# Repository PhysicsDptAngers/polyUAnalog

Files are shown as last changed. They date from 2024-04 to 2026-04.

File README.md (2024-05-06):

# polyUAnalog: A Polyphonic Analogic and *Open Source* Synth

## Project Overview

The architecture of polyUAnalog centers around a simple design: a *conductor board* orchestrating multiple *voice boards*. This modular approach allows each board to function independently as a monophonic synthesizer. When combined under the guidance of the conductor board, they form a versatile polyphonic synthesizer capable of operating in various modes:

- **Polyphonic Mode**: Achieve polyphony with up to virtually 120 voices. Our current configuration supports 10 voices of polyphony, tested and functioning seamlessly.
- **Monophonic with Unison and Spread Mode**: For those moments when a single, powerful voice is needed, enhanced with unison and spread capabilities for added depth.
- **Multi-timbral Mode** (Under development as of April 2024): Expanding the synth's versatility by allowing multiple timbres to be played simultaneously.

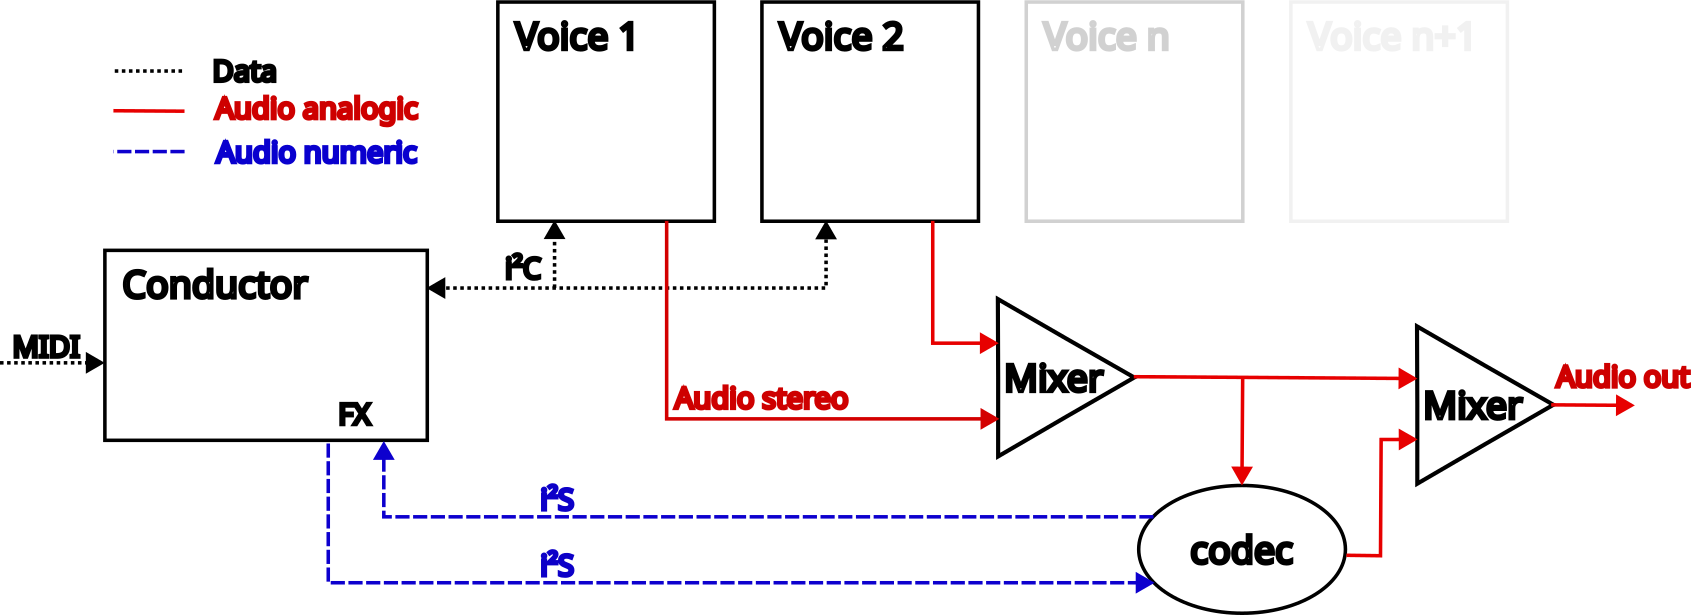
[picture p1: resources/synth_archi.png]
PolyUAnalog Synth


## Repository Structure

The `polyUAnalog` repository is organized into two main directories, `firmware` and `hardware`, each containing subdirectories dedicated to different components of the synth:

### Firmware
Contains all necessary code to bring the polyUAnalog to life. This includes the microcontroller programming for voice and conductor boards, as well as the controller interface.

- **Voice Board**: The soul of the polyUAnalog's sound, each voice board is an independent monophonic synthesizer.
- **Conductor Board**: The brain behind the operation, orchestrating the voice boards to work in harmony.
- **Controller**: Interface and panel design for hands-on control of the polyUAnalog.

### Hardware
Detailed schematics, PCB designs, and everything required to physically construct the polyUAnalog synth.

- **Voice Board**: Designs and instructions to build each monophonic voice board.
- **Conductor Board**: The blueprint for constructing the central conductor board.
- **Controller**: Panel design and schematics for the physical user interface.

For specific details on each component, please refer to the corresponding `README.md` file within its directory. Our aim is to make the assembly and understanding of the polyUAnalog as accessible as possible.

## Contributing

polyUAnalog thrives on community input and collaboration. Whether you're a seasoned electrical engineer, a software developer with a knack for DSP, or an enthusiast eager to learn and explore, your contributions are welcome. 

## Academic Research and Publications

We have documented our journey and findings in a comprehensive academic paper. This paper delves into the theoretical underpinnings, design choices, and technical challenges encountered during the development of polyUAnalog. While the paper is currently in draft form and distributed as-is, we believe it provides valuable insights into the project's scientific and engineering aspects.

A DOI and access to the official publication will be provided upon acceptance. Additionally, a pre-print version of the paper will be made available to ensure our findings are accessible to the community, fostering further research and development in the field of analog synthesis.

## Sound Examples

We are currently compiling a diverse range of audio samples to showcase the versatility and musicality of polyUAnalog. This is a work in progress, and we appreciate your patience as we curate a collection that truly represents the essence of this project.

Stay tuned for a SoundCloud link, which will be shared here soon. 

## Project Progress

| Task | Description | Status |
|---|---|---|
| Documenting | Drafting an explanation of the synth's electronics and detailing the functionality of the code. | #c5f015 In Progress |
| Multitimbral | Add multitimbral capability by adapting the software.  | #00FF00 Almost OK ! |
| Faster PID | Transitioning from the hardware RC-based Timer of the RP2040 to the PIO ones to achieve a faster response time of the DCO waveform. | #f03c15 Testing |
| Conductor board | Design and finalize the electronic, PCB, and firmware layout for the conductor board, which enables the control of voice cards, connects to an FX board, and one or multiple controllers.| #1589F0 Pending |
| FX Loop | Testing the V4220 codec chip.| #1589F0 Pending |
| Controler | Finishing the first controler : the "basic synth" | #1589F0 Pending |
| Continous waveform for the DCO | Produce waveform in between saw and triangle and modulate it | #1589F0 Pending |
| Finishing the paper | Last measurements still to be done | #1589F0 Pending |

## License

polyUAnalog is open source and distributed under the MIT License.

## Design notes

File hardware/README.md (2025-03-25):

## Hardware Components of the polyUAnalog System

- **Voice Board**: This is the core component of the project. A voice board is, by itself, an analog monophonic synthesizer. In short, the sound is generated by the AS3397 chip, controlled by an RP2040/RP2530 (Raspberry Pi Pico) microcontroller.

- **Conductor Board**: All voice boards are connected to the conductor board. It receives commands from external sources in MIDI-compatible format and distributes them to the voice boards via the I²C bus.

- **Controller Board**: These are the interface panels of the synthesizer. They typically include potentiometers, encoders, LEDs, and screens used to program and control the synthesizer. The corresponding data is sent to the conductor board via the I²C bus.

- **Power Board**: The synthesizer requires three power rails to operate (+12V, +5V, -5V). We provide a simple design using a USB Type-C power block with Power Delivery support to supply a regulated +12V rail. The +5V and -5V rails are then generated using buck converters.

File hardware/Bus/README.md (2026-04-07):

# BUS Card

## Overview
The **BUS Card** is the interface designed to link multiple voice boards to the Conductor module. 

- **Capacity:** Each BUS board supports up to 4 voice boards.
- **Mounting:** Voice cards are mounted vertically to optimize space.

## Connectivity & Expansion
You can daisychain multiple BUS boards using two different methods:
1. **Ribbon Cable:** Use a standard 2x5 (2.54mm pitch) connector, similar to Eurorack power cables.
2. **Tiling:** Align the boards side-by-side and solder the dedicated edge pads for a rigid connection.

## Input Connector
The pinout and format of the input connector are detailed in the following diagram:

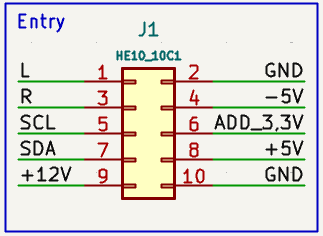
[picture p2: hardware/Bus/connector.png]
Connector Pinout


## I2C Addressing
The I2C address is determined by the voltage level at the `ADD_3.3` pad. 

To configure the addressing:
- Install resistors in series between each card.
- Connect the resistor pin of the first card to **GND** (Ground) to complete the voltage divider.
- The resulting voltage drop across the chain assigns a unique hardware address to each board.

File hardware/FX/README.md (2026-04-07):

## FX Board

We designed an optional, dedicated FX card based on the **RP2350** microcontroller to handle digital effects. This board connects to the conductor board via a standard 2x5 pin header. Audio input and output data transfer relies on the **I2S protocol**, implemented utilizing the RP2350's Programmable I/O (PIO) blocks.

To accommodate different budgets and assembly constraints, the card supports three ADC and DAC configurations:

* The first approach uses the RP2350's **built-in ADC** paired with a $2 \times 8$-bit PWM-RC filtered DAC for the output.
* The second option employs inexpensive, off-the-shelf **I2S ADC (PCM1808) and DAC (PCM5102A)** modules. While we have included the footprints on the PCB to allow for discrete mounting or to future-proof against discontinued supply, we strongly recommend using the modules themselves.
* The third configuration integrates the **Coolaudio V4220 codec**. This recent and cost-effective chip comes in an SSOP-28 package, making it significantly easier to hand-solder than the QFN packages typical of modern audio codecs. It is worth noting that the V4220 datasheet is poorly documented, as it confusingly mixes specifications from the original Cirrus Logic CS4220 and CS4221 chips it is based on.

PCM5102a I2S DAC Module
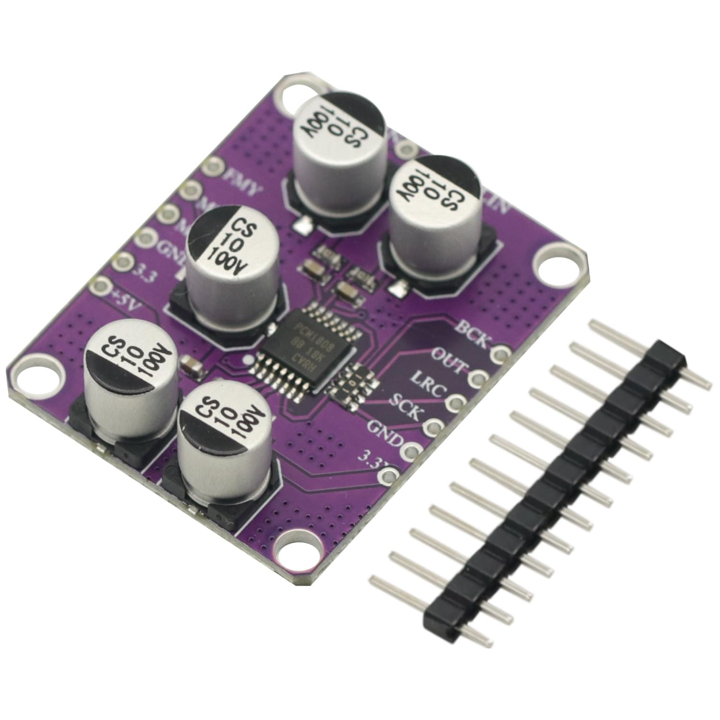
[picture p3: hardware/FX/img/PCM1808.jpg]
PCM1808 I2S ADC Module


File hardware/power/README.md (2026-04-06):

## Power Supply Architecture

The synthesizer requires three voltage rails for proper operation:

- **+12V** rail for the AS3397 chip  
- **+5V** rail for the microcontrollers, various digital ICs, and as the positive supply for the operational amplifiers (OpAmps)  
- **−5V** rail required by the AS3397 and as the negative supply for the OpAmps  

Several strategies have been considered for implementing the power supply. 

In the proposed design, we use a USB-C power supply unit that supports Power Delivery (PD) mode to provide a stable 12V/5A rail. 
	
A buck converter based on the TPS5430 chip, that can easily be obtained as an affordable off-the-shelf module, is used to generate the \SI{+5}{\volt} and \SI{-5}{\volt} rails. With a \SI{3}{\ampere} capacity, this setup is more than sufficient to power both the conductor board and the various voice boards.

Alternative configurations have also been explored:

- In early prototypes, a **compact ATX power supply** was used for +12V and +5V in combination with a **7805** regulator to generate the −5V rail.  
- In the **monophonic version**, the system is powered from a **standard 12V wall adapter** (or a USB-C PD unit), with a 7805 regulator providing the +5V rail, and **charge-pump circuits** used to derive the −5V rail.

Other solutions, such as **off-the-shelf AC-DC modules** from manufacturers like **Meanwell**, may also be considered for increased robustness and ease of integration — particularly when direct connection to the mains is desirable.

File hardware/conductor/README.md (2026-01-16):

# Conductor Card

The *Conductor Card* serves as the central hub for the synthesizer, managing communication, power distribution, and analog signal summing. Its architecture is designed to interface external controls with internal voice modules.

## Key Functionalities

### 1. Data I/O & Connectivity

The card manages multiple communication protocols to interface with the outside world:

* **MIDI:** Standard MIDI IN port and an optional MIDI OUT header.
* **I2C**:
	* Dedicated header for optional *"Controllers"* (e.g., a front panel equipped with knobs and sliders for real-time parameter control).
	* Dedicated header for optional *"FX card"*
* **Wireless (UDP):** Support for UDP over Wi-Fi when utilizing a *Raspberry Pi Pico 2 W*.
* **Storage:** Integrated SD card slot for storing and retrieving presets and system data.

### 2. Voice Dispatch & Power Distribution

The Conductor Card serves as the central interface for system data and power management:

* **Power Input:** Features a dedicated input port for the main power rails (*+12V, -12V, +5V*).
* **Power Routing:** Distributes stable power rails from the main input to all connected internal modules and voice cards.
* **Signal Dispatch:** Routes digital control data—including **Note On/Off, MIDI CC, and Clock** signals—to the individual voice cards via the *I2C bus*.

### 3. Analog Signal Processing & Mixing

The card features a dedicated analog summing stage to consolidate the synthesizer's output:

* **Current-to-Voltage Conversion:** Collects the current outputs from the *AS3397-based voice cards* via a Trans-Impedance Amplifier (TIA).
* **FX Integration:** Bi-directional interfacing with an optional FX card (Send/Return or post-summing injection).
* **Final Mix:** Sums the voice signals with the FX return to produce the final audio output.

## Connectors Pinouts

### 1. Voice Connector (J13)
Single row header (1x9).

```text
┌───┬───┬───┬───┬───┬───┬───┬───┬───┐
│ 1 │ 2 │ 3 │ 4 │ 5 │ 6 │ 7 │ 8 │ 9 │
└───┴───┴───┴───┴───┴───┴───┴───┴───┘
  │   │   │   │   │   │   │   │   │
  │   │   │   │   │   │   │   │   └─ -5V
  │   │   │   │   │   │   │   └───  +3.3V (for i2c Address)
  │   │   │   │   │   │   └───── +5V
  │   │   │   │   │   └─────── GND
  │   │   │   │   └───────── +12V
  │   │   │   └─────────── I2C_Voices_SDA
  │   │   └───────────── I2C_Voices_SCL
  │   └─────────────── Audio_Analog_Right
  └───────────────── Audio_Analog_Left

```

### 2. Power Input (J7 - Conn_POWER)

Dual row header (2x10).

```text
       ┌───────────┐
   -5V │ 1       2 │ GND
   GND │ 3       4 │ +5V
   GND │ 5       6 │ +12V
   GND │ 7       8 │ GND
   GND │ 9      10 │ GND
       └───────────┘

```

### 3. I2C Controller (J15)

Single row header (1x4).

```text
  ┌───┬───┬───┬───┐
  │ 1 │ 2 │ 3 │ 4 │
  └───┴───┴───┴───┘
    │   │   │   │
    │   │   │   └─ GND
    │   │   └─── +3.3V
    │   └───── I2C_CTRL_SDA
    └─────── I2C_CTRL_SCL

```

### 4. FX Connector (J9/J10)

Dual row header (2x10).

```text
       ┌───────────┐
  Dry_L│ 1       2 │ I2C_CTRL_SCL
  Wet_L│ 3       4 │ I2C_CTRL_SDA
  Dry_R│ 5       6 │ -5V
  Wet_R│ 7       8 │ +12V
    GND│ 9      10 │ +5V
       └───────────┘

```

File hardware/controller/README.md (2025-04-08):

## Controller Board

The controller board serves as the equivalent of a synthesizer’s front panel.

For now, we provide a very basic frontend for a subtractive synthesizer. It is more of a demonstration of what can be done than a de facto standard. You can, in principle, design any frontend you like.

The controller board must send its data in MIDI format over the I²C bus to the conductor board.

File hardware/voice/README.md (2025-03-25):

# Monophonic Synth Based on the AS3397 Chip: The Voice Board

These PCBs allow the generation of *one* analog audio voice using the AS3397 chip, controlled by an RP2040/RP2530 (Raspberry Pi Pico) microcontroller.

## Hardware

We offer three different circuit designs:

- **Main (SMD 1206)**: This is the reference board, designed to be controlled by the *conductor board* along with other voice boards to form a polyphonic synthesizer. It uses relatively large *SMD 1206* (Surface-Mounted) components, which can be soldered by hand with some practice.
  
- **Eurorack (SMD 0603) – WIP**: Designed for use with the *Eurorack version of the conductor board* (work in progress as of March 2025). As with all Eurorack modules, space is limited, so this board uses small **SMD 0603** components. While it can be soldered by hand, it requires some experience and possibly dedicated tools like a binocular magnifier.

- **Mono Through-Hole – WIP**: The simplest version to assemble and arguably the best starting point. This is a *standalone* analog voice module that does *not* require a conductor board to generate sound. Additionaly, the board is large and use trhough-hole component (except for the as3397 chip). It also includes a dedicated *MIDI input socket* and *power circuitry*, allowing you to simply connect a MIDI cable and a *+12V power supply* to get a fully functional monophonic analog synthesizer!

## The AS3397 Chip

The AS3397 chip is manufactured by ALFA RPAR, a Latvian semiconductor manufacturer. It's a modern reissue of the CEM3396, a chip that found its home in iconic synthesizers like the Oberheim Matrix-6. 

[Datasheet AS3397](datasheet/AS3397.pdf)

## Sonic Possibilities of the AS3397

### Voltage-Controlled Oscillators (VCOs)

At the heart of the AS3397's sound generation capabilities are two Digital Controlled Oscillators (DCOs), which offer a range of sonic textures from saw waves to clipped triangles thanks to the wave shaper that allows for dynamic waveform manipulation. Additionally, the module can mix square waveforms from both DCOs.

In a nutshell:
- **Dual VCOs**: Specifically, two DCOs, which means the voltage ramp is created by charging a capacitor with a constant current.
- **Wave Shaping**: Converts the sawtooth waveform of the DCO into triangle, clipped triangle, and variations in between.
- **Comparator**: Utilizes the voltage ramp from the DCO to create square waves that are mixed with the output from the wave shaper.
- **Quad Level Driver**: Chooses whether or not to use the output from the DCO.
- **Balance Control**: Allows adjustment of the balance between VCO A and VCO B.

The VCO is arguably the most complex part of the AS3397 to understand. [Here is a link to a detailed explanation of the VCO's operation, outlining its operating principles, the electronics involved, and the connections to the firmware code](doc/VCO.md).

### External Signal Addition

The AS3397 chip allows for the integration of an external audio signal. This a new feature compared to the CEM3396.

### Voltage-Controlled Filter (VCF)

The VCF is a resonant 4-pole low-pass filter that can quite easily auto-oscillate.

For a comprehensive exploration of the Voltage Controlled Filter (VCF) used in the AS3397, please [visit the detailed documentation page](doc/VCF.md).

### Voltage-Controlled Amplifier (VCA)

The AS3397 features a stereo Voltage Controlled Amplifier, which generates a current that must be converted into a corresponding voltage through a "transimpedance" circuit, typically one utilizing an Operational Amplifier (OpAmp). The stereo part of the VCA is a new addition of the AS3397 that was not present in the CEM3396.

## Driving the AS3397 Chip with an RP2040 (Pi Pico)

The integration of the AS3397 chip with the RP2040 microcontroller, particularly through the Pi Pico board, forms the backbone of our voice module's functionality. 

### Discharge Pulse Generation for DCO

The RP2040 plays a crucial role in generating discharge pulses for the Digital Controlled Oscillator's (DCO) capacitor. This ensures the oscillator's frequency stability and precise pitch control, a testament to the seamless integration between analog sound generation and digital control.

### Managing Control Voltages

To fully harness the capabilities of the AS3397, managing numerous control voltages is imperative. Specifically, the chip requires management of 10 control voltages. While employing a Digital to Analog Converter (DAC) and multiplexers could achieve this, such a setup complicates the assembly and increases the overall cost. Instead, we opted for a more efficient approach, utilizing the RP2040's Pulse Width Modulation (PWM) outputs. These outputs are filtered through a low-pass filter to retain only the DC component, ensuring minimal ripple and response times that are well-suited for audio applications. The cut-off frequency of the filter has been meticulously chosen to balance between reducing ripple and maintaining an appropriate response time.

For an in-depth analysis of filtered PWM, including detailed mathematical and technical discussions, please [visit the dedicated page](doc/PCM_CV.md).

### Dynamic Ramp Voltage Control in DCO

Controlling the ramp voltage amplitude within a DCO presents its challenges. Our not so common approach involves continuously sampling the maximum voltage of the DCO's capacitor ramp using the RP2040's Analog to Digital Converters (ADCs). We then dynamically adjust this value using a digital Proportional-Integral-Derivative (PID) feedback loop, ensuring consistent DCO amplitude across different frequencies and hence the same waveform at the exit of the waveshaper.

### Digital Signal Oscillator (DSO)

The second core of the RP2040 is dedicated to generating an audio signal, functioning as a Digital Signal Oscillator (DSO). This digital audio signal is mixed with the analog signal from the AS3397 before reaching the Voltage-Controlled Filter (VCF), enriching the synthesizer's sonic palette.

### Voltage Level Shifting

Considering the AS3397 chip was designed in the 1980s to operate at +5V, while the RP2040 outputs 3.3V, level shifting is necessary. We've implemented level shifters to convert the 3.3V from the RP2040's PWM outputs to the 5V required by the AS3397, ensuring compatibility without sacrificing signal integrity.

### Control Voltage Scaling

For certain control voltages of the AS3397 that can accept broader ranges, we've employed operational amplifiers (Op-Amps) to scale the 0-3.3V output from the RP2040 to the required range. This approach allows for full utilization of the AS3397's control parameters without introducing unnecessary complexity.

### Power Supply

The power supply requirements (+12V, -5V for the AS3397, and +5V for the Pi Pico) are provided externally, for instance, by the conductor board. The Pi Pico employs its internal buck-boost converter to generate the appropriate operating voltage for the RP2040, streamlining the power management across the module.

### External Information Transfer via I²C

The transfer of information from external sources to the RP2040, which in turn controls the AS3397, is facilitated through the I²C bus emulating the MIDI protocol. This setup enables comprehensive control over various musical aspects, including note management (both 'note on' and 'note off'), velocity, aftertouch, control changes (MIDI CC), among other parameters. To surpass the traditional MIDI protocol's limitation of 127 levels, extended MIDI functionality has been integrated, providing greater nuance and control.

A interesting feature of our system is the automatic addressing of each voice board upon the conductor board's startup. Specifically, a voltage, derived by dividing the 3.3V generated by the conductor board and uniquely distributed to each voice board, is measured by the third ADC of the voice board's RP2040. This process assigns a specific I²C channel to each voice board, enabling precise and individualized control. At initialization, the conductor board scans all the connected I²C ports, thus determining the total polyphony capability of the synthesizer, seamlessly integrating hardware and digital controls.

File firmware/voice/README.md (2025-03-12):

# Firmware for One Voice Board

## What is a Voice Board?

The synthesizer is mainly composed of three types of circuits:
- The **conductor board**, which receives MIDI instructions from external sources and distributes them to the voice board.
- The **controller board**, which serves as a user interface for sending MIDI instructions (via an I²C bus) to the conductor board.
- The **voice board**, which is an analog monophonic synthesizer that can function, to some extent, autonomously.

### What Does a Voice Board Do?

A voice board receives MIDI instructions from the conductor board via the I²C bus. Its primary function is to generate the corresponding monophonic analog voice using the AS3397 chip. Everything is coordinated by an RP2040/RP2530-based Raspberry Pi Pico microcontroller.

### What's Inside a Voice Board?

The two main components are the **AS3397 chip** and the **Raspberry Pi Pico microcontroller**. Of course, there are additional electronic components, but detailed knowledge of them is not necessary for working on the firmware. For more technical details on the hardware, see [relevant documentation or section].

# List of Files and Overview of Their Functions

In the near future, all files will be extensively commented and will have dedicated Doxygen documentation.

[📚 View the documentation (WIP)](docs/html/index.html)

- **`voice.ino`**: The main file that integrates all auxiliary files to fetch MIDI data from the I²C bus and send the correct voltage to the AS3397 chip.
- **`as3397.h` / `as3397.cpp`**: This class represents the interface with the AS3397 chip. For instance, the chip requires ten control voltages for configuration, which are generated using PWM signals from the RP2040 microcontroller. As a result, this class contains 10 (+4) PWM members. This is the most complex file to understand, as it is closely tied to certain hardware-specific aspects of the AS3397 chip.
- **`ADSR.h` / `ADSR.cpp`**: A basic implementation of an Attack-Decay-Sustain-Release (ADSR) envelope. Nothing special.
- **`LFO.h` / `LFO.cpp`**: A basic implementation of a Low-Frequency Oscillator (LFO), optimized for computational efficiency.
- **`DSO.h` / `DSO.cpp`**: The Digital Signal Oscillator (DSO) class and instructions. The AS3397 chip has an external input just before its analog filter, where the chip's analog oscillator is mixed with a digital signal generated by the RP2040 microcontroller (see **X** for more technical details). Currently, the DSO functions as a relatively simple wavetable synthesizer, but it could be easily extended (see **X**).
- **`Synth.h`**: This file instantiates and initializes the **AS3397**, **LFO**, **ADSR**, and **DSO** objects. It also contains the `updateCtrl` and `updateAudio` callback functions, which are automatically called using two timers on the RP2040 (see `voice.ino`).  
  - The **`updateCtrl`** callback, called at **CONTROL_RATE** Hz (typically **500 Hz**), updates the LFO and ADSR values and sends them to the AS3397 object to adjust sound generation.  
  - The **`updateAudio`** callback, called at **AUDIO_RATE** Hz (typically **62,500 Hz**), calculates the new output value of the DSO and sends it to the AS3397 object to update the DSO.

  This file specifically defines some important global variables:
  ```c
  As3397 as(AUDIO_RATE);
  LFO lfo1(CONTROL_RATE);
  ADSR eg1(CONTROL_RATE);
  ADSR eg2(CONTROL_RATE);
  DSO dso(AUDIO_RATE);
  ```
  Additionally, several other global variables are defined to manage various synthesizer parameters, such as `freqA`, which stores the current frequency of analog oscillator A.

- **`Midimanager.h`**: Handles MIDI messages, decodes them, and modifies the corresponding synthesizer parameters.
- **`midicontrol.h.oxy`**: Defines the MIDI CC numbers assigned to each parameter.
- **`led.h` / `led.cpp`**: Provides basic feedback using the onboard LED of the Pi Pico board.
- **`aspin.h`**: Defines the pin connections between the AS3397 chip and the RP2040. This is entirely hardware-dependent and should not be modified unless the corresponding hardware connections on the voice board have also been changed.
- **`tables.h`**: Contains raw wavetable data for the DSO.

# How to Compile the Firmware?

# Modifying the Firmware: Where to Start?

## Setting Up a Workspace

## Modifying the Synth Structure

Currently, each voice has one LFO and two envelope generators (EGs). 

The LFO is assigned to:
- The filter resonance
- The PWM modulation of the square wave
- The pan

The first envelope is assigned to the general volume. The second envelope is assigned to the filter cutoff.

These are very basic routings for a synth, but more LFOs and EGs could be added with additional modulation destinations and even intermodulation (e.g., an LFO modulating the attack time of an EG).

Other types of modulation could also be integrated, such as step sequencers, random/chaos generators, etc.

### Adding New LFOs and/or EGs:
- Instantiate them in `synth.h`
- Update their behavior in the `synth.h` **updateCtrl** callback  
  _(NB: Beware of circular modulation, where modulator A modulates modulator B while B simultaneously modulates A.)_
- If needed, modify `Midimanager.h` so that MIDI commands can be assigned to this new modulator.

### Creating a New Type of Modulation:
- Create the dedicated `.h` and `.cpp` class.
- Follow the same process as adding a new LFO or EG.

## Modifying the DSO

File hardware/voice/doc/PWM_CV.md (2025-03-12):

# Pulse Width Modulation (PWM) as a Digital-to-Analog Converter (DAC) with Low Pass Filtering
 
## The main idea

Pulse Width Modulation (PWM) is a widely used technique for controlling analog circuits and systems using digital signals, that is to say only capable to produce two voltage values. In PWM, a square wave is generated with a constant frequency, while its duty cycle is modulated to represent the desired control signal.     

Taking the average value of a PWM signal can be used to create a Digital-to-Analog Converter (DAC), as the varying duty cycle directly affects the average output voltage. A practical example of this principle can be seen in LED dimming, where PWM modulation is used to control the intensity of the light. Our persistence of vision serves as the averaging device, as our eyes perceive the time-averaged intensity of the rapidly blinking LED, rather than the individual on and off states. This technique, applied in the ideal case, is illustrated in fig. X, demonstrating how the average value of a PWM signal can be used to create a DAC and control the output voltage.

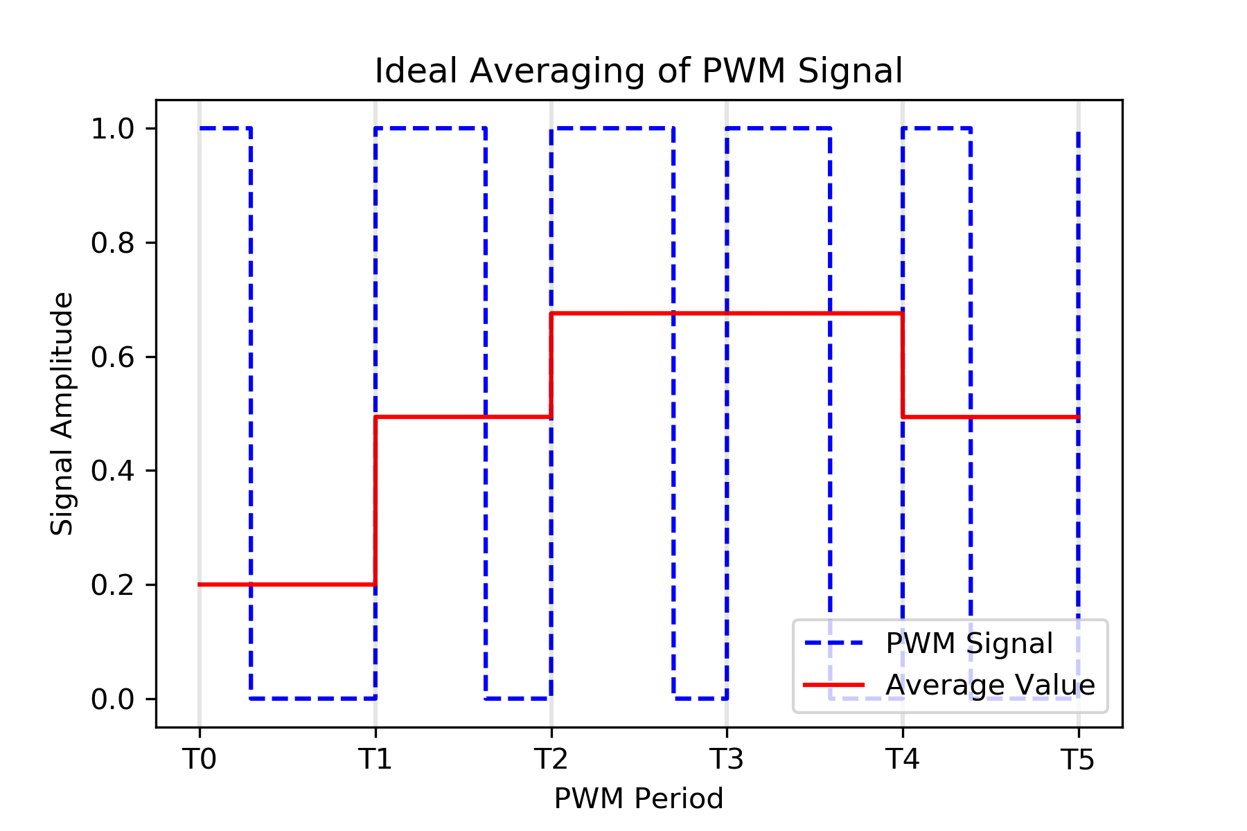
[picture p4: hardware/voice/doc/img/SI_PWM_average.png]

*Figure X Graphics showing that the mean value of a PWM signal *

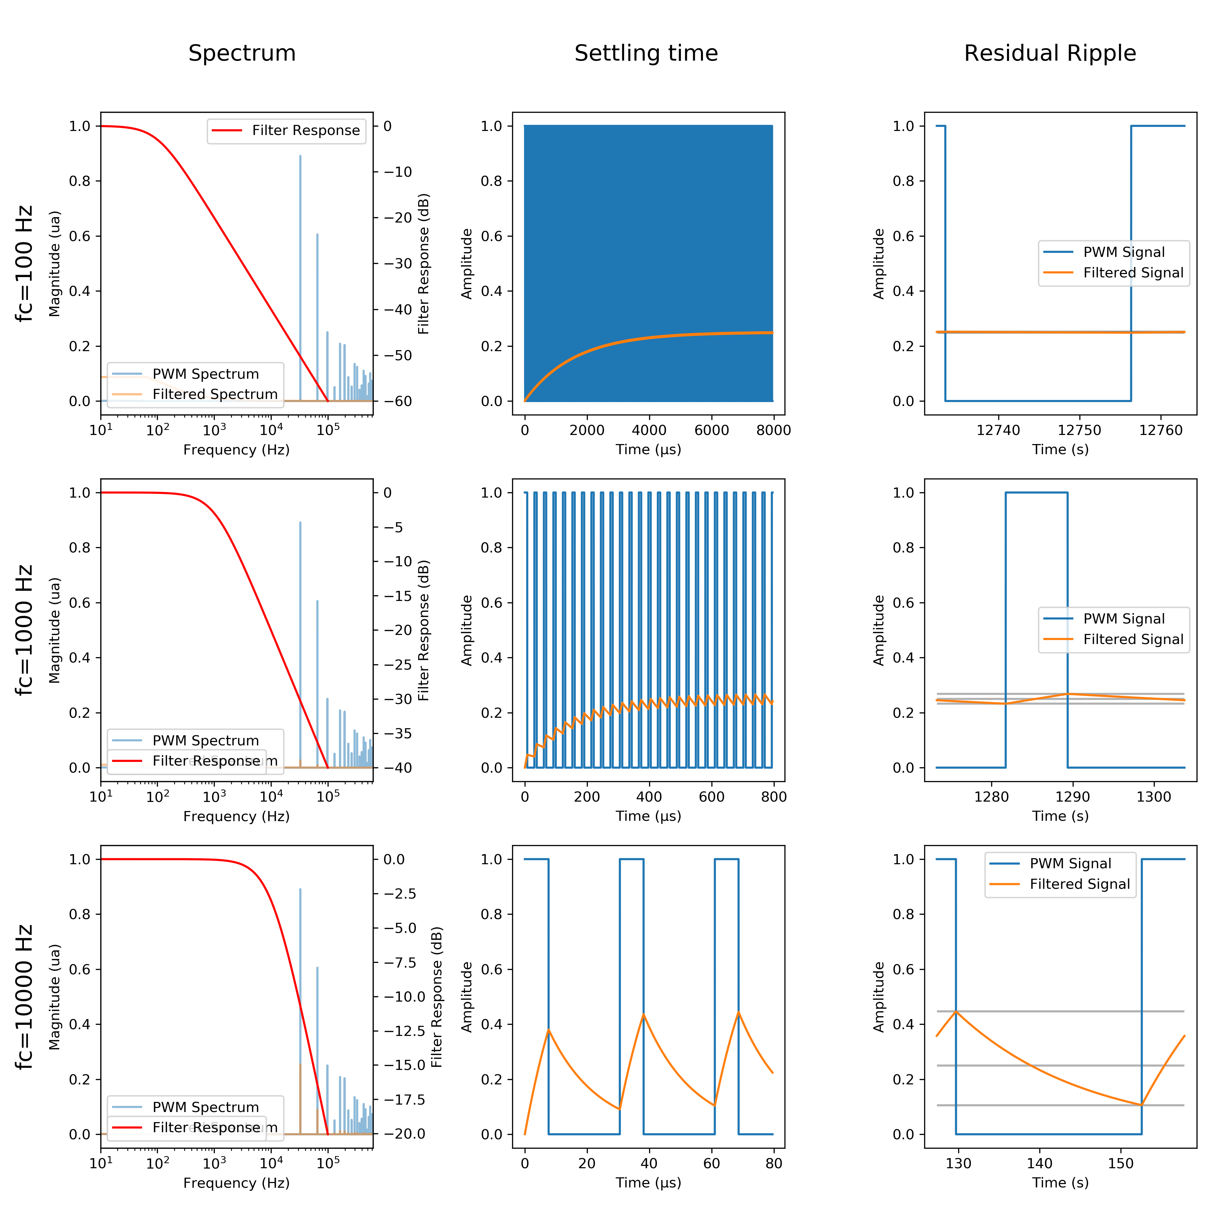
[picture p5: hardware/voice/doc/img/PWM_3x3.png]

*Figure X Graphics showing that the mean value of a PWM signal * 

## Dual PWM

## More maths

## Standard Hardware implementation of PWM

PWM signals are often implemented in hardware using timers and Output Compare Registers (OCRs). A timer is a hardware component that continuously counts up or down at a specific rate based on the input clock frequency. The timer's value resets to the initial value when it reaches the maximum count or overflow.

An Output Compare Register is a hardware register that stores a predetermined value. The timer's value is continuously compared to the value in the OCR. When the timer's value matches the value in the OCR, an output signal is generated, usually in the form of a change in the state of a specific output pin (e.g., from high to low or vice versa). By changing the value stored in the OCR, the duty cycle of the resulting PWM signal can be controlled.

The precision of a PWM signal is ultimately based on time measurement. The resolution of the timer and the input clock frequency determines the granularity of the time measurement, which in turn affects the accuracy and precision of the PWM signal's duty cycle. A higher-resolution timer or a faster clock frequency will result in more precise control over the PWM signal's duty cycle, allowing for a more accurate representation of the desired analog output.

Phase correct Pulse Width Modulation (PWM) and Fast PWM are two commonly used modes for generating PWM signals with different characteristics. The primary difference between these two modes lies in the way the Output Compare Register (OCR) is managed, which affects the PWM waveform.

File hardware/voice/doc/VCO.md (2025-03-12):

# Deep Dive into the VCO Part of the Chip

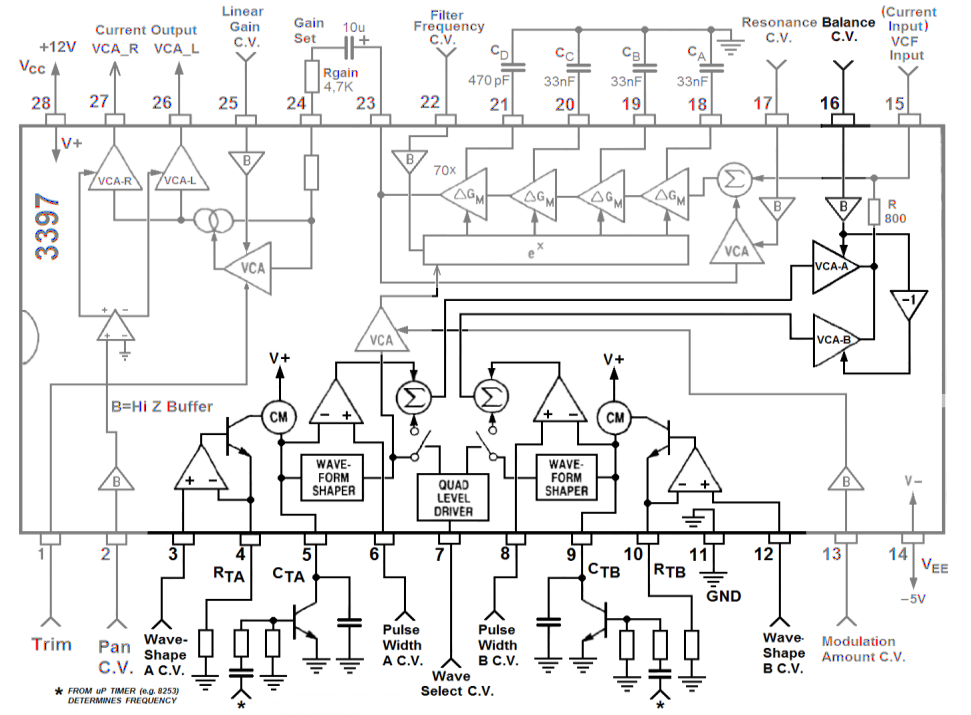
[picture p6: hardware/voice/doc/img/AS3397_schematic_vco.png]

*Figure 1. Schematic Diagram of the AS3397 with Focus on the DCO Section*

## Digitally Controlled Oscillator (DCO)

The AS3397 features two oscillators that are of the DCO type. The operation of this type of oscillator is particularly well described in [Stargirl Flower's blog post on the oscillators of the Juno 6](https://blog.thea.codes/the-design-of-the-juno-dco/).

An oscillator must, almost by definition, produce a periodic signal. Here, it is obtained by charging a capacitor followed by its abrupt discharge. The discharge is triggered by a pulse from a digital circuit (typically a microcontroller in 2024). If the discharge signal is periodic, then the voltage across the capacitor will have the same periodicity, and we indeed have an oscillator.

### Charging a Capacitor with Constant Current

The heartbeat within the oscillator is the charging of a capacitor with charges. Charging a capacitor might spontaneously make you think of an exponential curve that reaches the charging voltage after a time $\tau=RC$. Indeed, this is what happens when the capacitor is charged with a *constant voltage*. The more the capacitor is charged, the more it opposes the increase in its charge until reaching a status quo where the charging voltage equals the voltage generated by the charges accumulated on the capacitor's walls. This would be analogous to filling a water bottle that is upside down (i.e., with a neck pointing towards the ground into which a pipe delivering water comes). As the level rises, the hydrostatic pressure opposes the filling of the bottle until it equals the pressure in the pipe at the entrance of the neck.

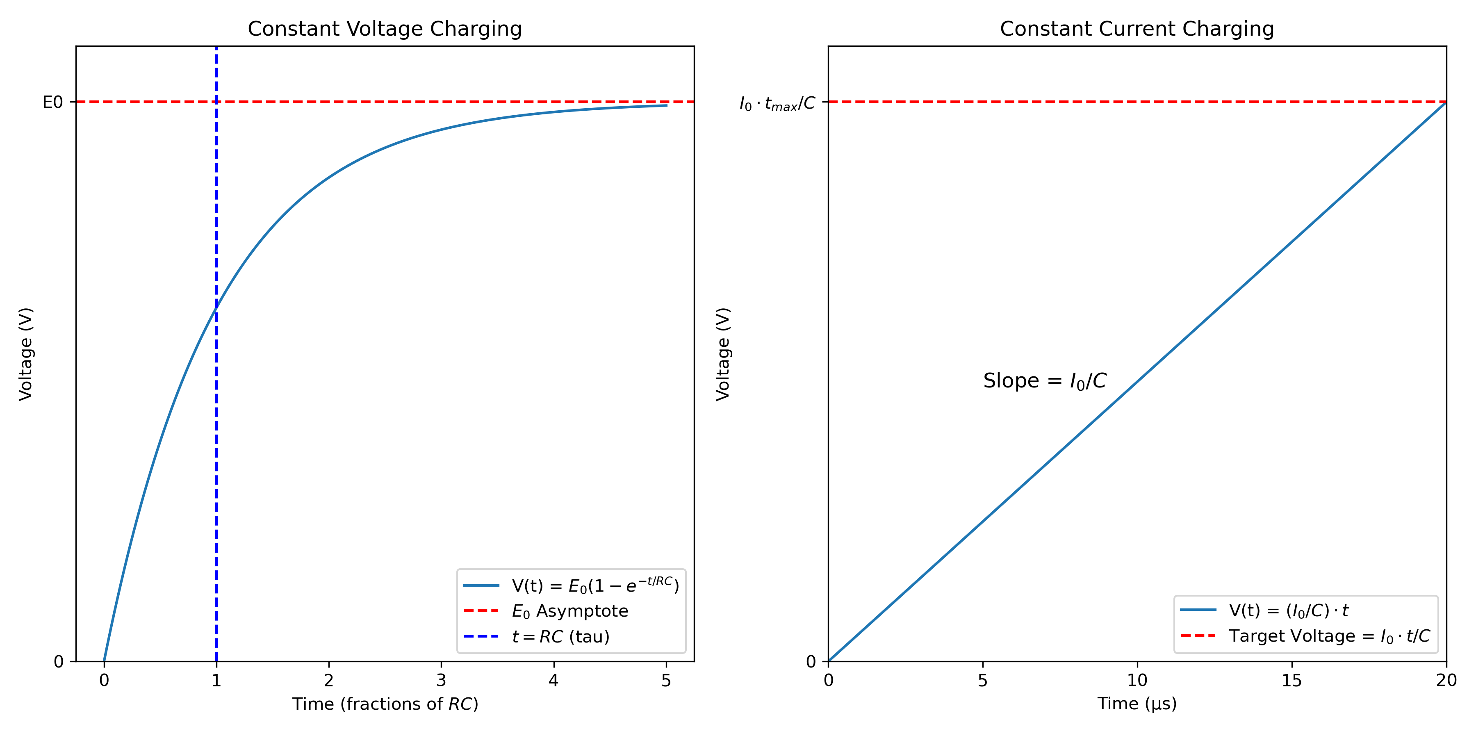
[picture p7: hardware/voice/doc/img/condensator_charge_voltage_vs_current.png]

*Figure 2. Charge of a condensator at constant voltage vs constant current*

Here, the charging of the capacitor is not at constant voltage but at *constant current*. Continuing the analogy started above, this is akin to filling a bottle "normally", i.e., without it being upside down. The water level inside the bottle increases linearly with time since nothing prevents its filling. Returning to the capacitor, when it is charged with constant current, its voltage increases linearly across its terminals. We thus obtain a voltage ramp over time.

#### The AS3397's Current Source

A very classic way to obtain a constant current charge of a capacitor is to include it in a feedback loop of an OpAmp whose linearity condition (V+=V-), forces the current to be constant within the RC series circuit. This is also known as an integrator circuit (you can click on the image to go to circuit.js for a dynamic simulation) :

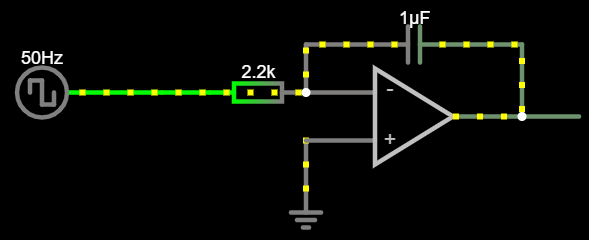
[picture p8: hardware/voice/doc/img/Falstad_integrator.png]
Integrator Falstad (https://www.falstad.com/circuit/circuitjs.html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)


The principle schematic of the AS3397 suggests that the chip uses another system to obtain a current source, namely a transistor placed in the feedback loop followed by a current mirror (CM).

As mentioned earlier, the operational amplifier in its linear regime acts to maintain a constant voltage difference between its inputs (positive and negative terminals). In the context of a current generator, a reference voltage is typically applied to one of the op-amp's inputs (here the + input). Here, this voltage is "WaveShape CV", noted $V_{wf}$ which, as its name indicates, will play a crucial role in controlling the waveform of the oscillator.

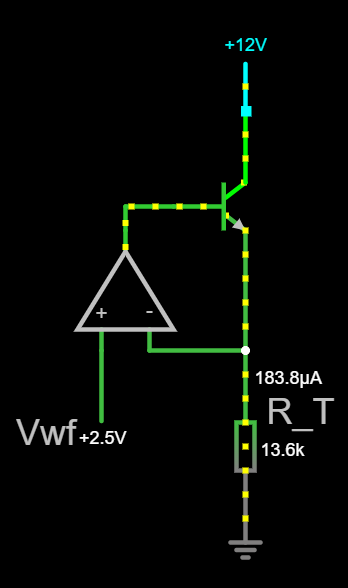
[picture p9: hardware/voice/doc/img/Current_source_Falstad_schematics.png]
Current source Falstad (https://www.falstad.com/circuit/circuitjs.html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)

*Figure X : Schematics of the type of current source used in the AS3397 

The other input of the op-amp, here the - input, is connected to ground via the resistor $R_{T}$, so that the linear operation of the OpAmp forces the voltage across $R_{T}$ to be equal to $V_{wf}$. The current within $R_{T}$, which is also the same as the one that will serve as input to the current mirror, is $I = V_{wf}/R_{T}$.

The OpAmp's feedback loop contains a transistor. More specifically, the OpAmp's output is connected to the transistor's base, and the output voltage of the OpAmp thus controls the current flowing between the base and the emitter. Indeed, the base-emitter part of the transistor (here NPN), behaves like a diode where the base current $I_{B}$ varies exponentially with the base-emitter voltage $V_{BE}$. Furthermore, the collector current $I_{C}$ traversing the transistor, which is the same as the current $I$ traversing $R_{T}$, depends linearly on the base current (via the current gain $\beta$). In total, a modification of the OpAmp's output voltage translates into a modification of the base voltage $V_{BE}$ and thus of the collector current $I_{C}$ which traverses $R_{T}$. The operation of the OpAmp requires the simultaneous achievement of two conditions:
- The voltage across $R_{T}$ must be equal to $V_{wf}$, setting a current $I=V_{wf}/R_{T}$
- The OpAmp's output voltage, which drives the transistor via its base, must be such that the current in the collector also equals $I$

In summary, the choice of the $V_{wf}$ voltage and the $R_{T}$ resistor sets a stable current $I$ that, at least in theory, does not depend on the load in which the current flows. Thus, we are indeed dealing with a current generator. The load is typically placed between the collector and the base of the transistor. The AS3397 uses a current mirror before sending this copy of the current to the capacitor to be charged, so that

##### Explanation of a Current Mirror

The somewhat schematic view of the AS3397 does not allow us to know the exact nature of the current mirror used here. Nevertheless, we can revisit the principle of a current mirror by taking the simplest example: connecting two transistors, T1 and T2 (as identical as possible), in the manner presented in Figure X. Since the two transistors share the same voltage between the base and the emitter, the output current passing through the collector of T2 is the same as the input current passing through the collector of T1.

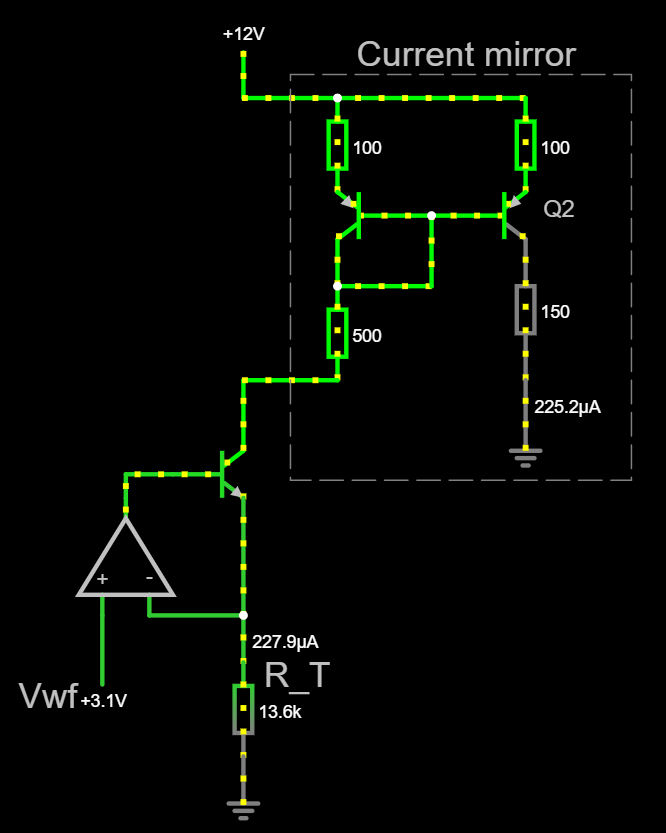
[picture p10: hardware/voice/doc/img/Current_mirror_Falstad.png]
Current source Falstad
[](https://www.falstad.com/circuit/circuitjs.html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)
*Figure X : Schematics of the type of current source used in the AS3397 with a current mirror to copy the current

### Capacitor Discharge

In a DCO, the capacitor must be discharged at a frequency that defines the pitch of the note to be played. The AS3397 follows the traditional scheme, which involves using a transistor acting as a switch controlled by the microcontroller. If the control voltage sent to the base of the transistor is zero, the transistor remains open, and the capacitor charges from the current source. If the control voltage rises to a high level (here 3.3V), the transistor closes, connecting both terminals of the capacitor to the ground, causing it to discharge almost instantly.

The arrangement shown in the AS3397 datasheet includes some additional components. The discharge pulse (symbolized by a star) first passes through a high-pass filter acting as a derivative filter. Indeed, the discharge pulse must have the correct duration, specifically:
- Not too short, to ensure the capacitor fully discharges.
- Not too long, to allow the capacitor to begin charging again as soon as it is empty.

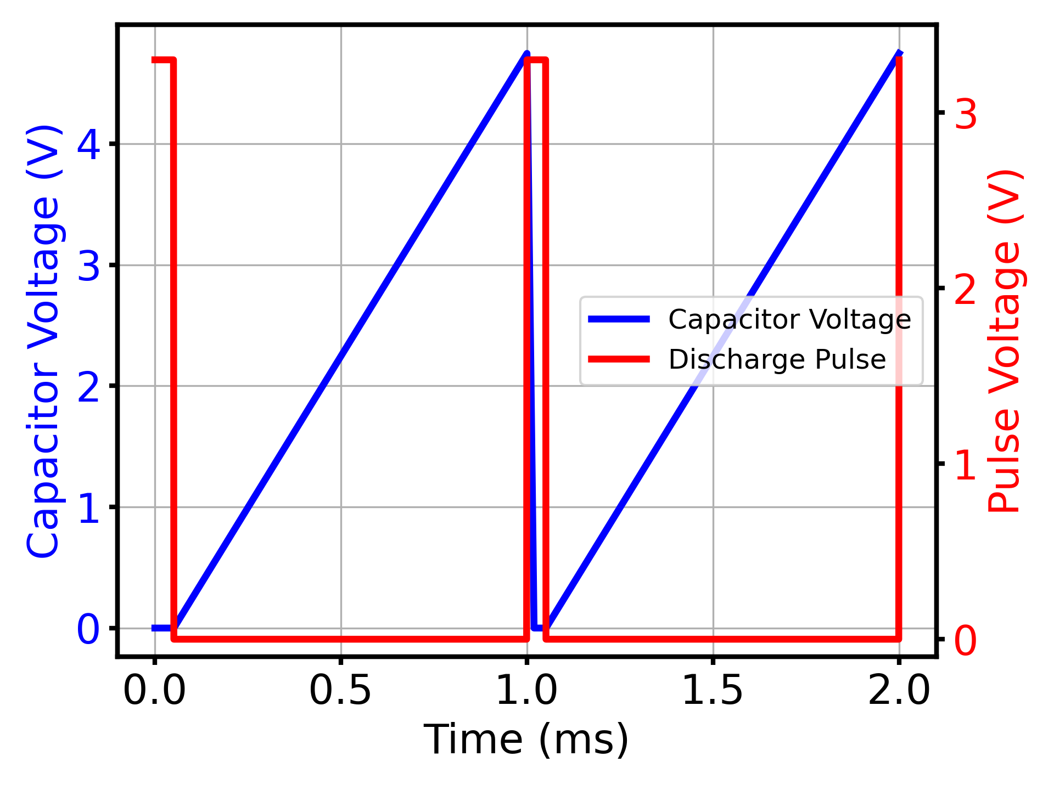
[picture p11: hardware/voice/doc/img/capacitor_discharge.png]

*Figure X: Charging and discharging of the capacitor dictated by the incoming pulse on the discharge transistor. The duration of the discharge pulse has been artificially extended for clearer illustration.*

Typical components from the 1980s produced pulses that were too long, and the derivative filter was intended to create a shorter pulse. Perhaps as a reminder, a high-pass RC filter acts as a differentiator when the frequency of the signal (its fundamental) is much higher than the cutoff frequency. The transfer function is then simply \( H(\omega) = j\omega \), that is, the operation of deriving the signal.

Nowadays, the derivative assembly is no longer very useful because the pulses produced by microcontrollers can be particularly short. For example, with the RP2040 @ 125MHz, pulses can have a duration of 8ns.

After the derivative RC filter, there is a resistor before the base of the bipolar transistor intended to ensure that, given the voltage of the pulses, the base current is sufficient to open the transistor.

In an effort to reduce the number of components, we have chosen to simplify this part of the assembly:
- By removing the derivative part and directly setting the adequate duration of the pulses generated by the RP2040.
- By using a MOSFET transistor instead of a bipolar one, allowing it to be driven directly by voltage and eliminating the need for the bias resistor.

We have chosen the BS170 transistor, which is easy to source, very inexpensive, and especially has a Gate Threshold Voltage (VGS(th)) of about 2V, which is below the 3.3V, ensuring that the 3.3V pulses from the RP2040 can trigger its opening.

Note that the resistance of the BS170 when open (Static Drain−Source On−Resistance, typically noted as RDS(ON)) is not negligible and is about 1.5 Ohms here. This should be taken into account during the discharge of the capacitor and makes this process less instantaneous. Figure x shows the time required for the total discharge of the capacitor. This figure also indicates that the duration of the pulse fully allows the capacitor to discharge completely, even considering the increased time due to this residual RDS(ON) resistance.

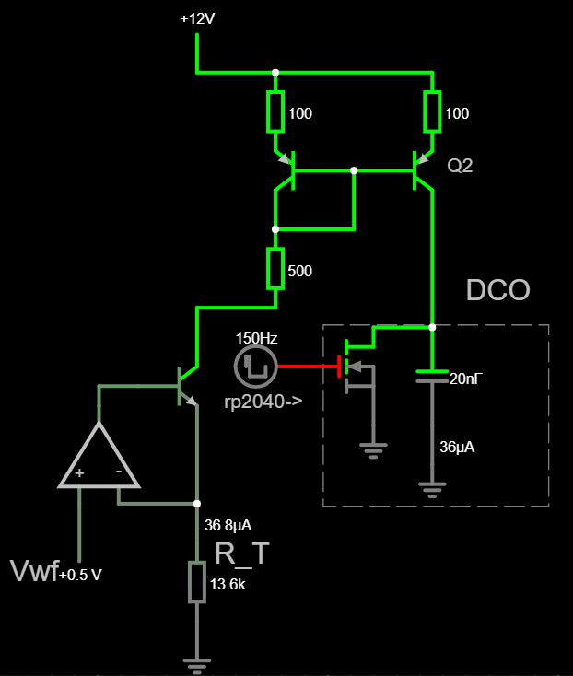
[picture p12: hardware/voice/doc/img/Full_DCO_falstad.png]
Full capacitor charge AS3397
[](https://www.falstad.com/circuit/circuitjs.html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)
*Figure X : Schematics of a DCO of the AS3397 with the current source, its current mirror and the charge capacitor discharged by an impulsion coming from the micro-controler sent to a transistor

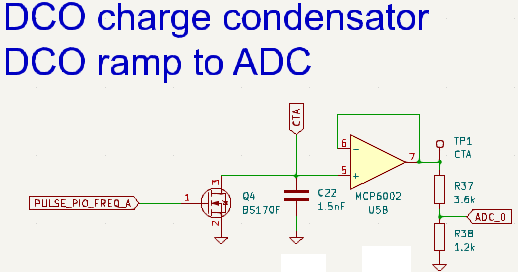
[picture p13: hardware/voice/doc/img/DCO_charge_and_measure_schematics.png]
dco capacitor discharge schematics

*Figure X: Schematics of capicitor discharge of the DCO (and the measure of the corresponding ramp voltage)*

## Wave Shaper and Waveform Control

As previously mentioned, the DCOs allow for a perfectly fixed frequency (without the need to worry about the exponential voltage-to-frequency converters, as this is managed by software in the microcontroller). However, this introduces a challenge: the amplitude of the voltage ramp generated depends on the frequency. Indeed, the capacitor's charge time for low frequencies is longer than for high frequencies. Thus, all else being equal, the voltage reached by the ramp—and consequently, the volume of the VCO is higher at lower frequencies than at higher frequencies.

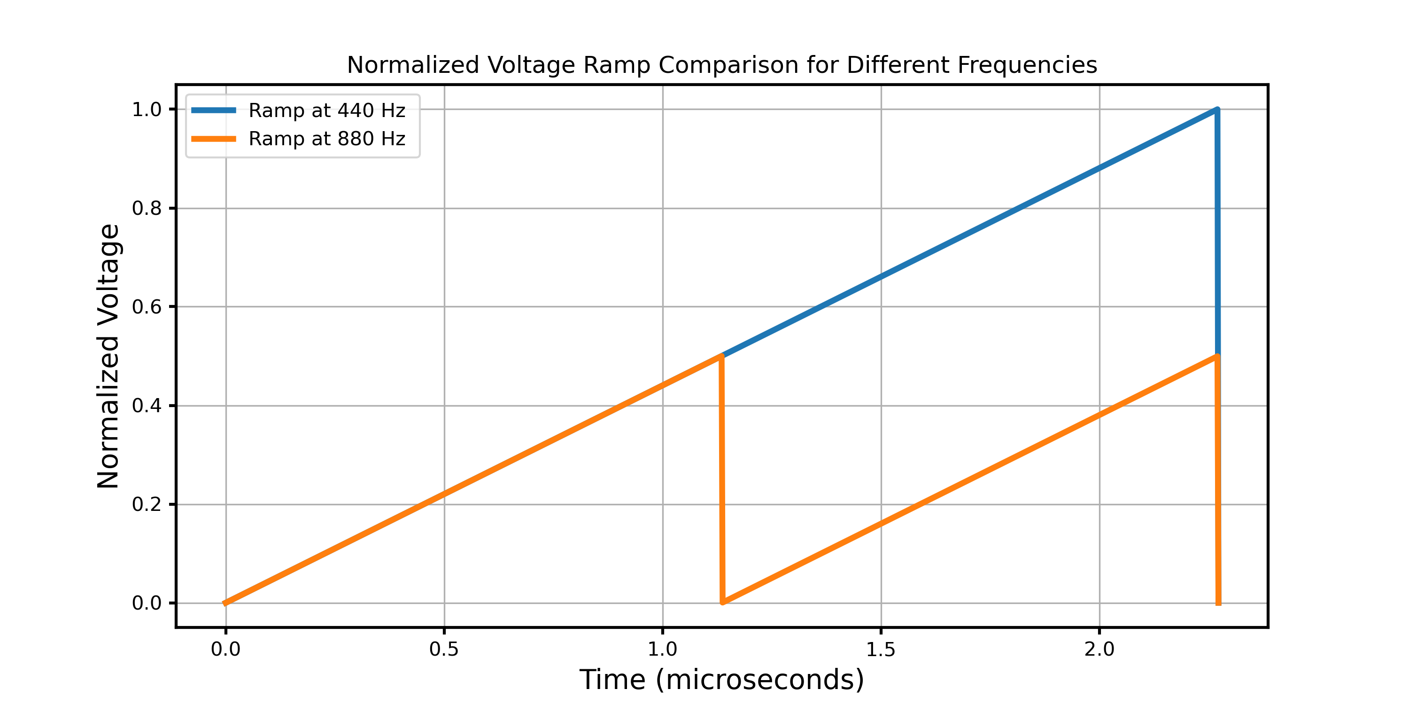
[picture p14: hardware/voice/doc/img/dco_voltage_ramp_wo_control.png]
dco Ramp voltage uncompensated

*FigX : Voltage at he charging condensator for two different frequencies (440Hz and 880hZ). At low frequency, the condensator has more time to charge and consequently the ramp will reach a higher voltage.*

This problem is particularly critical because, in the AS3397 chip, the voltage ramp passes through a wave shaper circuit to provide a broader range of waveform shapes.

### Description of the Wave Shaper

For now, setting aside the management of the ramp amplitude, let's focus on the wave shaper. The datasheet does not describe its internal components but provides an operational summary which is illustrated in Figure X for a supply voltage of 12V to the AS3397.

For lower ramp voltages, the wave shaper behaves linearly, and the output waveform remains a sawtooth. For voltages between XV and YV, the wave shaper reverses the direction of the ramp, resulting in a complete rising ramp followed by a portion of a descending ramp. At a ramp voltage of ZV, the descending part lasts as long as the ascending part: we obtain a triangular wave. For ramp voltages above ZV, the wave shaper transforms it into a zero voltage. Thus, the output waveform is what the datasheet describes as a "clipped" triangle. Beyond ZV, the zero-voltage portion of the waveform increases, and we approach a pulse.

Controlling the maximum ramp voltage output from the capacitor leads to two requirements:
- It must be the same for all frequencies, otherwise, the waveform (i.e., the timbre) will not be the same from one note to another.
- The maximum ramp voltage of the capacitor must be adjusted to achieve the desired waveform output from the wave shaper.

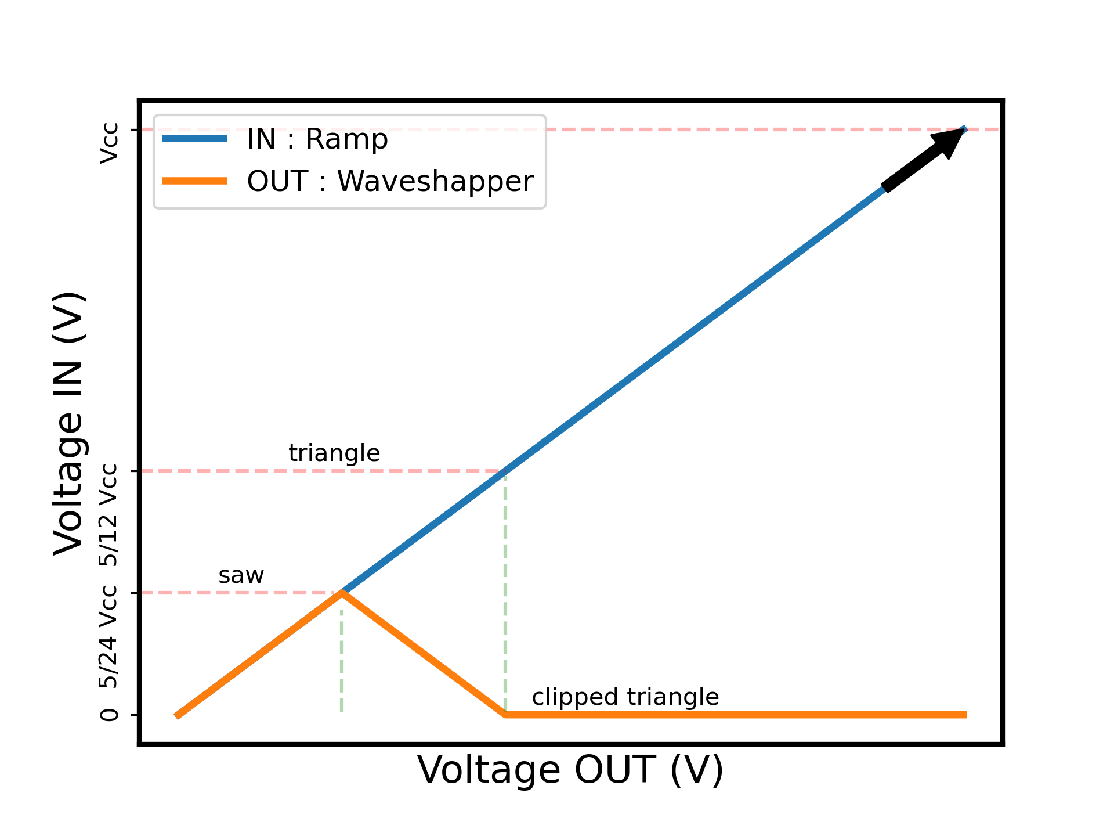
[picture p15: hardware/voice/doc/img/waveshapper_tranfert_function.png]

*Figure X: Transfer function of the wave shaper. If the maximum \( V_{\text{ramp}} \) of the ramp voltage at the capacitor is lower than \( \frac{5}{24} V_{\text{cc}} \) (here 2.5V), the waveform is a saw. Between 2.5V and 5V, the waveform transitions from a saw to a triangle. At 5V, the waveform is a triangle. For \( V_{\text{ramp}} \) greater than 5V, a clipped triangle is produced at the output of the wave shaper.*

### How to Adjust the Maximum Ramp Voltage?

We need to focus on what conditions the maximum value of the ramp voltage. This value is obtained by multiplying the slope of the line by the charge duration. The charge duration is easy to know—it's the inverse of the note's frequency (i.e., the period). The slope depends on several factors:
- The value \(C\) of the capacitor's capacity: The voltage \(U_C\) across the capacitor equals \(U_C = Q / C\) where \(Q\) is the charge stored in the capacitor, which increases with constant current charging. Adjusting the value of a capacitor is challenging. By inverting the problem, we do not know the value of \(C\) precisely due to component tolerances (around 10% here) and aging of the component. As recommended in the datasheet, we have selected a 1.5nF capacitor for charging the VCO.
- The resistance \(R_T\) that sets the current of the current generator. It is easier to adjust the value of \(R_T\) than that of the charge capacity. We use this to our advantage in the register change (TODO: link).
- Finally, the value of the voltage \(V_{wf}\) that controls the current generator. This gives it its name \(V_{wf}\) for Waveform voltage, and this is how the maximum amplitude of the ramp voltage is primarily controlled: dynamically adjusting \(V_{wf}\).

Let's look at this mathematically:
$$
V_{\text{ramp}} =  \left(\dfrac{V_{wf}}{RC}\right) \dfrac{1}{f}
$$
which can be rearranged to find the necessary \(V_{wf}\) to produce a given waveform and corresponding \(V_{\text{ramp}}\):
$$
V_{wf} = RC \cdot f \cdot V_{\text{ramp}}
$$

However, as mentioned earlier, we do not know the exact value of \(RC\) due to component tolerances and, over the long term, their aging.

### In-Situ Measurement of Maximum Ramp Voltage

Since we cannot rely on any specific \(RC\) value, measurements are necessary, at a minimum at each startup of the chip, of the maximum ramp voltage \(V_{\text{ramp}}\) for a given \(V_{wf}\). We utilize one of the Analog to Digital Converters (ADC) of the RP2040 for this purpose.

From a technical standpoint, the ADC pin of the RP2040 cannot be connected directly. The measurement towards the ADC requires a small current that is taken from the capacitor and disturbs its charging. In other terms, the input impedance of the ADC is too low. Therefore, a buffer with nearly infinite input impedance is necessary. As a side note, even an oscilloscope cannot be connected directly without a buffer, as its 1 MOhm input resistance is not sufficient and creates a leakage current that significantly disrupts the charging of the capacitor.

Continuing with technical details, we have chosen to use a rail-to-rail Operational Amplifier (OpAmp) as a buffer, the MCP60002, which, in addition to buffering, also acts as a limiter. Indeed, the voltage at the ADC terminals must not exceed 3.3V, otherwise, it risks damage. The rail-to-rail OpAmp clamps any voltage that exceeds its supply voltage range, in this case between 0V and 12V. The buffer is followed by a voltage divider made of 3.6K and 1.2K resistors to bring the voltage between 0 and \( \frac{1.2}{(1.2 + 3.6)} \times 12 = 3V \), ensuring that the ADC's voltage limit is not exceeded.

dco capacitor discharge schematics
*Figure X: Schematic of the Voltage Ramp Measurement and Capacitor Discharge Process.*

### Servo Control of \(V_{wf}\) Based on the Maximum Ramp Voltage \(V_{r}\)

To summarize, the DCO allows for easy setting of the oscillator's note frequency, but the amplitude of the played note must be adjusted for each frequency. In the context of the AS3397 and its wave shaper, amplitude translates into waveform shape. If the amplitude of the voltage ramp is not adjusted, all notes have the same frequency but also different waveforms! The tool to maintain the same waveform is the adjustment of \(V_{wf}\) according to the frequency, which controls the intensity of the charging current of the capacitor and thus its charging speed. However, the proportionality relationship between \(V_{wf}\) and the maximum ramp voltage \(V_{\text{ramp}}\) is not known a priori because we do not know the values of \(R_T\) and \(C\) precisely.

One initial approach is to calibrate the DCOs to obtain a measurement of \(RC\). I emphasize once again, this is not tuning; this calibration is not for frequency as would typically be necessary. Here, the DCO guarantees tuning, but without countermeasures, the waveform of these correct notes is erratic. This \(RC\) calibration can be performed at startup, where we measure the value of the maximum ramp voltage \(V_{\text{ramp}}\) for several known values of \(V_{wf}\) and for several frequencies. This approach requires some time at the startup of the synthesizer, and it is not excluded that the precise value of \(RC\) may drift during use, for example, due to thermal drift.

Our approach is more original; we continuously control and regulate the value of \(V_{wf}\). This primarily involves software processing, which is detailed along with the relevant code here TODO Link. In brief, an interrupt is triggered within the microcontroller at the frequency \(f\) of the note. During this interruption, we start by reading the current value of the ramp voltage at the ADC. One might think that we would read the ramp voltage at any value and not at its maximum since there is no apparent synchronization between the DCO and the interruption. However, the trick is to discharge the capacitor just after reading the ramp value. We are therefore sure that we have read the maximum value of the ramp. The next discharge of the capacitor will occur at the next call of the interruption, which happens at the frequency \(f\). As a side note, it is indeed the management of the interruption that is responsible for setting the frequency \(f\) of the note and not a PWM signal as one might initially think. However, the problem of the waveform and its control by \(V_{wf}\) remains. The interruption allows for the measurement of \(V_{\text{ramp}}\) for each oscillation and its comparison to the desired value, for example, XV if a triangular waveform is desired. We then adjust the value of \(V_{wf}\), call after call of the interruption until the correct value of \(V_{\text{ramp}}\)

TODO Faire un court texte sur le PID.

### Fine Adjustment of \( V_{wf} \)

As outlined in the previous paragraphs, \( V_{wf} \) plays a crucial role in waveform control. We can enhance its behavior in two ways:
- The \( V_{wf} \) voltage, like all other control voltages, is generated via a PWM signal from the RP2040 and low-pass filtered ([see here for more information](PWM_CV.md). Its precision and response time can be improved by using a "dual PWM" 16-bit setup, which involves passively summing two 8-bit PWM signals.
- By switching the \( R_T \) resistances, which set the charging current for the lower notes. This switching is performed by a transistor (again, a BS170), changing the \( R_T \) value from 442 kOhm when the transistor is off to about 425 Ohm when it is on (see component value choices). At high frequencies, where the capacitor has little time to charge, we can switch to a resistance \( R_T \) that increases the capacitor's charging current to achieve ramp values sufficient for generating "clipped triangle" waveforms.

## The Comparator and Square Waveforms

The AS3397 allows adding a square waveform to the output from the wave shaper by comparing the ramp voltage to a threshold voltage "Pulse Width C.V." noted as \( V_{PW} \). When the ramp voltage \( V_{ramp} \) is below \( V_{PW} \), the square signal is 0V, and otherwise, \( V_{PW} \) takes on a non-zero value that can be added to the waveforms generated by the wave shaper.

The threshold voltage \( V_{PW} \) thus allows for controlling the duty cycle of the square signal. However, like the waveform from the wave shaper, the slope of the capacitor's charging ramp depends on the frequency of the played note. If we want to maintain the same duty cycle regardless of the played note, \( V_{PW} \) must be dynamically adjusted.

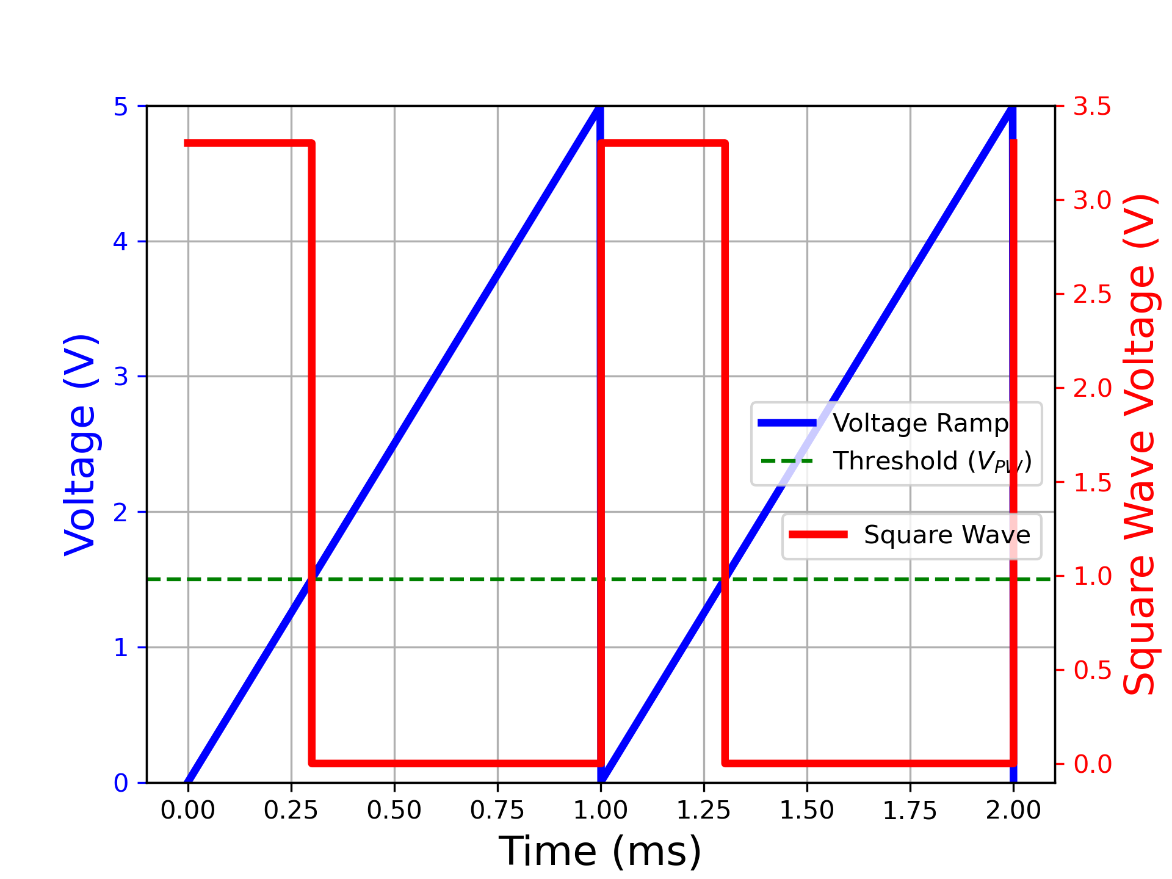
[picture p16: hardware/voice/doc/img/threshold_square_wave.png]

*Figure X: Square wave generation via the comparison of the ramp voltage and a adjustable \( V_{PW} \) threshold voltage*

For example, to achieve a PWM with a duty cycle of 50%, you must set the threshold voltage \( V_{PW} \) to half of the maximum \( V_{ramp} \) of the capacitor's voltage ramp.

Since slight variations in the duty cycle across different notes are not as critical as changes in waveform, we do not dynamically adjust the threshold \( V_{PW} \) voltage. Instead, we maintain a constant value that is set with each frequency change. More precisely, once \( V_{ramp} \), the maximum ramp voltage, is determined based on the waveform selected by the user, it is simply multiplied by the desired duty cycle to calculate \( V_{PW} \).

The PWM voltage control from the RP2040 is level shifted from 0–3.3V to -0.5–5V. This upper limit of 5V can be seen as restrictive because for voltage ramps exceeding 5V, achieving a 100% duty cycle is no longer possible. Nonetheless, there is generally no need to exceed a 50% duty cycle because, for example, a 75% duty cycle has the same sonic spectrum as a 25%. In the case of the AS3397, the implications are somewhat more nuanced. Since the square signal is added on top of the waveform exiting the wave shaper, if this waveform is not symmetric, then 25% and 75% duty cycles do not produce exactly the same waveform.

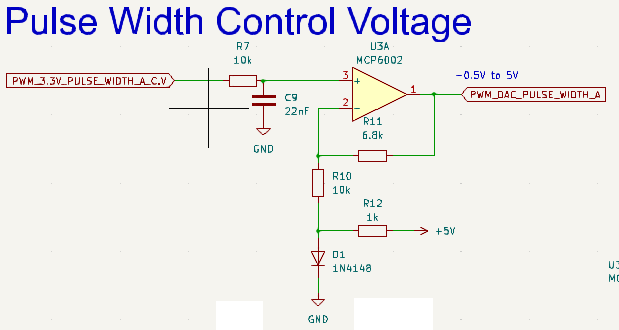
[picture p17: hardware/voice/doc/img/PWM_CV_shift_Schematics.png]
dco capacitor discharge schematics

*Figure X: Schematic of the Level Shifter for \( V_{PW} \), the PWM Threshold. The PWM signal is initially low-pass filtered (cutoff frequency ≈ 700Hz, response time for 12 bits @ 250 MHz: 0.5ms). Diode D1 is conducting, thus its voltage is approximately 0.6V and acts as a bias to achieve negative values at the output of the op-amp set as a non-inverting amplifier (gain ratio 10/6.8, which transforms 3.3V into 5V).*

We have also shifted \( V_{PW} \) to negative levels because the only way to mute the square wave is by setting it to a 0% duty cycle (as a reminder, achieving 100% is not possible here for all waveforms). Setting the threshold at 0V, which theoretically should result in a 0% duty cycle, does not fully mute the square wave in our experiments, hence the use of negative values.

## The Quad Mixer

In total, the VCO of an AS3397 chip can generate four analog signals:
- The signal (saw, triangle, clipped triangle, and in-between) from wave shaper A
- The square signal from comparator A
- The signal from wave shaper B
- The square signal from comparator B

These signals can be mixed or not mixed into the VCAs via the use of the quad mixer. Its operation is detailed in Figure 3 of the datasheet.

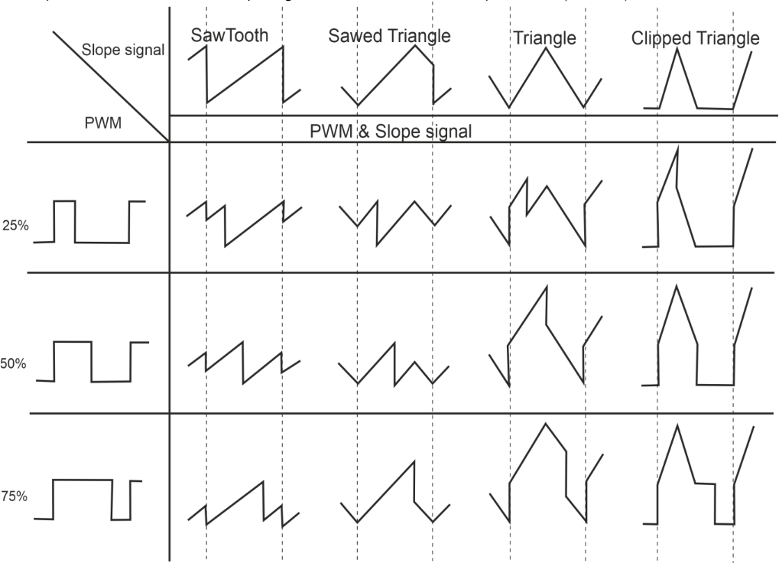
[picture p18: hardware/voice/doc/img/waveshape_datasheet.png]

*Figure X: Extracted from the datasheet. Some waveform that can be produced by the VCO by adding the waveform at the exit of the waveshapper and a square PWW signal*

An important point is that square waveforms are always sent to the VCA. As mentioned earlier, the only way to mute them and set their duty cycle to 0 is through this method.

The quad mixer then allows selecting four mixing modes for the voltages from the wave shapers:
- A & B, where both wave shapers are connected to the VCA. This requires a negative voltage, typically -1V.
- Only B, with a voltage between 0 and 1V.
- No waveform from the wave shapers, with only the square waveforms from the comparators for voltages between 1.5 and 2.5V.
- Only A for voltages between 3 and 4V.

The AS3397 datasheet does not specify how to produce these voltages, whereas the CEM3396 datasheet proposes a setup that we have adapted to the RP2040, which operates at 3.3V instead of 5V, and where we used an active circuit instead of a transistor since we had an operational amplifier left.

The setup is shown in Figure X. Here is also a link to its simulation with Circuit.js. Briefly, it consists of an op-amp adder and shifter setup. Two digital outputs from the RP2040 allow defining four states which, via the choice of resistances and the offset voltage, produce output voltages of -0.7, 0.5, 2, and 3 V (-0.6, 1.5V, 2.9V, 3.5V).

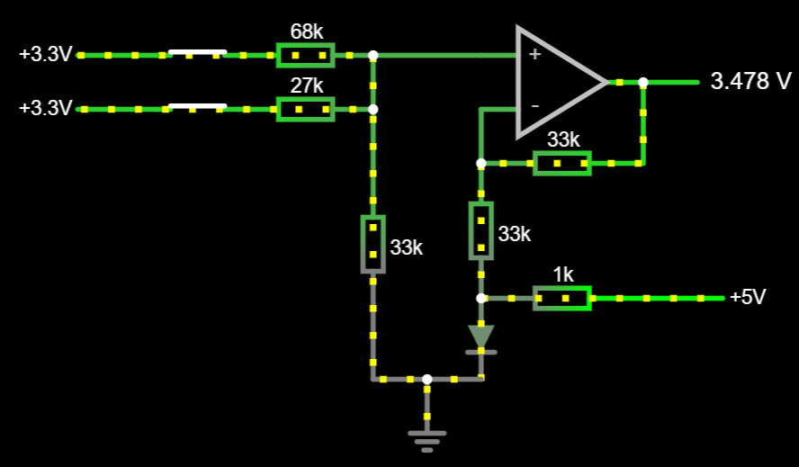
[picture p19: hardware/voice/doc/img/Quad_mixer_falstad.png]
Quad mixer circuit simulation (https://www.falstad.com/circuit/circuitjs.html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)

*Figure X: Schematic for Generating the Four Voltages for the Quad Mixer. The two 3.3V inputs originate from two GPIO pins of the RP2040. The diode, constantly active due to the +5V supply and the 1K current-limiting resistor, establishes a negative reference voltage of approximately -0.7V.
*

## The balance VCA

La dernière étage du VCO est deux VCA qui permettent de mixer les niveaux relatifs entre le VCOA et le VCOB. Ces niveaux sont réglés par le CV voltage "balance". Cette tension est généré par le rp2040 en utilisant un signal PWM filtré passe-bas.  Contrairement à la plupart des autres CV, l'entrée Balance attend des tensions entre -2.2V pour avoir uniquement le DCO B et 2.2V pour avoir uniquement le DCO A. De ce fait, après le filtrage par le filtre passe-bas RC, un montage AO multiplicateur et level shifter est ajouté.

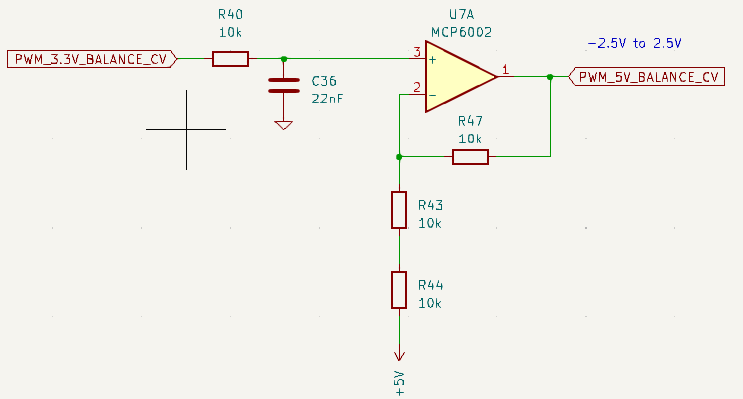
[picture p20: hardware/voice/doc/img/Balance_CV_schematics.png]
Schematic balance CV
]
*Figure X: Schematic for level shift the low-pass filtered PWM control voltage, intially between 0 and 3.3V, to -2.5V and 2.5V.

Falstad_Balance_cv_level_shifter

## Le choix des composants

V_{wf] ne va que jusqu'à 3.3V, il faut atteindre une valeur de rampe max, même à basse fréquence. Avec f_min et V_{wf} max, où arrive-t-on ?

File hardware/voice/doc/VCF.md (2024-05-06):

# Voltage Controlled Filter

Work in progress

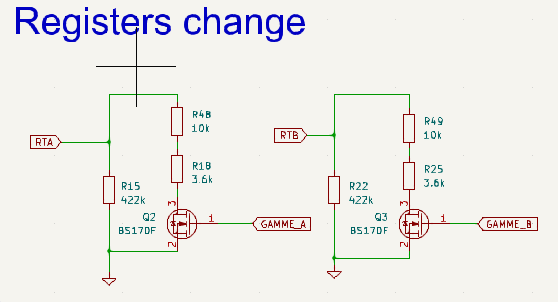
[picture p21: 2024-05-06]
hardware/voice/doc/img/REgister_change_schematic.png

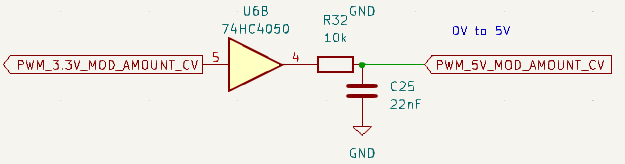
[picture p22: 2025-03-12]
hardware/voice/doc/img/PWM_Modulation_schematics.png

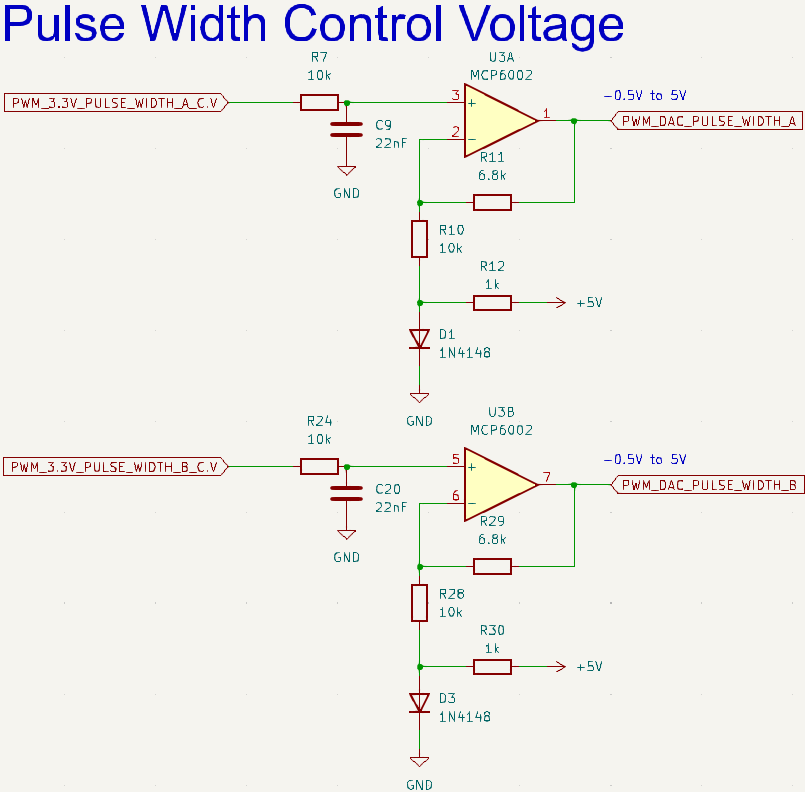
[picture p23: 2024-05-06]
hardware/voice/doc/img/PWM_level_shifter.png

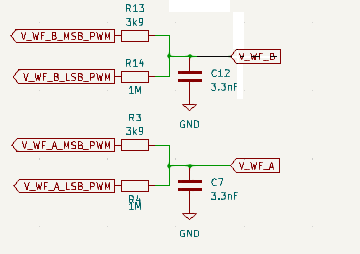
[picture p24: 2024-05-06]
hardware/voice/doc/img/V_wf_16bit_schematics.png

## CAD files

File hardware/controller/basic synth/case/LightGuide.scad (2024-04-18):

LED_x = 5.1;
LED_y = 5.5;
LED_z = 1.8;


x_carre_jour = 3.9; // avant

d_pcb_panel = 7;

module lightGuide()
{
translate([0,0,1.2])
{
union()
{

difference()
{
    // Pourtour
    cube([LED_x*1.15, LED_y*1.15, d_pcb_panel/2.0], center=true);
    translate([0,0,-LED_z/2])
    cube([LED_x, LED_y, LED_z], center=true);
}

translate([0,0,d_pcb_panel/2])
cube([x_carre_jour, x_carre_jour, d_pcb_panel/2 + 3], center=true);

}

}
}

// Définir les dimensions de l'objet à quadriller
largeur_objet = 10;
hauteur_objet = 10;

// Définir les dimensions du quadrillage
nombre_de_colonnes = 3;
nombre_de_lignes = 3;
espacement_entre_objets = 2;

// Créer le quadrillage en dupliquant l'objet
for (i = [0 : nombre_de_colonnes - 1]) {
    for (j = [0 : nombre_de_lignes - 1]) {
        translate([i * (largeur_objet + espacement_entre_objets), j * (hauteur_objet + espacement_entre_objets), 0])
            lightGuide();
    }
}

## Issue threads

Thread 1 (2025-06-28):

Use of MCP6002 in your DIP design and -5V

craigyjp, 2025-06-28:
The MCP6002 chip is single rail , but your schematic and board show +/- 5V powering the MCP6002 chips which will probably destroy them. Even the MCP602 is single rail.

Maybe you should be using TL072 in all the DIP boards?

craigyjp, 2025-06-28:
I also use the method of a Pico clone controlling a voice, recently I completed a bi-timbral 8 voice polysynth with analogue oscillators under Pico/DAC control. I used midi as a private bus to control the oscillators and another private bus to update the displays.

https://github.com/craigyjp/A_Bit_More

MLoum, 2025-06-28:
> “Do any of the voltages required swing to -5V? It would make sense to use op-amps powered from ±12V to remove the need for rail-to-rail parts.”

First, the AS3397 requires -5V to operate, so we do need this negative rail.

* The cutoff CV must reach negative values (currently -2.5V to +5V) to fully open the filter (see “Filter CutOff Control Voltage” on the schematic).
* The CVs controlling the PWM duty cycle of the square wave also need to go slightly negative to ensure that the square part of the DCO signal can be fully muted.

You're right that we could use non-rail-to-rail op-amps if we provided them with ±12V supply rails, since the CV voltages only go up to +5V and down to -2.5V.

However, since we already need -5V for the AS3397, we decided to keep only a -5V rail in the design and drop the -12V rail (which was used in earlier versions).

Additionally, we need a +12V rail for the op-amp that buffers the voltage across the charging capacitor before it's read by the Pi Pico's ADC. To cover the full range of waveforms provided by the waveshaper, this capacitor must be charged up to VCC, i.e., +12V, so a rail-to-rail op-amp is absolutely required in this part of the circuit.

In the end, a non-rail-to-rail op-amp powered by -5V/+12V could be used in all places except the op-amp in the *"DCO charge capacitor / DCO ramp to ADC"* stage, which truly requires rail-to-rail operation.

> “I looked at this project many months ago and actually ordered a full set of SMD boards”

The board and routing are still up to date, but some component choices need to be revised:

* As mentioned above, the MCP6002 op-amps should be replaced with TCL2262 (or any equivalent: rail-to-rail, dual supply, and tolerant of 0–12V operation).
* The resistor values in the “Audio output (transimpedance opAmp)” section are too high (currently 100k), which causes the op-amp to saturate. We plan to reduce them to 50k in the next update.
* After taking measurements, we found that the -2.5V to +5V range for the cutoff CV is not musically useful, most of the voltages lead to cutoff frequencies either below 20Hz or above 10kHz. We will therefore update the component values to match a more musically useful range.

> “I would have thought changing the old Teensy to a more readily available one like the Teensy 4 or 4.1 would make sense too. Using an obsolete SOC is not a good way forwards.”

The Teensy on the conductor board (which drives the voice boards) was originally a temporary solution... that lasted way too long. We actually have a prototype "conductor board" with an RP2040 (or even RP2350). It's not fully tested yet, but knowing that people are interested is a strong motivation to push it forward and finalize it for release.

> “[https://github.com/craigyjp/A\_Bit\_More”](https://github.com/craigyjp/A_Bit_More”)

I only had a quick look so far but it's really impressive, especially the attention to detail on the front panel! I'll definitely dig deeper, and check out your other repos as well.

dguichaoua, 2025-06-29:
Alternatively, you can use the TLV2372IP in DIP8 package https://www.mouser.fr/ProductDetail/Texas-Instruments/TLV2372IP?qs=dQbkqP7qjabLXs2c4TTU4Q%3D%3D   or TLV2372QDRG4Q1 in SOIC8 package https://www.mouser.fr/ProductDetail/Texas-Instruments/TLV2372QDRG4Q1?qs=pZC5fsuWujFw4K%2FEufCOFQ%3D%3D

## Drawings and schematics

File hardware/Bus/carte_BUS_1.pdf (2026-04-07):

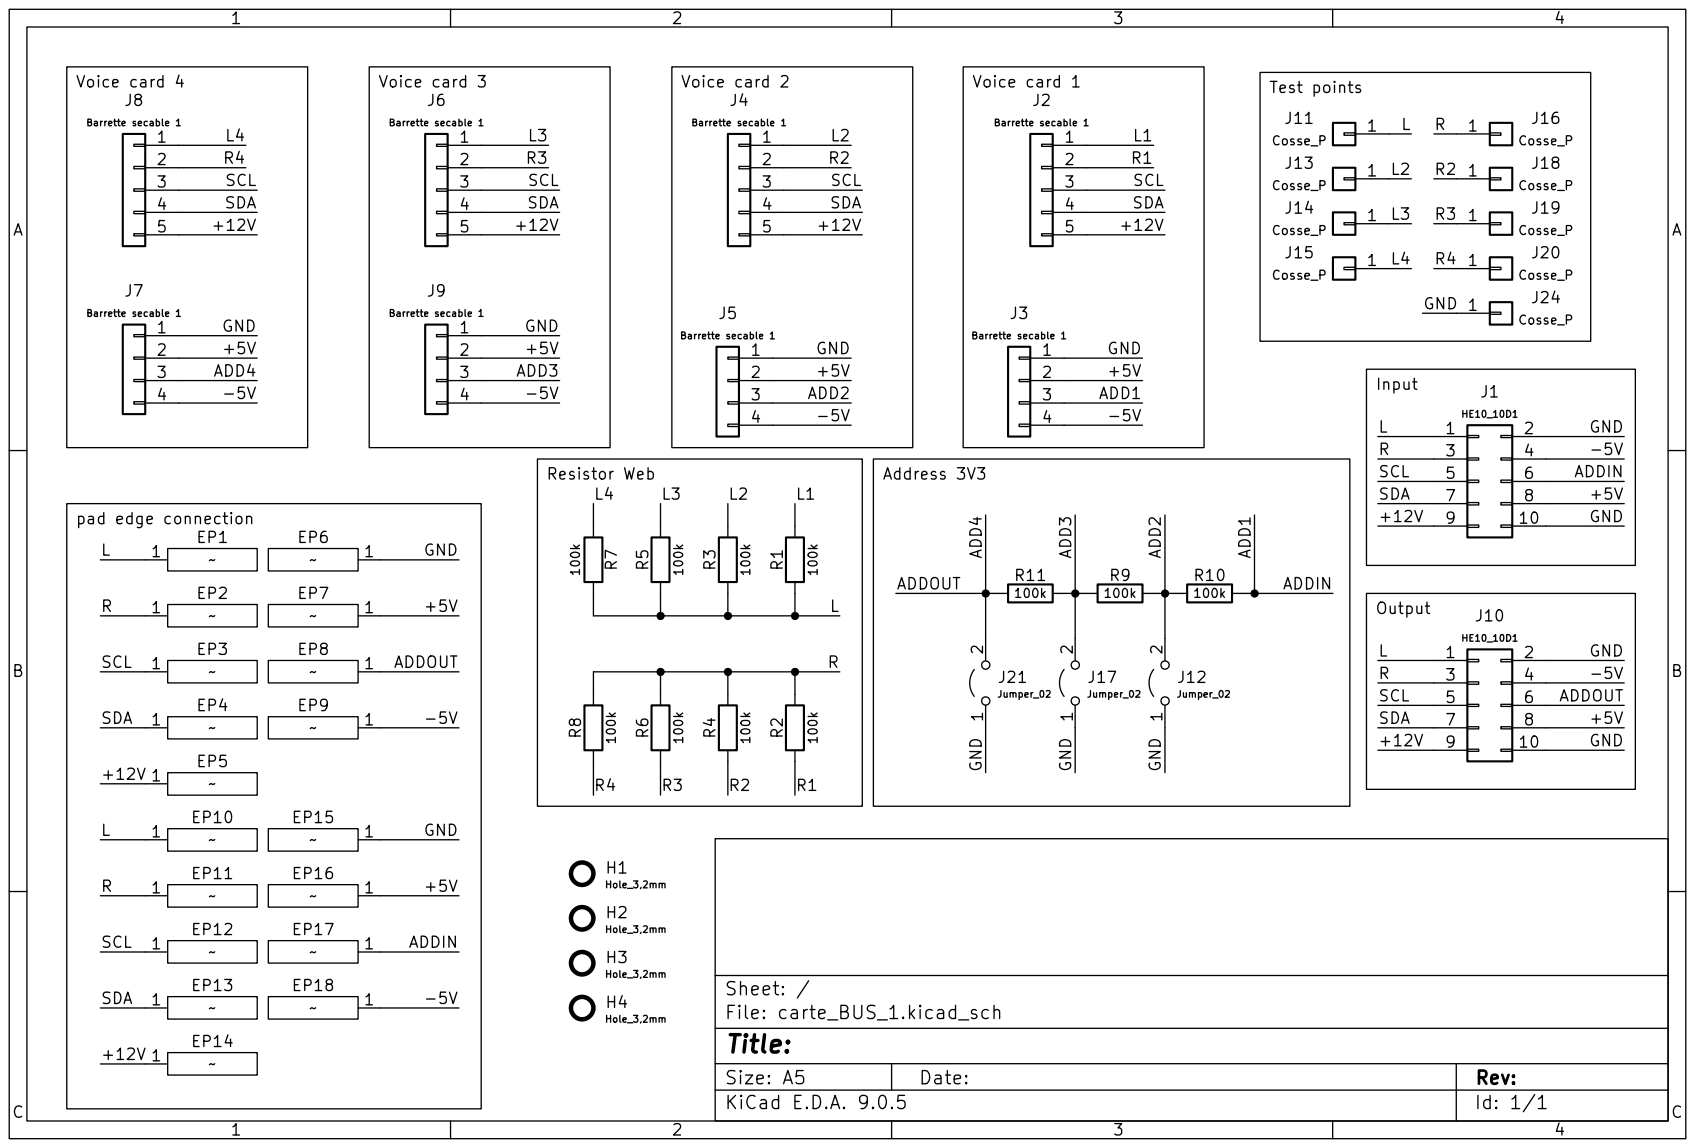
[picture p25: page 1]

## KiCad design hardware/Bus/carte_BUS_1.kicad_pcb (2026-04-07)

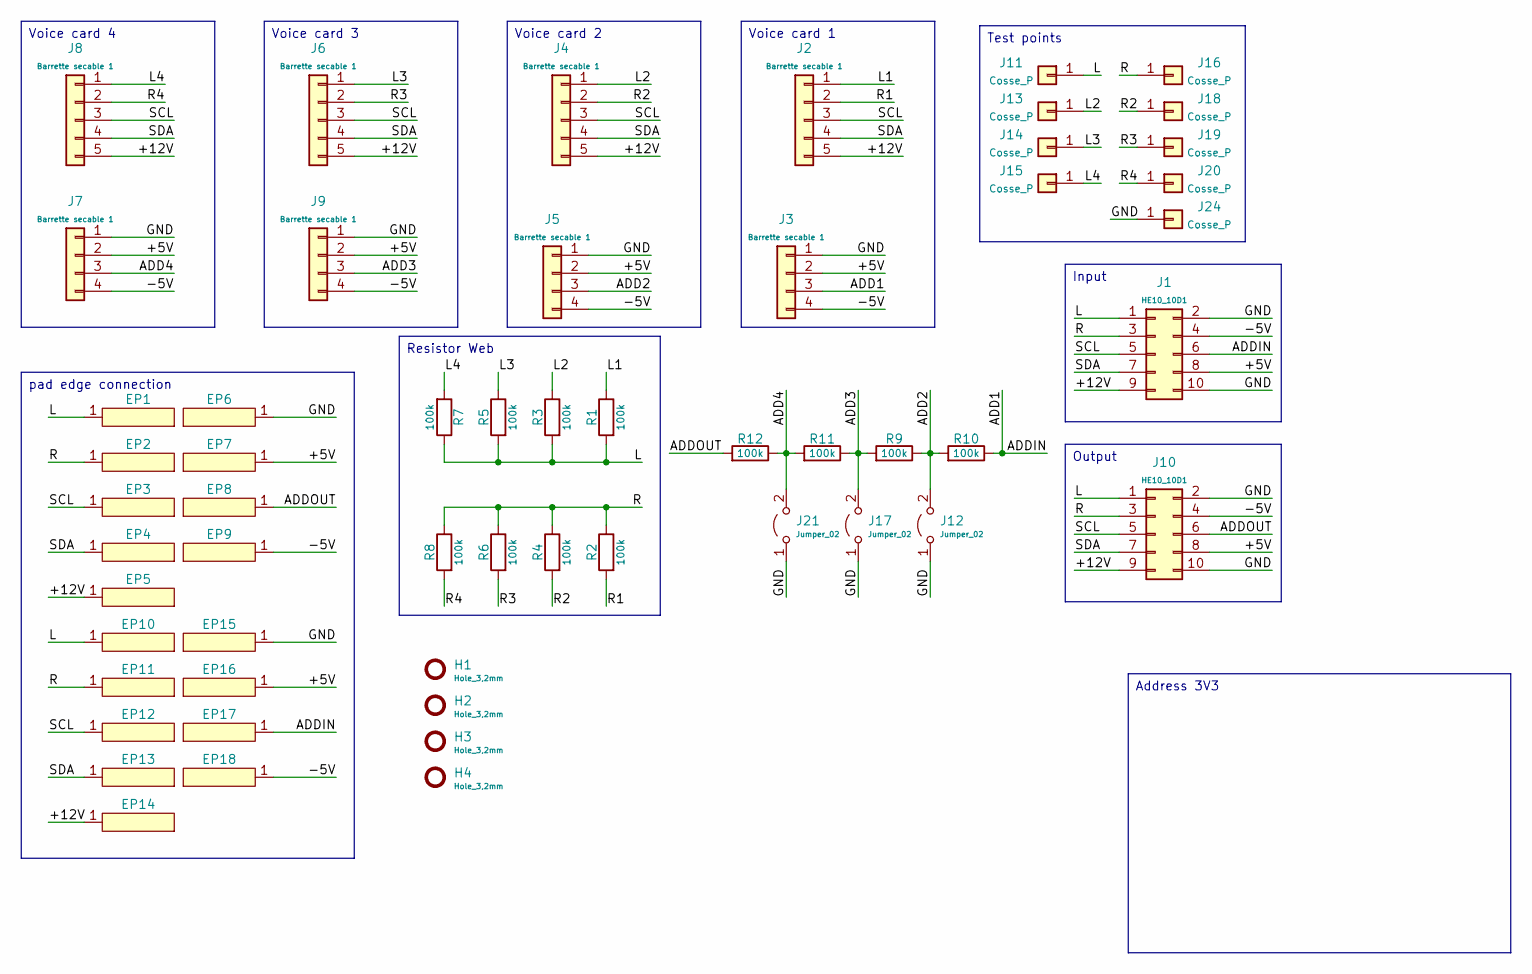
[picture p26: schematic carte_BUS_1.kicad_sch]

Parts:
EP1, EP2, EP3, EP4, EP5, EP6, EP7, EP8, EP9, EP10, EP11, EP12, EP13, EP14, EP15, EP16, EP17, EP18: edge_pad
H1, H2, H3, H4: Hole_3,2mm
J1, J10: HE10_10D1; 09185106904
J2, J4, J6, J8: Barrette secable 1; MA01-05
J3, J5, J7, J9: Barrette secable 1; MA01-04
J11, J13, J14, J15, J16, J18, J19, J20, J24: Cosse_P
J12, J17, J21: Jumper_02; MA01-02
R1, R2, R3, R4, R5, R6, R7, R8, R9, R10, R11, R12: 100k; RCMS1206

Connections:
/+5V: EP7.1, EP16.1, J1.8, J3.2, J5.2, J7.2, J9.2, J10.8
/+12V: EP5.1, EP14.1, J1.9, J2.5, J4.5, J6.5, J8.5, J10.9
/-5V: EP9.1, EP18.1, J1.4, J3.4, J5.4, J7.4, J9.4, J10.4
/ADD1: EP17.1, J1.6, J3.3, R10.2
/ADD2: J5.3, J12.2 (B), R9.2, R10.1
/ADD3: J9.3, J17.2 (B), R9.1, R11.2
/ADD4: J7.3, J21.2 (B), R11.1, R12.2
/ADDOUT: EP8.1, J10.6, R12.1
/GND: EP6.1, EP15.1, J1.2, J1.10, J3.1, J5.1, J7.1, J9.1, J10.2, J10.10, J12.1 (A), J17.1 (A), J21.1 (A), J24.1
/L: EP1.1, EP10.1, J1.1, J10.1, J11.1, R1.1, R3.1, R5.1, R7.2
/L1: J2.1, R1.2
/L2: J4.1, J13.1, R3.2
/L3: J6.1, J14.1, R5.2
/L4: J8.1, J15.1, R7.1
/R: EP2.1, EP11.1, J1.3, J10.3, J16.1, R2.2, R4.2, R6.2, R8.2
/R1: J2.2, R2.1
/R2: J4.2, J18.1, R4.1
/R3: J6.2, J19.1, R6.1
/R4: J8.2, J20.1, R8.1
/SCL: EP3.1, EP12.1, J1.5, J2.3, J4.3, J6.3, J8.3, J10.5
/SDA: EP4.1, EP13.1, J1.7, J2.4, J4.4, J6.4, J8.4, J10.7

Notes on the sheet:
Voice card 4
Resistor Web
Voice card 2
Input
Voice card 1
Address 3V3
pad edge connection
Test points
Voice card 3
Output

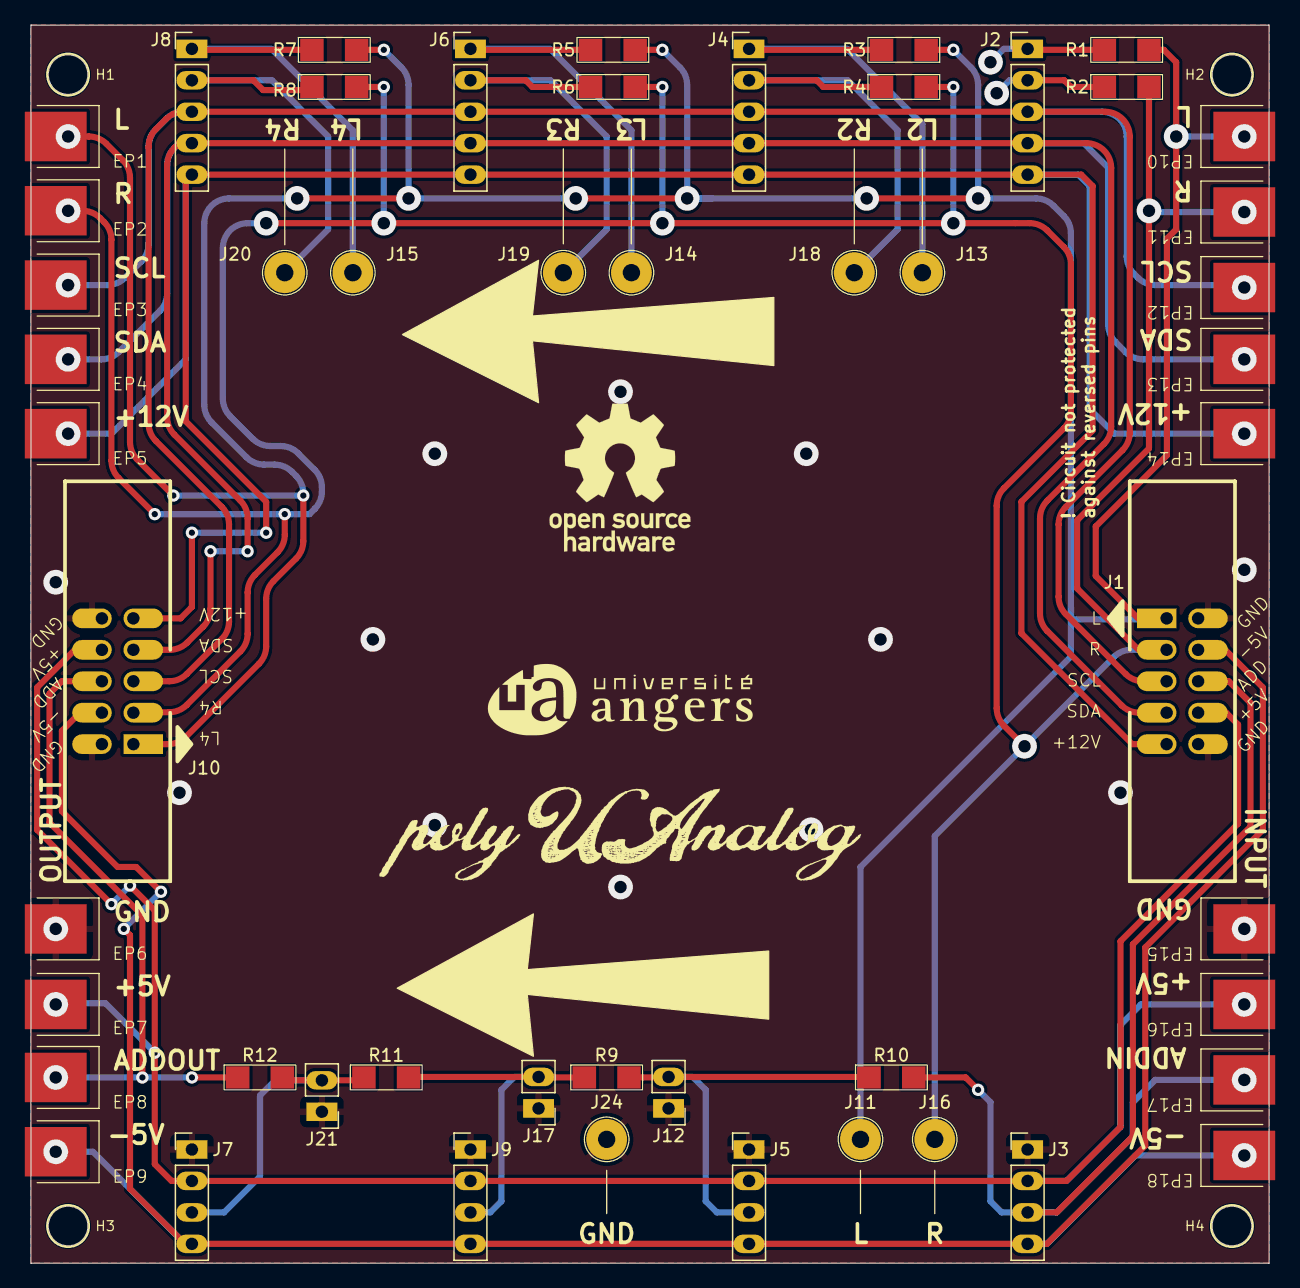
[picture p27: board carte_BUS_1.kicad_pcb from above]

Board: 2 copper layers, 100.0 x 100.0 mm, 56 parts (0 on the bottom side), 21 nets.

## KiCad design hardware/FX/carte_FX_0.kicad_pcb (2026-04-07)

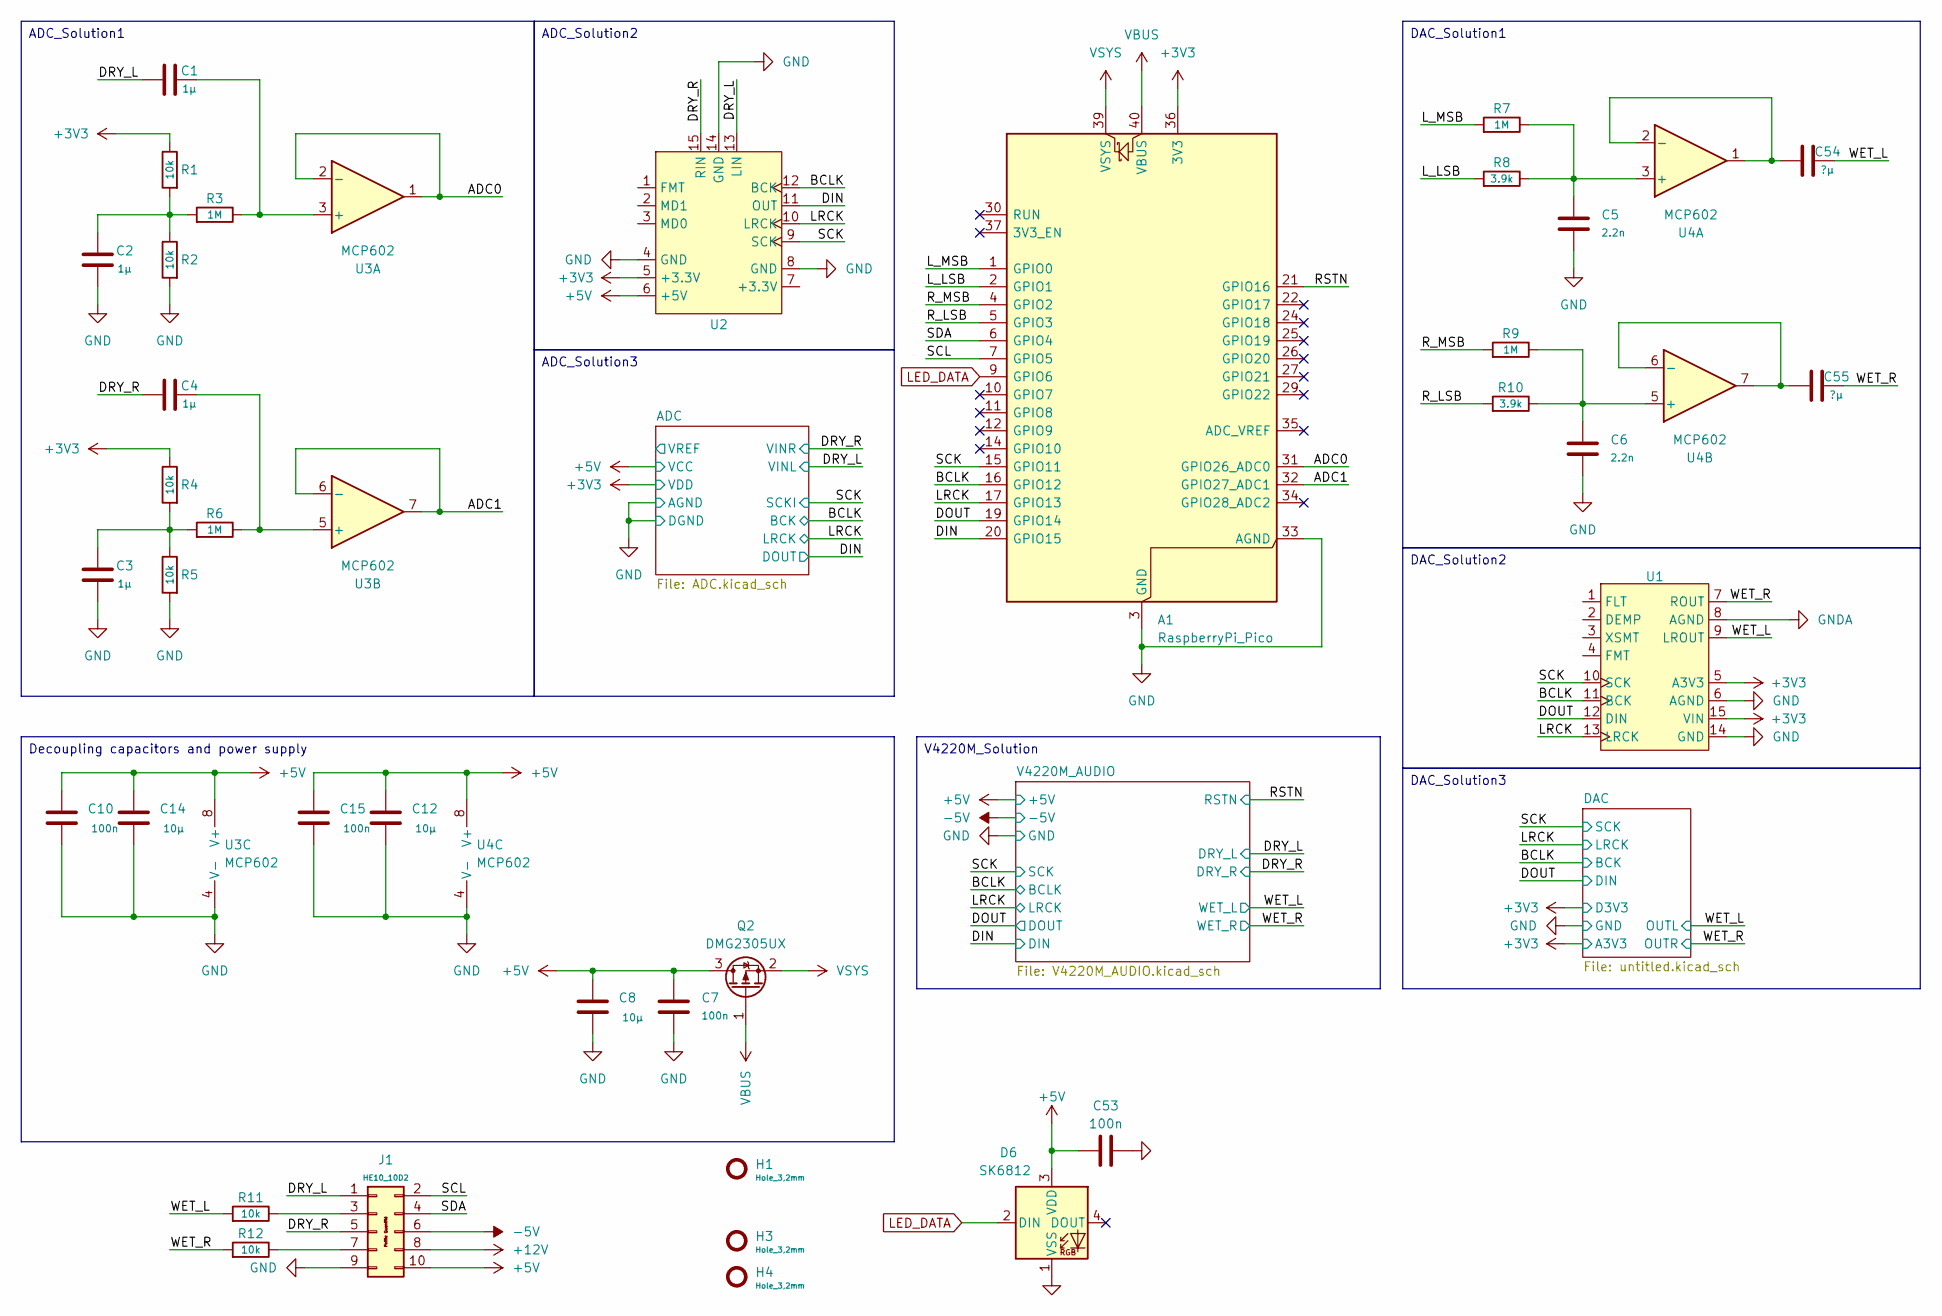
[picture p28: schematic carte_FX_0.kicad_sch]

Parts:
A1: RaspberryPi_Pico; RaspberryPi_Pico_Common_Unspecified
C1, C2, C3, C4: 1µ; CCMS1206
C5, C6: 2.2n; CCMS1206
C7, C10, C15: 100n; CCMS1206
C8, C12, C14: 10µ; CCMS1206
C53: 100n; C_0603_1608Metric_Pad1.08x0.95mm_HandSolder
C54, C55: ?µ; CCMS1206
D6: SK6812; LED_SK6812_PLCC4_5.0x5.0mm_P3.2mm
H1, H3, H4: Hole_3,2mm
J1: HE10_10D2; 09185107324
Q2: DMG2305UX; SOT-23
R1, R2, R4, R5, R11, R12: 10k; RCMS1206
R3, R6, R7, R9: 1M; RCMS1206
R8, R10: 3.9k; RCMS1206
U1: PCM_5102a_MOD
U2: PCM1808_MOD
U3, U4: MCP602; SOP-8_3.76x4.96mm_P1.27mm

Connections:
+3V3: A1.36 (3V3), R1.2, R4.2, U1.5 (A3V3), U1.15 (VIN), U2.5 (+3.3V); also elsewhere on the board
+5V: C7.1, C8.2, C10.2, C12.2, C14.2, C15.2, C53.1, D6.3 (VDD), J1.10, Q2.3 (D), U2.6 (+5V), U3.8 (V+), U4.8 (V+); also elsewhere on the board
+12V: J1.8
-5V: J1.6; also elsewhere on the board
/ADC0: A1.31 (GPIO26_ADC0), U3.1, U3.2 (-)
/ADC1: A1.32 (GPIO27_ADC1), U3.6 (-), U3.7
/BCLK: A1.16 (GPIO12), U1.11 (BCK), U2.12 (BCK); also elsewhere on the board
/DIN: A1.20 (GPIO15), U2.11 (OUT); also elsewhere on the board
/DOUT: A1.19 (GPIO14), U1.12 (DIN); also elsewhere on the board
/DRY_L: C1.1, J1.1, U2.13 (LIN); also elsewhere on the board
/DRY_R: C4.1, J1.5, U2.15 (RIN); also elsewhere on the board
/LRCK: A1.17 (GPIO13), U1.13 (LRCK), U2.10 (LRCK); also elsewhere on the board
/L_LSB: A1.2 (GPIO1), R8.1
/L_MSB: A1.1 (GPIO0), R7.1
/RSTN: A1.21 (GPIO16); also elsewhere on the board
/R_LSB: A1.5 (GPIO3), R10.1
/R_MSB: A1.4 (GPIO2), R9.1
/SCK: A1.15 (GPIO11), U1.10 (SCK), U2.9 (SCK); also elsewhere on the board
/SCL: A1.7 (GPIO5), J1.2
/SDA: A1.6 (GPIO4), J1.4
/WET_L: C54.2, R11.1, U1.9 (LROUT); also elsewhere on the board
/WET_R: C55.2, R12.1, U1.7 (ROUT); also elsewhere on the board
GND: A1.3 (GND), A1.8 (GND), A1.13 (GND), A1.18 (GND), A1.23 (GND), A1.28 (GND), A1.33 (AGND), A1.38 (GND), C2.1, C3.1, C5.2, C6.2, C7.2, C8.1, C10.1, C12.1, C14.1, C15.1, C53.2, D6.1 (VSS), J1.9, R2.1, R5.1, U1.6 (AGND), U1.14 (GND), U2.4 (GND), U2.8 (GND), U2.14 (GND), U3.4 (V-), U4.4 (V-); also elsewhere on the board
GNDA: U1.8 (AGND)
LED_DATA: A1.9 (GPIO6), D6.2 (DIN)
unnamed: C2.2, R1.1, R2.2, R3.1
unnamed: C3.2, R4.1, R5.2, R6.1
unnamed: J1.3, R11.2
unnamed: J1.7, R12.2
unnamed: C1.2, R3.2, U3.3 (+)
unnamed: C4.2, R6.2, U3.5 (+)
unnamed: C5.1, R7.2, R8.2, U4.3 (+)
unnamed: C54.1, U4.1, U4.2 (-)
unnamed: C6.1, R9.2, R10.2, U4.5 (+)
unnamed: C55.1, U4.6 (-), U4.7
VBUS: A1.40 (VBUS), Q2.1 (G)
VSYS: A1.39 (VSYS), Q2.2 (S)

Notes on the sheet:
V4220M_Solution
ADC_Solution3
Decoupling capacitors and power supply
ADC_Solution1
DAC_Solution1
DAC_Solution2
DAC_Solution3
ADC_Solution2

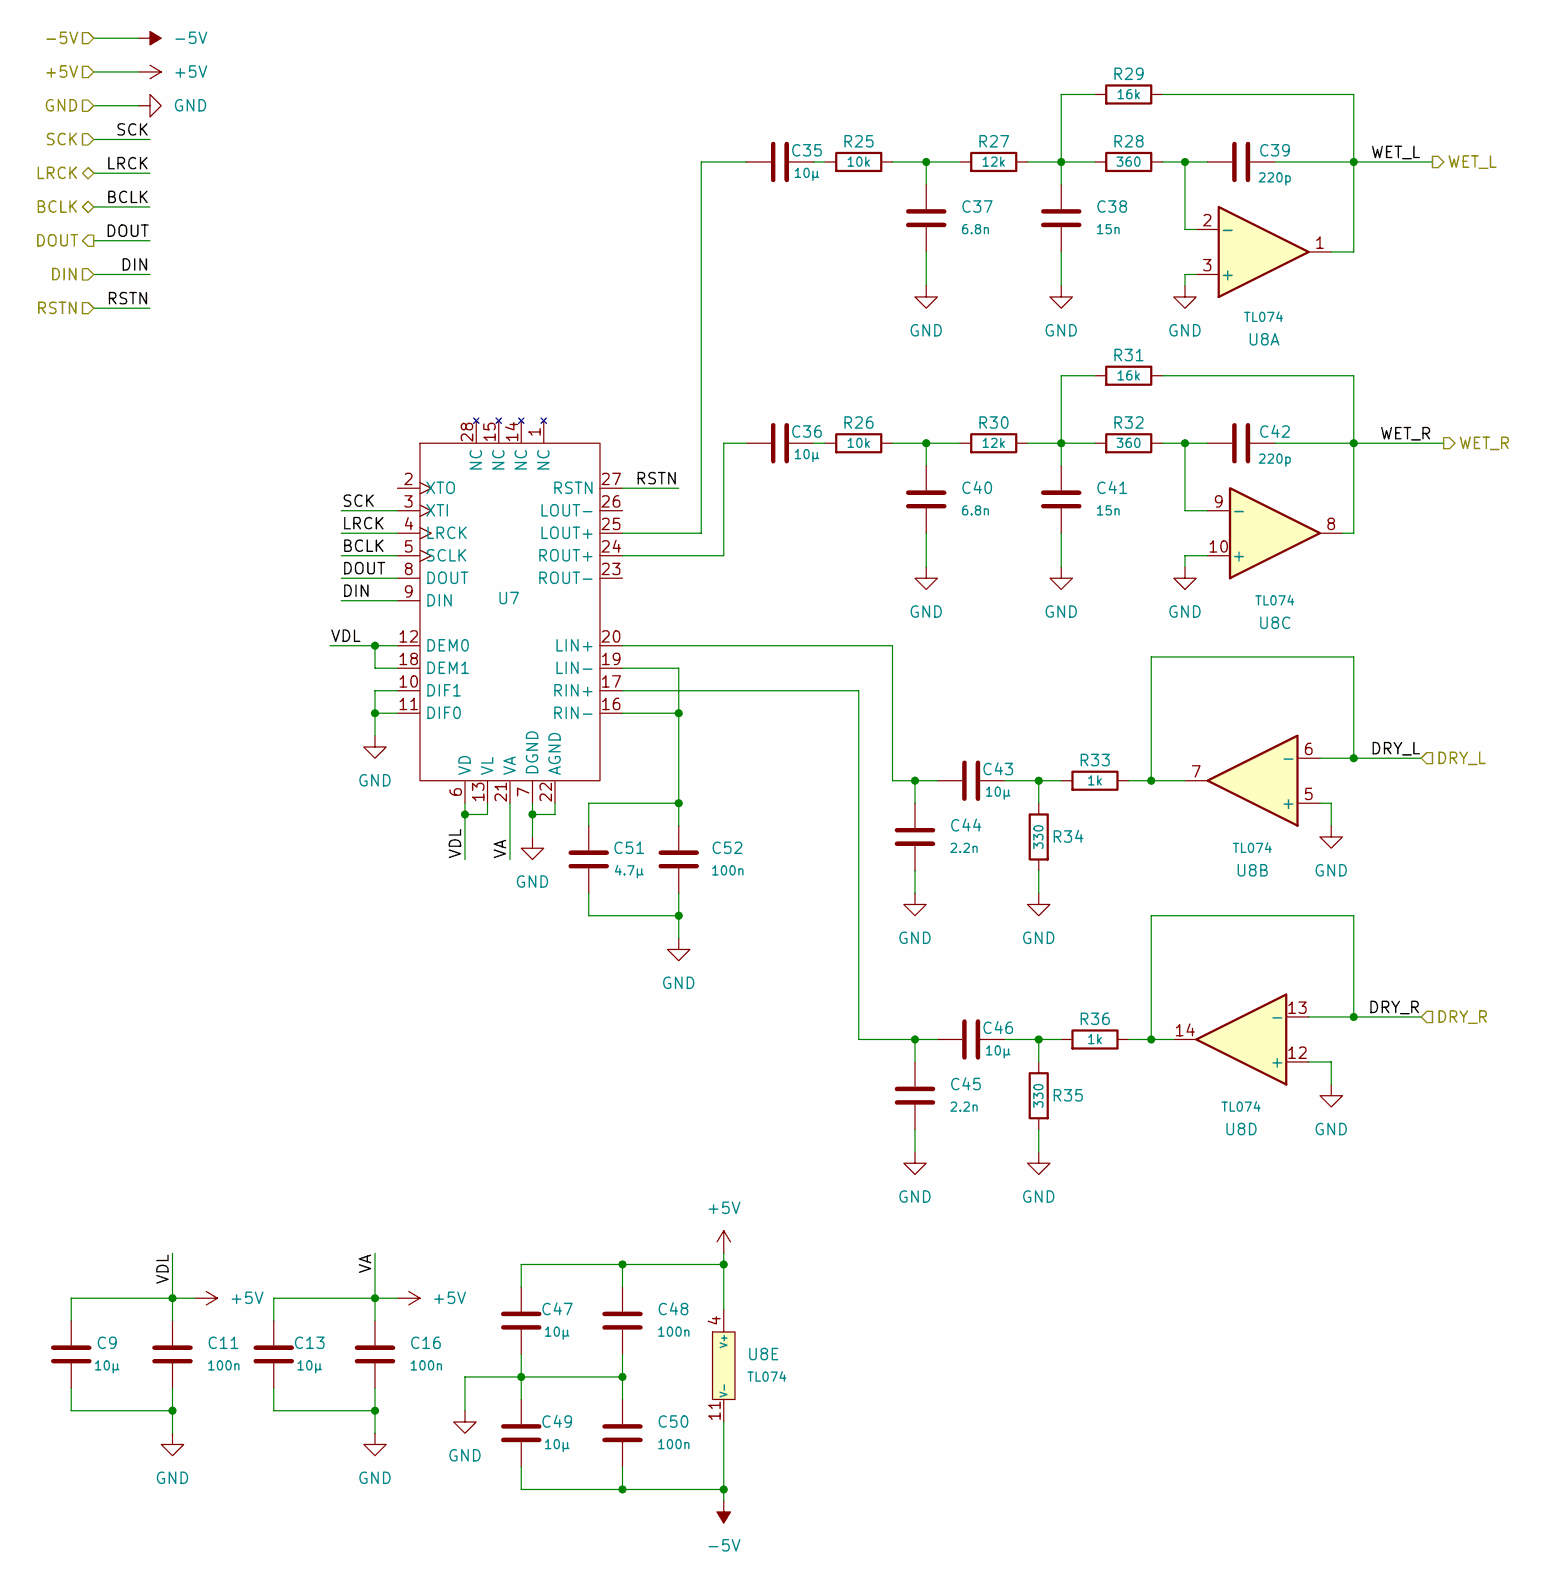
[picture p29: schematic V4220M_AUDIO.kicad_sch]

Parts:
C9, C13, C35, C36, C43, C46, C47, C49: 10µ; CCMS1206
C11, C16, C48, C50, C52: 100n; CCMS1206
C37, C40: 6.8n; CCMS1206
C38, C41: 15n; CCMS1206
C39, C42: 220p; CCMS1206
C44, C45: 2.2n; CCMS1206
C51: 4.7µ; CCMS1206
R25, R26: 10k; RCMS1206
R27, R30: 12k; RCMS1206
R28, R32: 360; RCMS1206
R29, R31: 16k; RCMS1206
R33, R36: 1k; RCMS1206
R34, R35: 330; RCMS1206
U7: V4220M
U8: TL074; SOIC-14_3.9x8.7mm_P1.27mm

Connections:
+5V: C9.1, C11.1, C13.1, C16.1, C47.1, C48.1, U7.6 (VD), U7.12 (DEM0), U7.13 (VL), U7.18 (DEM1), U7.21 (VA), U8.4 (V+); also elsewhere on the board
-5V: C49.2, C50.2, U8.11 (V-); also elsewhere on the board
/BCLK: U7.5 (SCLK); also elsewhere on the board
/DIN: U7.9 (DIN); also elsewhere on the board
/DOUT: U7.8 (DOUT); also elsewhere on the board
/DRY_L: R33.2, U8.6 (-), U8.7; also elsewhere on the board
/DRY_R: R36.2, U8.13 (-), U8.14; also elsewhere on the board
/LRCK: U7.4 (LRCK); also elsewhere on the board
/RSTN: U7.27 (RSTN); also elsewhere on the board
/SCK: U7.3 (XTI); also elsewhere on the board
/WET_L: C39.2, R29.2, U8.1; also elsewhere on the board
/WET_R: C42.2, R31.2, U8.8; also elsewhere on the board
GND: C9.2, C11.2, C13.2, C16.2, C37.2, C38.2, C40.2, C41.2, C44.2, C45.2, C47.2, C48.2, C49.1, C50.1, C51.2, C52.2, R34.1, R35.1, U7.7 (DGND), U7.10 (DIF1), U7.11 (DIF0), U7.22 (AGND), U8.3 (+), U8.5 (+), U8.10 (+), U8.12 (+); also elsewhere on the board
unnamed: C35.2, R25.1
unnamed: C36.2, R26.1
unnamed: C37.1, R25.2, R27.1
unnamed: C38.1, R27.2, R28.1, R29.1
unnamed: C40.1, R26.2, R30.1
unnamed: C41.1, R30.2, R31.1, R32.1
unnamed: C43.2, R33.1, R34.2
unnamed: C46.2, R35.2, R36.1
unnamed: C43.1, C44.1, U7.20 (LIN+)
unnamed: C51.1, C52.1, U7.16 (RIN-), U7.19 (LIN-)
unnamed: C35.1, U7.25 (LOUT+)
unnamed: C45.1, C46.1, U7.17 (RIN+)
unnamed: C36.1, U7.24 (ROUT+)
unnamed: C39.1, R28.2, U8.2 (-)
unnamed: C42.1, R32.2, U8.9 (-)

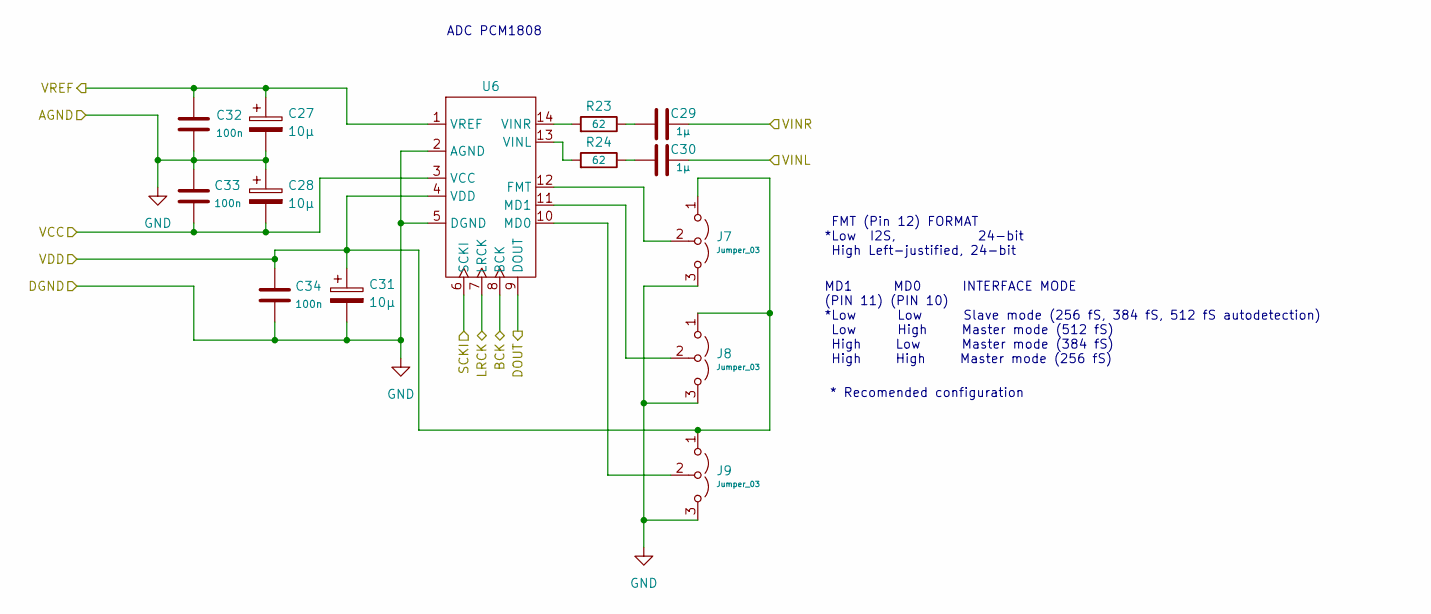
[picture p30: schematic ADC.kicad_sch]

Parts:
C27, C28, C31: 10µ; CP_Elec_4x3
C29, C30: 1µ; CCMS1206
C32, C33, C34: 100n; CCMS1206
J7, J8, J9: Jumper_03; MA01-03
R23, R24: 62; RCMS1206
U6: PCM1808

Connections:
+3V3: C31.1, C34.1, J7.1 (A), J8.1 (A), J9.1 (A), U6.4 (VDD); also elsewhere on the board
+5V: C28.2, C33.2, U6.3 (VCC); also elsewhere on the board
/ADC/VREF: C27.1, C32.1, U6.1 (VREF)
/BCLK: U6.8 (BCK); also elsewhere on the board
/DIN: U6.9 (DOUT); also elsewhere on the board
/DRY_L: C30.1; also elsewhere on the board
/DRY_R: C29.1; also elsewhere on the board
/LRCK: U6.7 (LRCK); also elsewhere on the board
/SCK: U6.6 (SCKI); also elsewhere on the board
GND: C27.2, C28.1, C31.2, C32.2, C33.1, C34.2, J7.3 (B), J8.3 (B), J9.3 (B), U6.2 (AGND), U6.5 (DGND); also elsewhere on the board
unnamed: C29.2, R23.2
unnamed: C30.2, R24.2
unnamed: J7.2 (C), U6.12 (FMT)
unnamed: J8.2 (C), U6.11 (MD1)
unnamed: J9.2 (C), U6.10 (MD0)
unnamed: R24.1, U6.13 (VINL)
unnamed: R23.1, U6.14 (VINR)

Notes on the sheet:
* Recomended configuration
MD1 MD0 INTERFACE MODE (PIN 11) (PIN 10) *Low Low Slave mode (256 fS, 384 fS, 512 fS autodetection) Low High Master mode (512 fS) High Low Master mode (384 fS) High High Master mode (256 fS)
ADC PCM1808
FMT (Pin 12) FORMAT *Low I2S, 24-bit High Left-justified, 24-bit

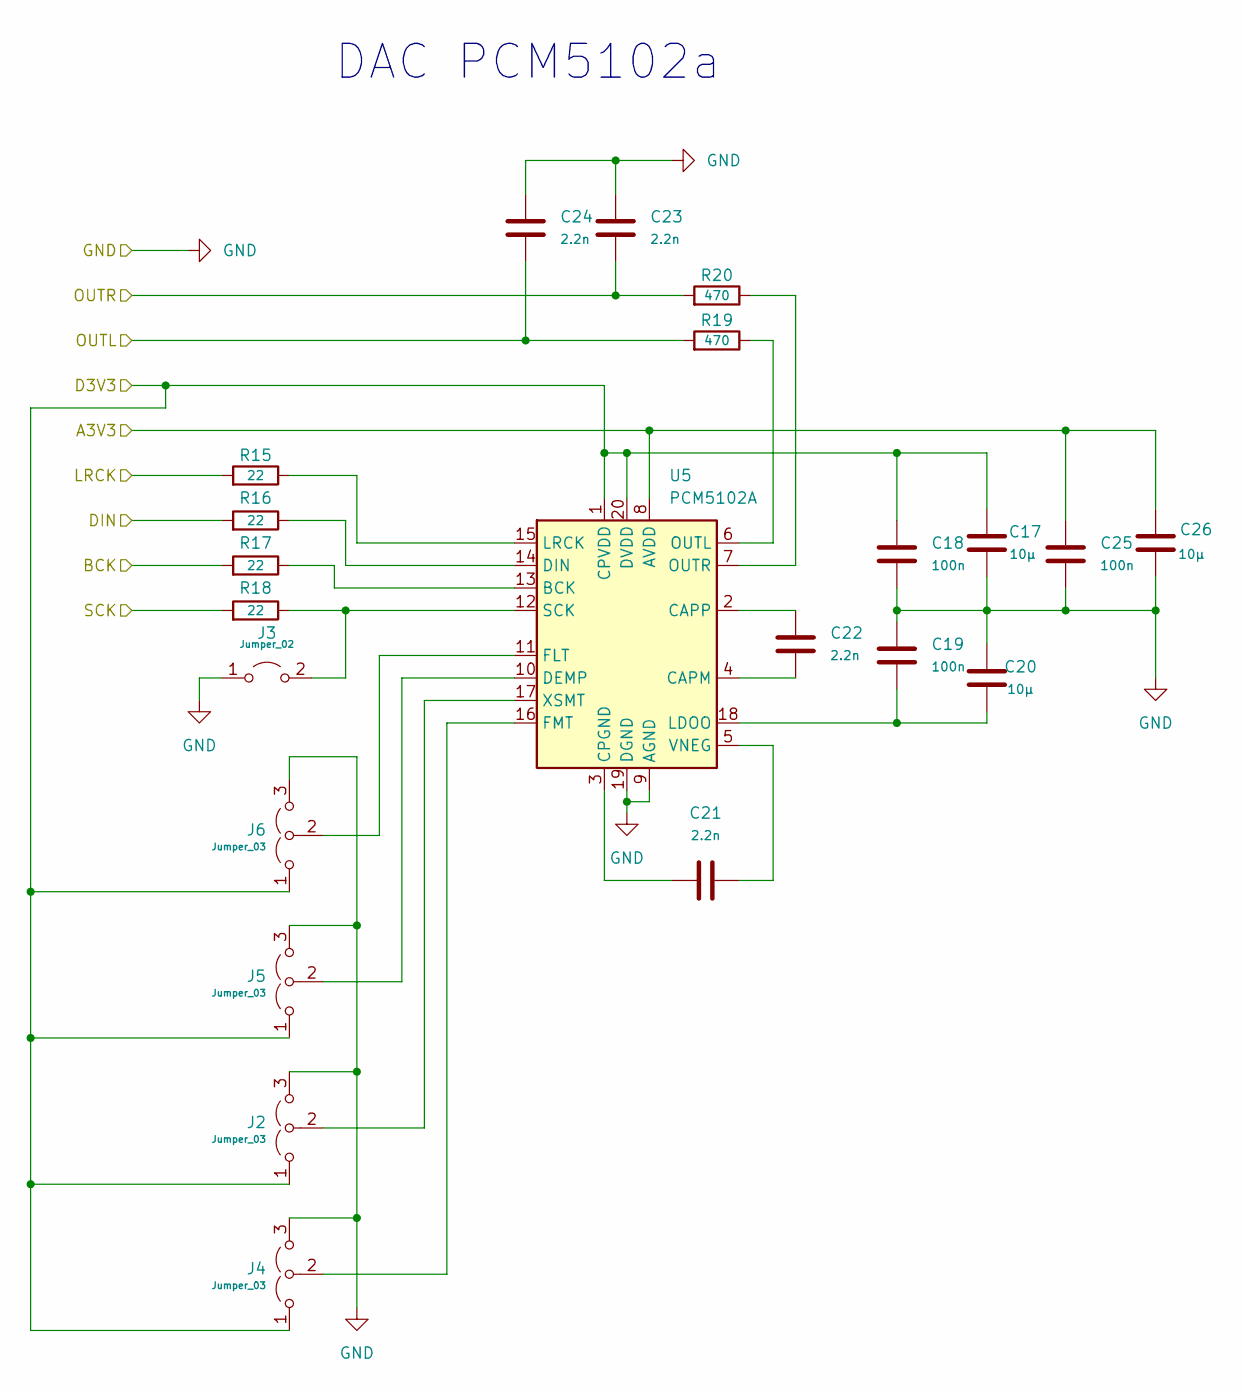
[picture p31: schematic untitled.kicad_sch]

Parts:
C17, C20, C26: 10µ; CCMS1206
C18, C19, C25: 100n; CCMS1206
C21, C22, C23, C24: 2.2n; CCMS1206
J2, J4, J5, J6: Jumper_03; MA01-03
J3: Jumper_02; MA01-02
R15, R16, R17, R18: 22; RCMS1206
R19, R20: 470; RCMS1206
U5: PCM5102A; TSSOP-20_4.4x6.5mm_P0.65mm

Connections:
+3V3: C17.2, C18.1, C25.1, C26.2, J2.1 (A), J4.1 (A), J5.1 (A), J6.1 (A), U5.1 (CPVDD), U5.8 (AVDD), U5.20 (DVDD); also elsewhere on the board
/BCLK: R17.1; also elsewhere on the board
/DOUT: R16.1; also elsewhere on the board
/LRCK: R15.1; also elsewhere on the board
/SCK: R18.1; also elsewhere on the board
/WET_L: C24.2, R19.1; also elsewhere on the board
/WET_R: C23.2, R20.1; also elsewhere on the board
GND: C17.1, C18.2, C19.1, C20.2, C23.1, C24.1, C25.2, C26.1, J2.3 (B), J3.1 (A), J4.3 (B), J5.3 (B), J6.3 (B), U5.9 (AGND), U5.19 (DGND); also elsewhere on the board
unnamed: J2.2 (C), U5.17 (XSMT)
unnamed: J3.2 (B), R18.2, U5.12 (SCK)
unnamed: J4.2 (C), U5.16 (FMT)
unnamed: J5.2 (C), U5.10 (DEMP)
unnamed: J6.2 (C), U5.11 (FLT)
unnamed: R17.2, U5.13 (BCK)
unnamed: C22.2, U5.4 (CAPM)
unnamed: C22.1, U5.2 (CAPP)
unnamed: C21.2, U5.3 (CPGND)
unnamed: R16.2, U5.14 (DIN)
unnamed: C19.2, C20.1, U5.18 (LDOO)
unnamed: R15.2, U5.15 (LRCK)
unnamed: R19.2, U5.6 (OUTL)
unnamed: R20.2, U5.7 (OUTR)
unnamed: C21.1, U5.5 (VNEG)

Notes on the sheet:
DAC PCM5102a

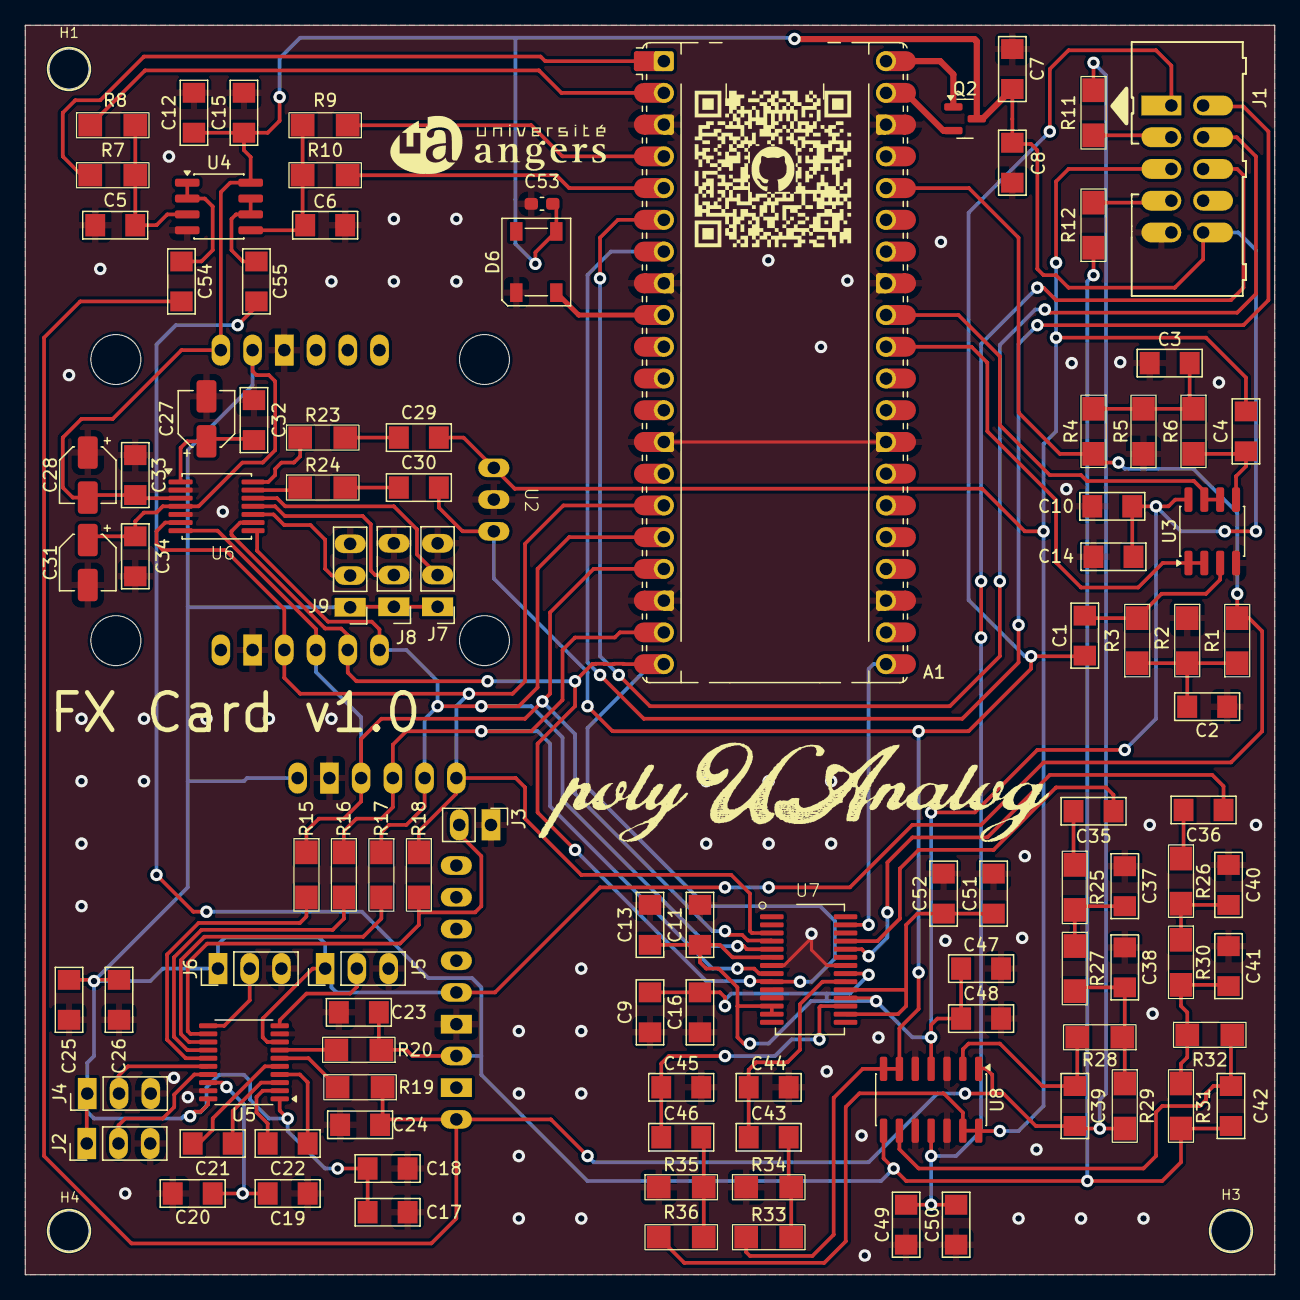
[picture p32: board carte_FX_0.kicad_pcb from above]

Board: 2 copper layers, 100.0 x 100.0 mm, 110 parts (0 on the bottom side), 73 nets.

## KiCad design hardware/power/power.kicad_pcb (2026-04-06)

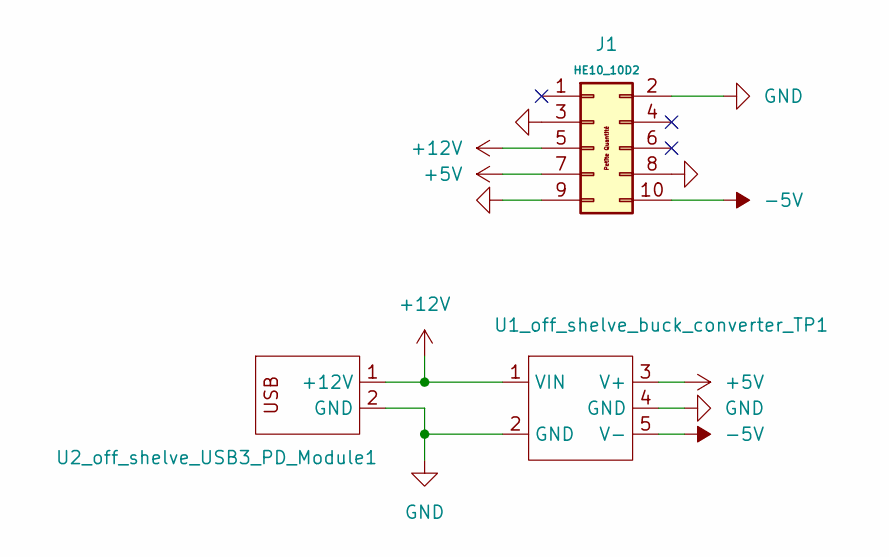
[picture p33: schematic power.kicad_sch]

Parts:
J1: HE10_10D2; 09185107324
U1_off_shelve_buck_converter_TP1: XL5430
U2_off_shelve_USB3_PD_Module1: USB_power_delivery_12V

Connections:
+5V: J1.7, U1_off_shelve_buck_converter_TP1.3 (V+)
+12V: J1.5, U1_off_shelve_buck_converter_TP1.1 (VIN), U2_off_shelve_USB3_PD_Module1.1 (+12V)
-5V: J1.10, U1_off_shelve_buck_converter_TP1.5 (V-)
GND: J1.2, J1.3, J1.8, J1.9, U1_off_shelve_buck_converter_TP1.2 (GND), U1_off_shelve_buck_converter_TP1.4 (GND), U2_off_shelve_USB3_PD_Module1.2 (GND)

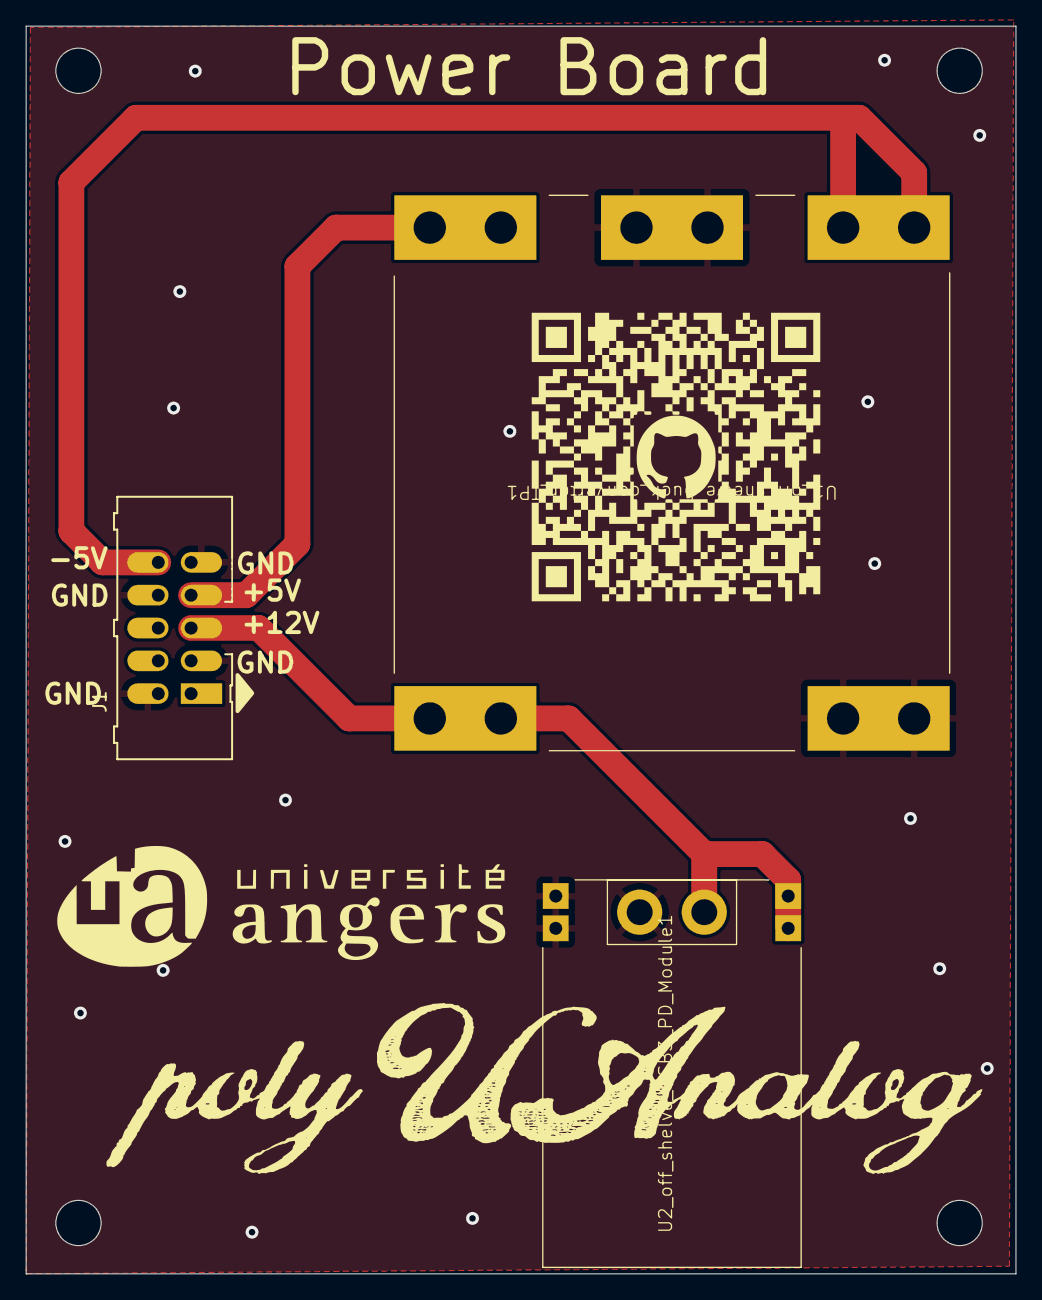
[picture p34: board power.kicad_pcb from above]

Board: 2 copper layers, 76.6 x 96.6 mm, 3 parts (0 on the bottom side), 4 nets.

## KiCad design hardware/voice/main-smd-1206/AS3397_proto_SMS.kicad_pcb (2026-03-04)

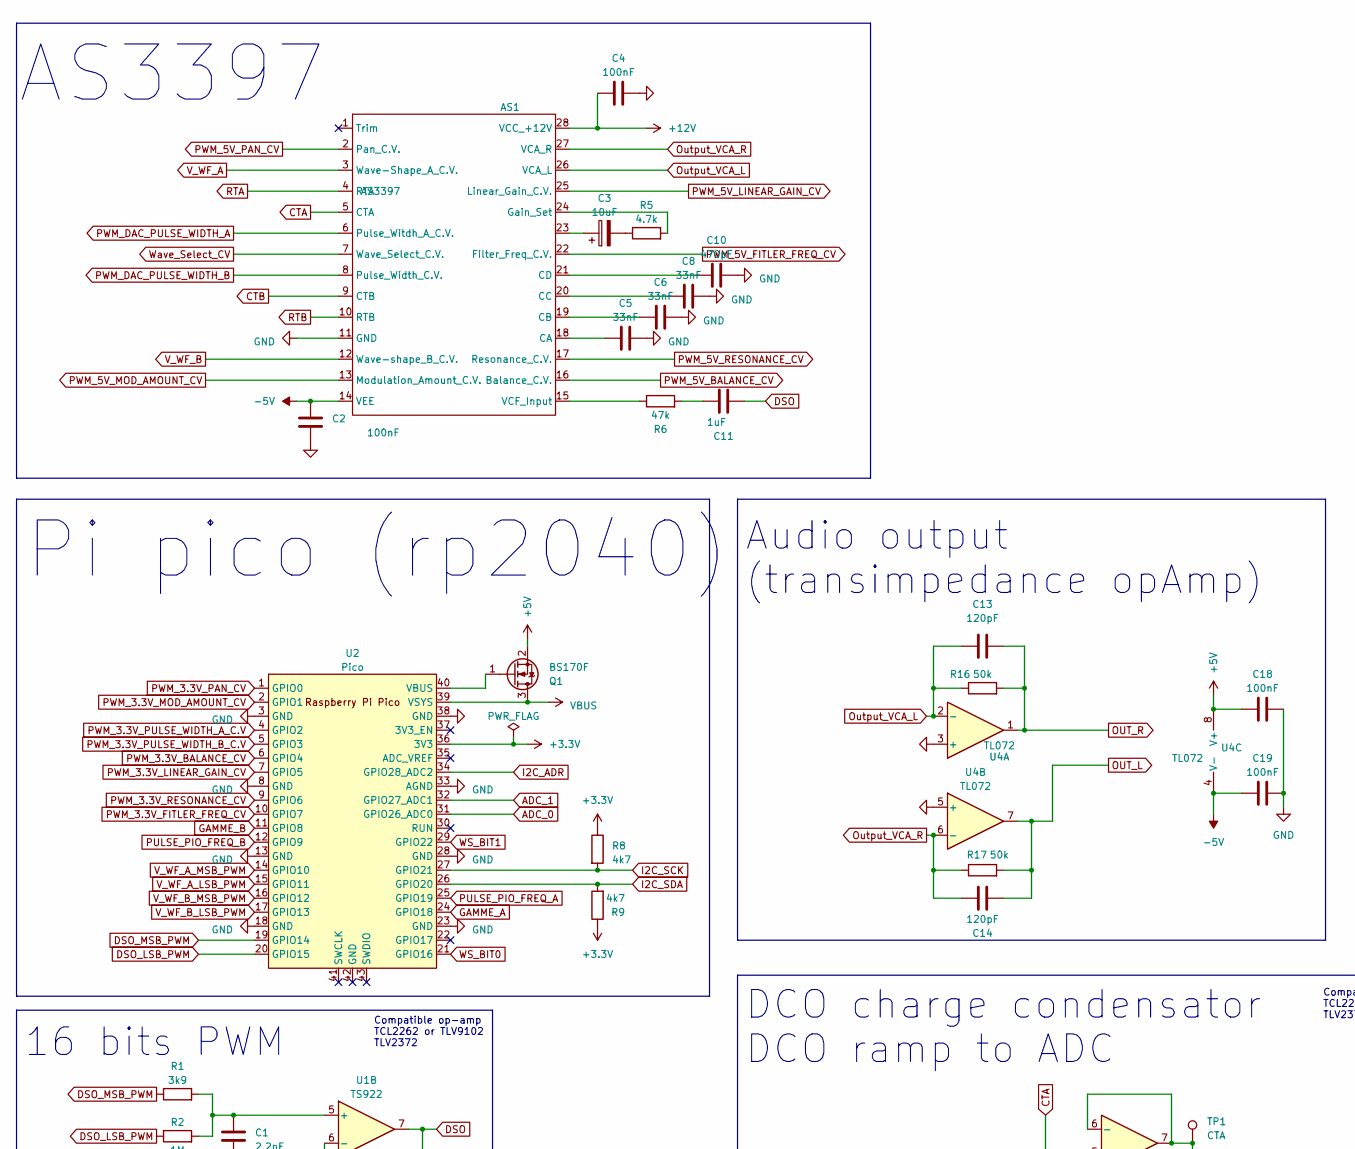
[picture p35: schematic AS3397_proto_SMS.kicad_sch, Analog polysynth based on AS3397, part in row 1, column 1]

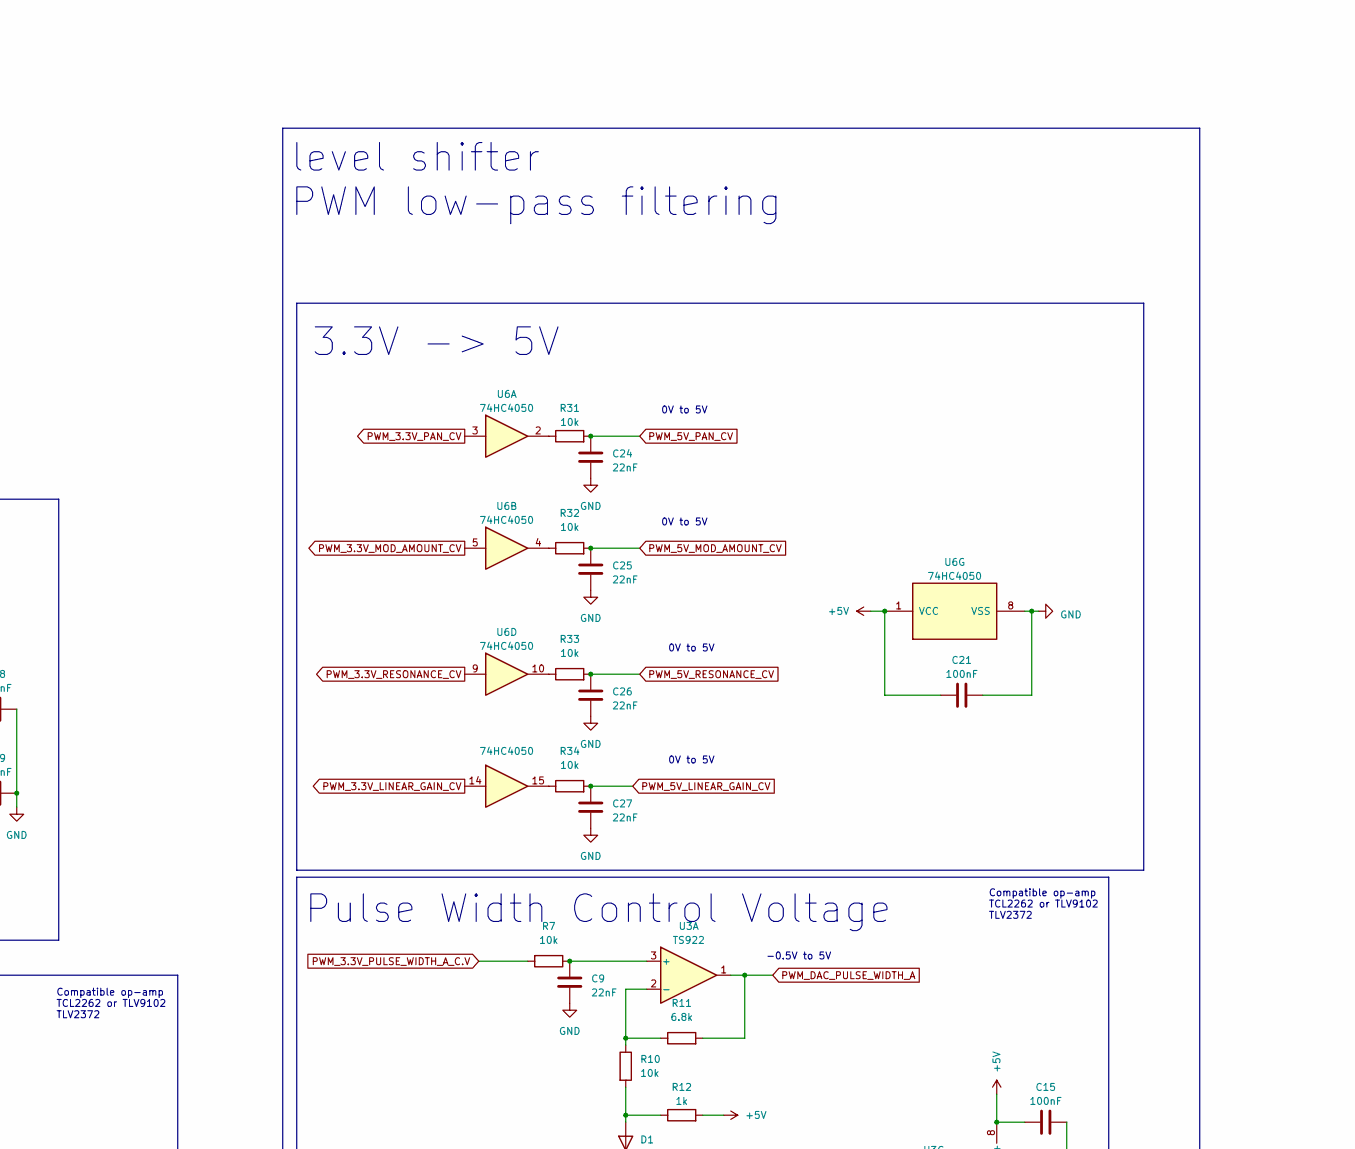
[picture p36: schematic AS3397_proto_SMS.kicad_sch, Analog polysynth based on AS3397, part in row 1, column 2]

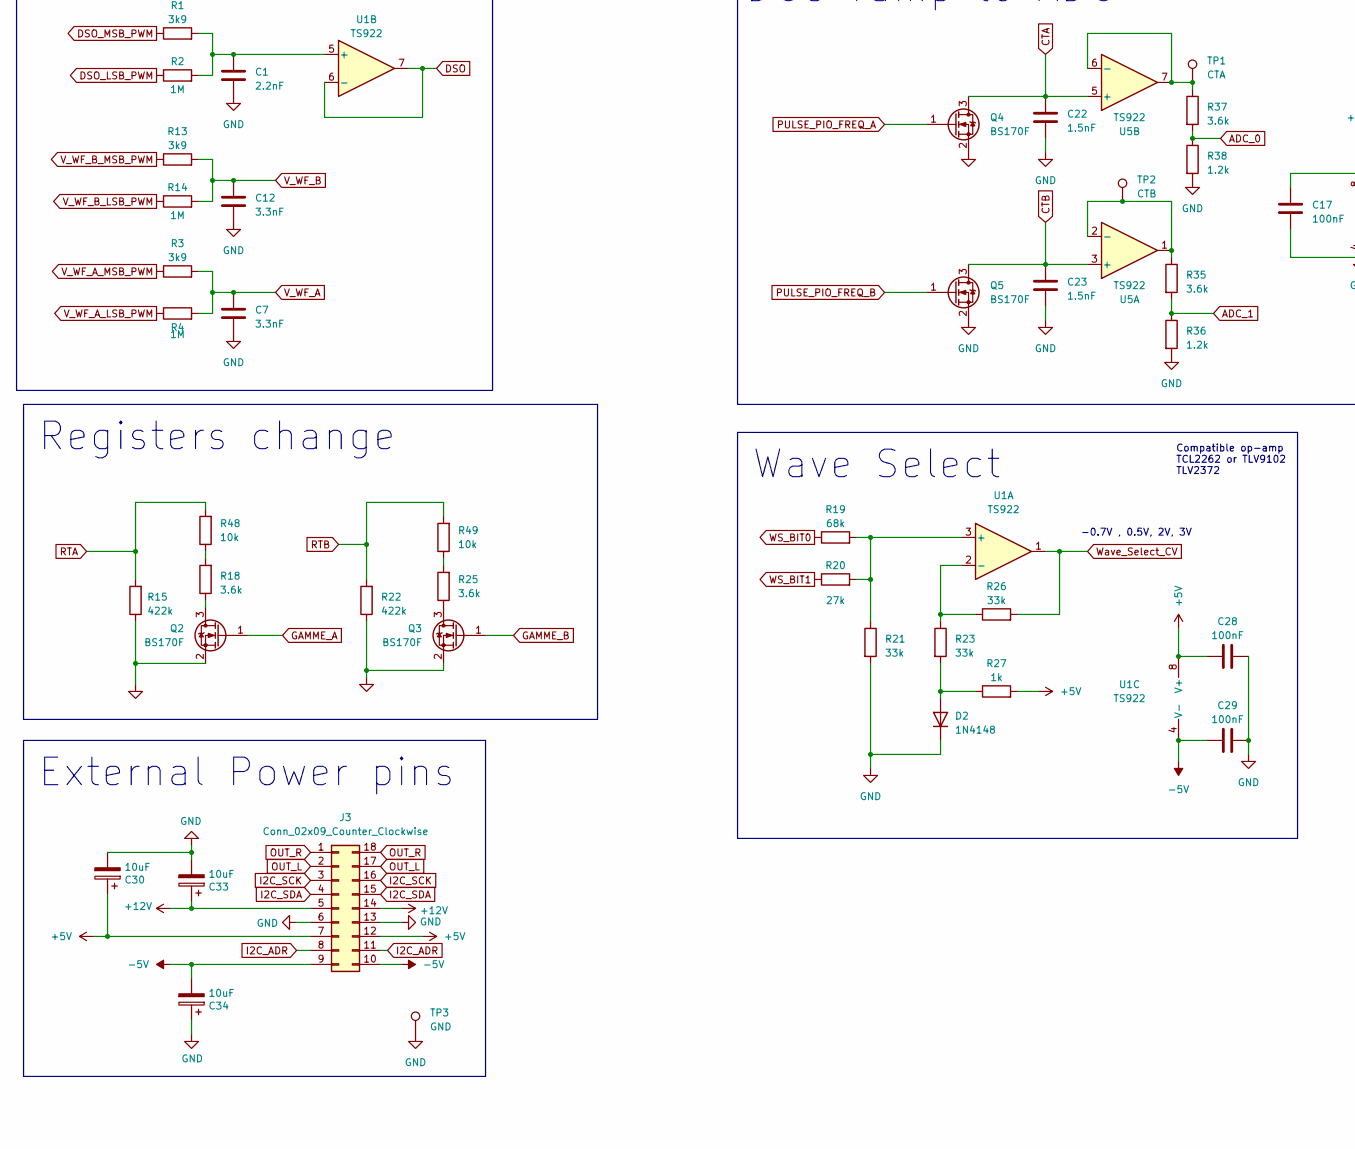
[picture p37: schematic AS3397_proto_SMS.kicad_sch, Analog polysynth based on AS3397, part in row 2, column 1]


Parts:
AS1: AS3397; SOIC-28W_7.5x18.7mm_P1.27mm
C1: 2.2nF; C_1206_3216Metric_Pad1.33x1.80mm_HandSolder
C2, C4, C15, C16, C17, C18, C19, C21, C28, C29, C31, C32: 100nF; C_1206_3216Metric_Pad1.33x1.80mm_HandSolder
C3, C30, C33, C34: 10uF; C_1206_3216Metric_Pad1.33x1.80mm_HandSolder
C5, C6, C8: 33nF; C_1206_3216Metric_Pad1.33x1.80mm_HandSolder
C7, C12: 3.3nF; C_1206_3216Metric_Pad1.33x1.80mm_HandSolder
C9, C20, C24, C25, C26, C27, C35, C36: 22nF; C_1206_3216Metric_Pad1.33x1.80mm_HandSolder
C10: 470pF; C_0805_2012Metric_Pad1.18x1.45mm_HandSolder
C11: 1uF; C_1206_3216Metric_Pad1.33x1.80mm_HandSolder
C13, C14: 120pF; C_0805_2012Metric_Pad1.18x1.45mm_HandSolder
C22, C23: 1.5nF; C_1206_3216Metric_Pad1.33x1.80mm_HandSolder
D1, D2, D3: 1N4148; D_SOD-323
J3: Conn_02x09_Counter_Clockwise; DIP-18_AS
Q1, Q2, Q3, Q4, Q5: BS170F; SOT-23
R1, R3, R13: 3k9; R_1206_3216Metric_Pad1.30x1.75mm_HandSolder
R2, R4, R14: 1M; R_1206_3216Metric_Pad1.30x1.75mm_HandSolder
R5: 4.7k; R_1206_3216Metric_Pad1.30x1.75mm_HandSolder
R6: 47k; R_1206_3216Metric_Pad1.30x1.75mm_HandSolder
R7, R10, R24, R28, R31, R32, R33, R34, R39, R40, R43, R44, R47, R48, R49: 10k; R_1206_3216Metric_Pad1.30x1.75mm_HandSolder
R8, R9: 4k7; R_1206_3216Metric_Pad1.30x1.75mm_HandSolder
R11, R29: 6.8k; R_1206_3216Metric_Pad1.30x1.75mm_HandSolder
R12, R27, R30: 1k; R_1206_3216Metric_Pad1.30x1.75mm_HandSolder
R15, R22: 422k; R_1206_3216Metric_Pad1.30x1.75mm_HandSolder
R16, R17: 50k; R_1206_3216Metric_Pad1.30x1.75mm_HandSolder
R18, R25, R35, R37: 3.6k; R_1206_3216Metric_Pad1.30x1.75mm_HandSolder
R19: 68k; R_1206_3216Metric_Pad1.30x1.75mm_HandSolder
R20: 27k; R_1206_3216Metric_Pad1.30x1.75mm_HandSolder
R21, R23, R26: 33k; R_1206_3216Metric_Pad1.30x1.75mm_HandSolder
R36, R38: 1.2k; R_1206_3216Metric_Pad1.30x1.75mm_HandSolder
R41: 22k; R_1206_3216Metric_Pad1.30x1.75mm_HandSolder
R42: 470; R_1206_3216Metric_Pad1.30x1.75mm_HandSolder
R45: 28k; R_1206_3216Metric_Pad1.30x1.75mm_HandSolder
R46: 680; R_1206_3216Metric_Pad1.30x1.75mm_HandSolder
TP1: CTA; PinHeader_1x01_P2.54mm_Vertical
TP2: CTB; PinHeader_1x01_P2.54mm_Vertical
TP3: GND; PinHeader_1x01_P2.54mm_Vertical
U1, U3, U5, U7: TS922; SOIC-8_3.9x4.9mm_P1.27mm
U2: Pico; RPi_Pico_SMD_TH
U4: TL072; SOIC-8_3.9x4.9mm_P1.27mm
U6: 74HC4050; SOIC-16_3.9x9.9mm_P1.27mm

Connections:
+3.3V: R8.1, R9.1, U2.36 (3V3)
+5V: C15.1, C18.1, C21.1, C28.1, C30.1, C31.1, J3.7, J3.12, Q1.2 (S), R12.2, R27.2, R30.2, R44.2, R46.2, U1.8 (V+), U3.8 (V+), U4.8 (V+), U6.1 (VCC), U7.8 (V+)
+12V: AS1.28 (VCC_+12V), C4.1, C17.2, C33.1, J3.5, J3.14, U5.8 (V+)
-5V: AS1.14 (VEE), C2.1, C16.1, C19.1, C29.1, C32.1, C34.2, J3.9, J3.10, U1.4 (V-), U3.4 (V-), U4.4 (V-), U7.4 (V-)
ADC_0: R37.2, R38.1, U2.31 (GPIO26_ADC0)
ADC_1: R35.2, R36.1, U2.32 (GPIO27_ADC1)
CTA: AS1.5 (CTA), C22.1, Q4.3 (D), U5.5 (+)
CTB: AS1.9 (CTB), C23.1, Q5.3 (D), U5.3 (+)
DSO: C11.2, U1.6 (-), U1.7
DSO_LSB_PWM: R2.1, U2.20 (GPIO15)
DSO_MSB_PWM: R1.1, U2.19 (GPIO14)
GAMME_A: Q2.1 (G), U2.24 (GPIO18)
GAMME_B: Q3.1 (G), U2.11 (GPIO8)
GND: AS1.11 (GND), C1.1, C2.2, C4.2, C5.2, C6.1, C7.1, C8.2, C9.2, C10.2, C12.1, C15.2, C16.2, C17.1, C18.2, C19.2, C20.2, C21.2, C22.2, C23.2, C24.2, C25.2, C26.2, C27.2, C28.2, C29.2, C30.2, C31.2, C32.2, C33.2, C34.1, C35.2, C36.2, D1.1 (K), D2.1 (K), D3.1 (K), J3.6, J3.13, Q2.2 (S), Q3.2 (S), Q4.2 (S), Q5.2 (S), R15.1, R21.2, R22.1, R36.2, R38.2, R42.1, TP3.1, U2.3 (GND), U2.8 (GND), U2.13 (GND), U2.18 (GND), U2.23 (GND), U2.28 (GND), U2.33 (AGND), U2.38 (GND), U4.3 (+), U4.5 (+), U5.4 (V-), U6.8 (VSS)
I2C_ADR: J3.8, J3.11, U2.34 (GPIO28_ADC2)
I2C_SCK: J3.3, J3.16, R8.2, U2.27 (GPIO21)
I2C_SDA: J3.4, J3.15, R9.2, U2.26 (GPIO20)
unnamed: AS1.18 (CA), C5.1
unnamed: AS1.19 (CB), C6.2
unnamed: AS1.20 (CC), C8.1
unnamed: AS1.21 (CD), C10.1
unnamed: AS1.24 (Gain_Set), R5.2
unnamed: AS1.23, C3.1
unnamed: AS1.15 (VCF_Input), R6.1
unnamed: C3.2, R5.1
unnamed: C11.1, R6.2
unnamed: D1.2 (A), R10.2, R12.1
unnamed: D2.2 (A), R23.2, R27.1
unnamed: D3.2 (A), R28.2, R30.1
unnamed: Q1.1 (G), U2.40 (VBUS)
unnamed: Q2.3 (D), R18.1
unnamed: Q3.3 (D), R25.1
unnamed: R18.2, R48.1
unnamed: R25.2, R49.1
unnamed: R31.1, U6.2
unnamed: R32.1, U6.4
unnamed: R33.1, U6.10
unnamed: R34.1, U6.15
unnamed: R41.2, R42.2, R46.1
unnamed: R43.2, R44.1
unnamed: R19.2, R20.2, R21.1, U1.3 (+)
unnamed: R23.1, R26.1, U1.2 (-)
unnamed: C1.2, R1.2, R2.2, U1.5 (+)
unnamed: C9.1, R7.1, U3.3 (+)
unnamed: R10.1, R11.1, U3.2 (-)
unnamed: C20.1, R24.1, U3.5 (+)
unnamed: R28.1, R29.1, U3.6 (-)
unnamed: R35.1, TP2.1, U5.1, U5.2 (-)
unnamed: R37.1, TP1.1, U5.6 (-), U5.7
unnamed: C36.1, R40.2, U7.3 (+)
unnamed: R43.1, R47.1, U7.2 (-)
unnamed: C35.1, R39.2, U7.5 (+)
unnamed: R41.1, R45.1, U7.6 (-)
OUT_L: C14.2, J3.2, J3.17, R17.2, U4.7
OUT_R: C13.2, J3.1, J3.18, R16.2, U4.1
Output_VCA_L: AS1.26 (VCA_L), C13.1, R16.1, U4.2 (-)
Output_VCA_R: AS1.27 (VCA_R), C14.1, R17.1, U4.6 (-)
PULSE_PIO_FREQ_A: Q4.1 (G), U2.25 (GPIO19)
PULSE_PIO_FREQ_B: Q5.1 (G), U2.12 (GPIO9)
PWM_3.3V_BALANCE_CV: R40.1, U2.6 (GPIO4)
PWM_3.3V_FITLER_FREQ_CV: R39.1, U2.10 (GPIO7)
PWM_3.3V_LINEAR_GAIN_CV: U2.7 (GPIO5), U6.14
PWM_3.3V_MOD_AMOUNT_CV: U2.2 (GPIO1), U6.5
PWM_3.3V_PAN_CV: U2.1 (GPIO0), U6.3
PWM_3.3V_PULSE_WIDTH_A_C.V: R7.2, U2.4 (GPIO2)
PWM_3.3V_PULSE_WIDTH_B_C.V: R24.2, U2.5 (GPIO3)
PWM_3.3V_RESONANCE_CV: U2.9 (GPIO6), U6.9
PWM_5V_BALANCE_CV: AS1.16 (Balance_C.V.), R47.2, U7.1
PWM_5V_FITLER_FREQ_CV: AS1.22 (Filter_Freq_C.V.), R45.2, U7.7
PWM_5V_LINEAR_GAIN_CV: AS1.25 (Linear_Gain_C.V.), C27.1, R34.2
PWM_5V_MOD_AMOUNT_CV: AS1.13 (Modulation_Amount_C.V.), C25.1, R32.2
PWM_5V_PAN_CV: AS1.2 (Pan_C.V.), C24.1, R31.2
PWM_5V_RESONANCE_CV: AS1.17 (Resonance_C.V.), C26.1, R33.2
PWM_DAC_PULSE_WIDTH_A: AS1.6 (Pulse_Witdh_A_C.V.), R11.2, U3.1
PWM_DAC_PULSE_WIDTH_B: AS1.8 (Pulse_Width_C.V.), R29.2, U3.7
RTA: AS1.4 (RTA), R15.2, R48.2
RTB: AS1.10 (RTB), R22.2, R49.2
VBUS: Q1.3 (D), U2.39 (VSYS)
V_WF_A: AS1.3 (Wave-Shape_A_C.V.), C7.2, R3.2, R4.2
V_WF_A_LSB_PWM: R4.1, U2.15 (GPIO11)
V_WF_A_MSB_PWM: R3.1, U2.14 (GPIO10)
V_WF_B: AS1.12 (Wave-shape_B_C.V.), C12.2, R13.2, R14.2
V_WF_B_LSB_PWM: R14.1, U2.17 (GPIO13)
V_WF_B_MSB_PWM: R13.1, U2.16 (GPIO12)
WS_BIT0: R19.1, U2.21 (GPIO16)
WS_BIT1: R20.1, U2.29 (GPIO22)
Wave_Select_CV: AS1.7 (Wave_Select_C.V.), R26.2, U1.1

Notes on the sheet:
Compatible op-amp TCL2262 or TLV9102 TLV2372
3.3V -> 5V
Wave Select
16 bits PWM
-0.5V to 5V
level shifter PWM low-pass filtering
0V to 5V
Pi pico (rp2040)
Filter CutOff & Balance Control Voltage
Pulse Width Control Voltage
AS3397
External Power pins
-0.7V , 0.5V, 2V, 3V
Audio output (transimpedance opAmp)
Registers change
DCO charge condensator DCO ramp to ADC
-2.5V to 2.5V
-2.5V to 5V


Board: 2 copper layers, 70.5 x 100.2 mm, 105 parts (0 on the bottom side), 87 nets.

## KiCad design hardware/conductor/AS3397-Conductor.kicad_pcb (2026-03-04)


Board: 2 copper layers, 97.3 x 97.8 mm, 53 parts (0 on the bottom side), 47 nets.

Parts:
A1: SC0918; MODULE_SC0918
C1, C2, C6, C7: 120pF; C_1206_3216Metric_Pad1.33x1.80mm_HandSolder
C3, C4, C5, C8, C9: 100n; C_1206_3216Metric_Pad1.33x1.80mm_HandSolder
D1: 1N4148; D_DO-35_SOD27_P7.62mm_Horizontal
D2: LED; D_A-405_P2.54mm_Vertical_AnodeUp
D3: 1N5819; D_DO-41_SOD81_P10.16mm_Horizontal
D4, D5: SK6812; LED_SK6812_PLCC4_5.0x5.0mm_P3.2mm
J1: Micro_SD_Card; J_SD_Card-micro_socket_A
J2: ADC_connector; JST_EH_B4B-EH-A_1x04_P2.50mm_Vertical
J3: Conn_01x06_Socket; PinHeader_1x06_P2.54mm_Vertical
J4, J11, J15: I2C controller; JST_EH_B4B-EH-A_1x04_P2.50mm_Vertical
J5, J14: Conn_01x02_Socket; JST_EH_B2B-EH-A_1x02_P2.50mm_Vertical
J6: AudioJack3; Jack_3.5mm_Ledino_KB3SPRS_Horizontal
J7: Conn_POWER; PinHeader_2x05_P2.54mm_Vertical
J8: MIDI IN; MIDI_DIN5
J9: Conn_FX_1; PinHeader_2x05_P2.54mm_Vertical
J10: Conn_FX_2; PinHeader_2x05_P2.54mm_Vertical
J12: Conn_01x03_Socket_AudioOUT; JST_EH_B3B-EH-A_1x03_P2.50mm_Vertical
J13: Conn_FX_3; PinHeader_2x05_P2.54mm_Vertical
J16: Conn_01x06_Socket_SPI; PinSocket_1x06_P2.54mm_Vertical
J17, J18: Conn_01x03_Socket; PinHeader_1x03_P2.54mm_Vertical
J19: Conn_Voice; PinHeader_2x05_P2.54mm_Vertical
J20: Conn_FX_4; PinHeader_2x05_P2.54mm_Vertical
R1: 1K; R_1206_3216Metric_Pad1.30x1.75mm_HandSolder
R2, R3: 51; R_1206_3216Metric_Pad1.30x1.75mm_HandSolder
R9, R10, R22, R24: 10K; R_1206_3216Metric_Pad1.30x1.75mm_HandSolder
R18: 220; R_1206_3216Metric_Pad1.30x1.75mm_HandSolder
R19: 4k7; R_1206_3216Metric_Pad1.30x1.75mm_HandSolder
R20: 470; R_1206_3216Metric_Pad1.30x1.75mm_HandSolder
R21, R26: 5K1; R_1206_3216Metric_Pad1.30x1.75mm_HandSolder
R27, R28, R29, R30: 4K7; R_1206_3216Metric_Pad1.30x1.75mm_HandSolder
U2: 6N138; DIP-8_W7.62mm_LongPads
U3: OPA1679; SOIC-14_3.9x8.7mm_P1.27mm

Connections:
+3.3V: A1.36 (3V3_OUT), C5.2, D2.2 (A), J1.4 (VDD), J4.3, J11.3, J15.3, J16.2, J19.6, R2.1, R20.1, R27.2, R28.1, R29.2, R30.1
+5V: C3.1, C8.1, C9.1, D3.2 (A), D4.3 (VDD), D5.3 (VDD), J7.4, J9.10, J10.10, J13.10, J19.8, J20.10, U2.8 (VCC), U3.4 (V+)
+12V: J7.6, J9.8, J10.8, J13.8, J19.9, J20.8
-5V: C4.1, J7.1, J9.6, J10.6, J13.6, J19.4, J20.6, U3.11 (V-)
ADC0: A1.31 (GP26), J2.1
ADC1: A1.32 (GP27), J2.2
ADC2: A1.34 (GP28), J2.3
Dry_left: C1.2, J9.1, J10.1, J13.1, J20.1, R10.2, R22.1, U3.7
Dry_right: C2.2, J9.5, J10.5, J13.5, J20.5, R9.2, R24.1, U3.8
GND: A1.3 (GND), A1.8 (GND), A1.13 (GND), A1.18 (GND), A1.23 (GND), A1.28 (GND), A1.33 (AGND), A1.38 (GND), C3.2, C4.2, C5.1, C8.2, C9.2, D4.1 (VSS), D5.1 (VSS), J1.6 (VSS), J1.9 (SHIELD), J2.4, J3.1, J4.4, J6.S, J7.2, J7.3, J7.5, J7.7, J7.8, J7.9, J7.10, J9.9, J10.9, J11.4, J12.3, J13.9, J15.4, J16.1, J17.3, J18.3, J19.2, J19.10, J20.9, R19.2, U2.5 (GND), U3.3 (+), U3.5 (+), U3.10 (+), U3.12 (+)
GPIO4: A1.6 (GP4), J17.2
GPIO5: A1.7 (GP5), J17.1
GPIO14: A1.19 (GP14), D4.2 (DIN), J18.2
GPIO15: A1.20 (GP15), D5.2 (DIN), J18.1
GPIO18: A1.24 (GP18), J3.2
GPIO19: A1.25 (GP19), J3.3
GPIO20: A1.26 (GP20), J3.4
GPIO21: A1.27 (GP21), J3.5
GPIO22: A1.29 (GP22), J3.6
I2C_CTRL_SDA: A1.21 (GP16), J4.2, J9.4, J10.4, J11.2, J13.4, J15.2, J20.4, R29.1
I2C_CTRL_SDL: A1.22 (GP17), J4.1, J9.2, J10.2, J11.1, J13.2, J15.1, J20.2, R30.2
I2C_voices_SDA: A1.4 (GP2), J19.7, R27.1
I2C_voices_SDL: A1.5 (GP3), J19.5, R28.2
unnamed: A1.39 (VSYS), D3.1 (K)
unnamed: D1.2 (A), J8.5, J14.2, U2.3 (C2)
unnamed: D1.1 (K), R18.2, U2.2 (C1)
unnamed: D2.1 (K), R1.2
unnamed: J5.1, R2.2
unnamed: J5.2, R3.2
unnamed: J8.4, J14.1, R18.1
unnamed: R19.1, U2.7 (VO1)
Out_left: C7.2, J6.T, J12.1, R21.2, U3.1
Out_right: C6.2, J6.R, J12.2, R26.2, U3.14
RX_MIDI: A1.2 (GP1), R20.2, U2.6 (VO2)
SD_CS: A1.17 (GP13), J1.2 (DAT3/CD)
SD_MISO: A1.16 (GP12), J1.7 (DAT0)
SD_MOSI: A1.15 (GP11), J1.3 (CMD)
SD_SCLK: A1.14 (GP10), J1.5 (CLK)
SPI0_CS: A1.12 (GP9), J16.6
SPI0_RX: A1.11 (GP8), J16.5
SPI0_SCK: A1.9 (GP6), J16.3
SPI0_TX: A1.10 (GP7), J16.4
TX_MIDI: A1.1 (GP0), R1.1, R3.1
Wet_left: C7.1, J9.3, J10.3, J13.3, J20.3, R21.1, R22.2, U3.2 (-)
Wet_right: C6.1, J9.7, J10.7, J13.7, J20.7, R24.2, R26.1, U3.13 (-)
audio_analog_left: C1.1, J19.1, R10.1, U3.6 (-)
audio_analog_right: C2.1, J19.3, R9.1, U3.9 (-)

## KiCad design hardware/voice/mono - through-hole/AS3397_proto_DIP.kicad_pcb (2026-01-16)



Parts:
AS1: AS3397; SOIC-28W_7.5x18.7mm_P1.27mm
C1: 100uF; CP_Radial_D8.0mm_P5.00mm
C2, C5, C11: 10uF; CP_Radial_D5.0mm_P2.50mm
C3, C37: 1uF; CP_Radial_D5.0mm_P2.50mm
C4: 2.2nF; C_Rect_L7.0mm_W2.0mm_P5.00mm
C6, C10: 3.3nF; C_Rect_L7.0mm_W2.0mm_P5.00mm
C7, C8, C21, C22, C24, C26, C36, C40: 22nF; C_Rect_L7.0mm_W2.0mm_P5.00mm
C9, C12, C28, C29, C30, C31, C32, C33, C34, C35, C38, C39: 100nF; C_Rect_L7.0mm_W2.0mm_P5.00mm
C13, C14, C15: 33nF; C_Rect_L7.0mm_W2.0mm_P5.00mm
C16: 470pF; C_Disc_D4.3mm_W1.9mm_P5.00mm
C17, C18: 1.5nF; C_Rect_L7.0mm_W2.0mm_P5.00mm
C19, C20: 120pF; C_Disc_D4.3mm_W1.9mm_P5.00mm
C27: 1uF; C_Rect_L7.0mm_W2.0mm_P5.00mm
D1, D2, D5, D6: 1N4148; D_DO-35_SOD27_P7.62mm_Horizontal
D3, D4: BAT48; D_DO-35_SOD27_P7.62mm_Horizontal
H1, H2, H3, H4: H1; MountingHole_3.2mm_M3_DIN965_Pad_TopBottom
J1: +15V; BarrelJack_Horizontal
J2: MIDI IN; MIDI_DIN5
J3: OUTPUT; Jack_3.5mm_Ledino_KB3SPRS_Horizontal
J4: I2C; NS-Tech_Grove_1x04_P2mm_Vertical
Q2, Q3, Q4, Q5: BS170; TO-92_Wide
R1, R3, R9: 3k9; R_Axial_DIN0204_L3.6mm_D1.6mm_P7.62mm_Horizontal
R2, R4, R10: 1M; R_Axial_DIN0204_L3.6mm_D1.6mm_P7.62mm_Horizontal
R5, R6, R25, R26, R28, R30, R42, R43, R44, R45, R46, R47, R48, R51, R52: 10k; R_Axial_DIN0204_L3.6mm_D1.6mm_P7.62mm_Horizontal
R7, R8, R19: 4k7; R_Axial_DIN0204_L3.6mm_D1.6mm_P7.62mm_Horizontal
R11, R12: 422k; R_Axial_DIN0204_L3.6mm_D1.6mm_P7.62mm_Horizontal
R13: 220; R_Axial_DIN0204_L3.6mm_D1.6mm_P7.62mm_Horizontal
R14: 68k; R_Axial_DIN0204_L3.6mm_D1.6mm_P7.62mm_Horizontal
R15, R18, R35, R36: 33k; R_Axial_DIN0204_L3.6mm_D1.6mm_P7.62mm_Horizontal
R16: 4.7k; R_Axial_DIN0204_L3.6mm_D1.6mm_P7.62mm_Horizontal
R17: 47k; R_Axial_DIN0204_L3.6mm_D1.6mm_P7.62mm_Horizontal
R20, R21, R33, R34: 3.6k; R_Axial_DIN0204_L3.6mm_D1.6mm_P7.62mm_Horizontal
R22, R41: 470; R_Axial_DIN0204_L3.6mm_D1.6mm_P7.62mm_Horizontal
R23, R24: 50K; R_Axial_DIN0204_L3.6mm_D1.6mm_P7.62mm_Horizontal
R31, R32: 1.2k; R_Axial_DIN0204_L3.6mm_D1.6mm_P7.62mm_Horizontal
R37, R50, R54: 1k; R_Axial_DIN0204_L3.6mm_D1.6mm_P7.62mm_Horizontal
R38: 22k; R_Axial_DIN0204_L3.6mm_D1.6mm_P7.62mm_Horizontal
R39: 28k; R_Axial_DIN0204_L3.6mm_D1.6mm_P7.62mm_Horizontal
R40: 680; R_Axial_DIN0204_L3.6mm_D1.6mm_P7.62mm_Horizontal
R49, R53: 6.8k; R_Axial_DIN0204_L3.6mm_D1.6mm_P7.62mm_Horizontal
TP1: CTA; PinHeader_1x01_P2.54mm_Vertical
TP2: CTB; PinHeader_1x01_P2.54mm_Vertical
TP3: GND; PinHeader_1x01_P2.54mm_Vertical
TP4: PAN; PinHeader_1x01_P2.54mm_Vertical
TP5: MOD; PinHeader_1x01_P2.54mm_Vertical
TP6: PWA; PinHeader_1x01_P2.54mm_Vertical
TP7: RES; PinHeader_1x01_P2.54mm_Vertical
TP8: PWB; PinHeader_1x01_P2.54mm_Vertical
TP9: GAIN; PinHeader_1x01_P2.54mm_Vertical
TP10: FREQ; PinHeader_1x01_P2.54mm_Vertical
TP11: BAL; PinHeader_1x01_P2.54mm_Vertical
TP12: WSEL; PinHeader_1x01_P2.54mm_Vertical
TP13: DSO; PinHeader_1x01_P2.54mm_Vertical
TP14: WFA; PinHeader_1x01_P2.54mm_Vertical
TP15: WFB; PinHeader_1x01_P2.54mm_Vertical
TP16: FREQA; PinHeader_1x01_P2.54mm_Vertical
TP17: FREQB; PinHeader_1x01_P2.54mm_Vertical
TP18: OUTL; PinHeader_1x01_P2.54mm_Vertical
TP19: OUTR; PinHeader_1x01_P2.54mm_Vertical
TP20: -5V; PinHeader_1x01_P2.54mm_Vertical
TP21: +12V; PinHeader_1x01_P2.54mm_Vertical
TP22: +5V; PinHeader_1x01_P2.54mm_Vertical
U1: TC7662; DIP-8_W7.62mm
U2: LM7812; TO-92_Inline_Wide
U3: Pico; RPi_Pico_SMD_TH
U4, U8, U9, U11: TS922; DIP-8_W7.62mm_LongPads
U5: 6N138; DIP-8_W7.62mm_LongPads
U6: TL072; DIP-8_W7.62mm_LongPads
U7: 4050; DIP-16_W7.62mm_LongPads
U10: LM7805; TO-220-3_Vertical

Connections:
+3V3: R7.1, R8.1, R22.1, U3.36 (3V3)
+5V: C29.1, C30.1, C32.1, C34.1, C38.1, D4.1 (K), J4.3, R37.2, R40.2, R43.2, R50.2, R54.2, TP22.1, U1.8 (VDD), U3.40 (VBUS), U5.8 (VCC), U6.8 (V+), U7.1 (VCC), U8.8 (V+), U9.8 (V+), U11.8 (V+)
+12V: AS1.28 (VCC_+12V), C3.1, C12.1, C28.2, TP21.1, U2.3 (VO), U4.8 (V+)
+15V: C1.1, J1.1, U2.1 (VI), U10.1 (VI)
-5V: AS1.14 (VEE), C5.2, C9.1, C31.1, C33.1, C35.1, C39.1, TP20.1, U1.5 (VOUT), U6.4 (V-), U8.4 (V-), U9.4 (V-), U11.4 (V-)
ADC_0: R20.2, R31.1, U3.31 (GPIO26_ADC0)
ADC_1: R21.2, R32.1, U3.32 (GPIO27_ADC1)
CTA: AS1.5 (CTA), C17.1, Q4.1 (D), U4.5 (+)
CTB: AS1.9 (CTB), C18.1, Q2.1 (D), U4.3 (+)
DSO: C27.2, TP13.1, U8.6 (-), U8.7
DSO_LSB_PWM: R2.1, U3.20 (GPIO15)
DSO_MSB_PWM: R1.1, U3.19 (GPIO14)
GAMME_A: Q3.2 (G), U3.24 (GPIO18)
GAMME_B: Q5.2 (G), U3.11 (GPIO8)
GND: AS1.11 (GND), C1.2, C3.2, C4.1, C5.1, C6.1, C7.2, C8.2, C9.2, C10.1, C12.2, C13.2, C14.1, C15.2, C16.2, C17.2, C18.2, C21.2, C22.2, C24.2, C26.2, C28.1, C29.2, C30.2, C31.2, C32.2, C33.2, C34.2, C35.2, C36.2, C37.2, C38.2, C39.2, C40.2, D2.1 (K), D3.1 (K), D5.1 (K), D6.1 (K), H1.1, H2.1, H3.1, H4.1, J1.2, J3.S, J4.4, Q2.3 (S), Q3.3 (S), Q4.3 (S), Q5.3 (S), R11.1, R12.1, R19.2, R31.2, R32.2, R35.2, R41.1, TP3.1, U1.3 (GND), U2.2 (GND), U3.3 (GND), U3.8 (GND), U3.13 (GND), U3.18 (GND), U3.23 (GND), U3.28 (GND), U3.33 (AGND), U3.38 (GND), U4.4 (V-), U5.5 (GND), U6.3 (+), U6.5 (+), U7.3, U7.5, U7.8 (VSS)
I2C_SCK: J4.1, R7.2, U3.27 (GPIO21)
I2C_SDA: J4.2, R8.2, U3.26 (GPIO20)
unnamed: AS1.18 (CA), C13.1
unnamed: AS1.19 (CB), C14.2
unnamed: AS1.20 (CC), C15.1
unnamed: AS1.21 (CD), C16.1
unnamed: AS1.24 (Gain_Set), R16.2
unnamed: AS1.23, C11.1
unnamed: AS1.15 (VCF_Input), R17.1
unnamed: C11.2, R16.1
unnamed: C19.2, J3.T, R23.2, TP18.1, U6.1
unnamed: C20.2, J3.R, R24.2, TP19.1, U6.7
unnamed: C27.1, R17.2
unnamed: D1.2 (A), J2.5, U5.3 (C2)
unnamed: D1.1 (K), R13.2, U5.2 (C1)
unnamed: D2.2 (A), R18.2, R37.1
unnamed: D3.2 (A), U10.2 (GND)
unnamed: C37.1, D4.2 (A), U10.3 (VO)
unnamed: D5.2 (A), R48.2, R50.1
unnamed: D6.2 (A), R52.2, R54.1
unnamed: J2.4, R13.1
unnamed: Q3.1 (D), R34.1
unnamed: Q5.1 (D), R33.1
unnamed: R25.1, U7.6
unnamed: R26.1, U7.12
unnamed: R28.1, U7.10
unnamed: R30.1, U7.15
unnamed: R33.2, R46.1
unnamed: R34.2, R45.1
unnamed: R38.2, R40.1, R41.2
unnamed: R42.2, R43.1
unnamed: C2.1, U1.2 (CAP+)
unnamed: C2.2, U1.4 (CAP-)
unnamed: R21.1, TP2.1, U4.1, U4.2 (-)
unnamed: R20.1, TP1.1, U4.6 (-), U4.7
unnamed: R19.1, U5.7 (VO1)
unnamed: R14.2, R15.2, R35.1, U8.3 (+)
unnamed: R18.1, R36.1, U8.2 (-)
unnamed: C4.2, R1.2, R2.2, U8.5 (+)
unnamed: C8.1, R6.2, U9.3 (+)
unnamed: R42.1, R44.1, U9.2 (-)
unnamed: C7.1, R5.2, U9.5 (+)
unnamed: R38.1, R39.1, U9.6 (-)
unnamed: C36.1, R47.1, U11.3 (+)
unnamed: R48.1, R49.1, U11.2 (-)
unnamed: C40.1, R51.1, U11.5 (+)
unnamed: R52.1, R53.1, U11.6 (-)
Output_VCA_L: AS1.26 (VCA_L), C19.1, R23.1, U6.2 (-)
Output_VCA_R: AS1.27 (VCA_R), C20.1, R24.1, U6.6 (-)
PULSE_PIO_FREQ_A: Q4.2 (G), TP16.1, U3.25 (GPIO19)
PULSE_PIO_FREQ_B: Q2.2 (G), TP17.1, U3.12 (GPIO9)
PWM_3.3V_BALANCE_CV: R6.1, U3.6 (GPIO4)
PWM_3.3V_FITLER_FREQ_CV: R5.1, U3.10 (GPIO7)
PWM_3.3V_LINEAR_GAIN_CV: U3.7 (GPIO5), U7.14
PWM_3.3V_MOD_AMOUNT_CV: U3.2 (GPIO1), U7.11
PWM_3.3V_PAN_CV: U3.1 (GPIO0), U7.7
PWM_3.3V_PULSE_WIDTH_A_C.V: R47.2, U3.4 (GPIO2)
PWM_3.3V_PULSE_WIDTH_B_C.V: R51.2, U3.5 (GPIO3)
PWM_3.3V_RESONANCE_CV: U3.9 (GPIO6), U7.9
PWM_5V_BALANCE_CV: AS1.16 (Balance_C.V.), R44.2, TP11.1, U9.1
PWM_5V_FITLER_FREQ_CV: AS1.22 (Filter_Freq_C.V.), R39.2, TP10.1, U9.7
PWM_5V_LINEAR_GAIN_CV: AS1.25 (Linear_Gain_C.V.), C26.1, R30.2, TP9.1
PWM_5V_MOD_AMOUNT_CV: AS1.13 (Modulation_Amount_C.V.), C22.1, R26.2, TP5.1
PWM_5V_PAN_CV: AS1.2 (Pan_C.V.), C21.1, R25.2, TP4.1
PWM_5V_RESONANCE_CV: AS1.17 (Resonance_C.V.), C24.1, R28.2, TP7.1
PWM_DAC_PULSE_WIDTH_A: AS1.6 (Pulse_Witdh_A_C.V.), R49.2, TP6.1, U11.1
PWM_DAC_PULSE_WIDTH_B: AS1.8 (Pulse_Width_C.V.), R53.2, TP8.1, U11.7
RTA: AS1.4 (RTA), R11.2, R45.2
RTB: AS1.10 (RTB), R12.2, R46.2
RX: R22.2, U3.22 (GPIO17), U5.6 (VO2)
V_WF_A: AS1.3 (Wave-Shape_A_C.V.), C6.2, R3.2, R4.2, TP14.1
V_WF_A_LSB_PWM: R4.1, U3.15 (GPIO11)
V_WF_A_MSB_PWM: R3.1, U3.14 (GPIO10)
V_WF_B: AS1.12 (Wave-shape_B_C.V.), C10.2, R9.2, R10.2, TP15.1
V_WF_B_LSB_PWM: R10.1, U3.17 (GPIO13)
V_WF_B_MSB_PWM: R9.1, U3.16 (GPIO12)
WS_BIT0: R14.1, U3.21 (GPIO16)
WS_BIT1: R15.1, U3.29 (GPIO22)
Wave_Select_CV: AS1.7 (Wave_Select_C.V.), R36.2, TP12.1, U8.1

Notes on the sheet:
16 bits PWM
Compatible op-amp TCL2262 or TLV9102 TLV2372
Registers change
-5V rail (from 5V)
5V Rail
POWER +12V, +5V, -5V
0V to 5V
Pulse Width Control Voltage
DCO charge condensator DCO ramp to ADC
AS3397
Wave Select
MIDI IN
DC Power Input
12V Rail
-0.7V , 0.5V, 2V, 3V
level shifter PWM low-pass filtering
Filter CutOff/Resonance Control Voltage
Pi pico (rp2040)
3.3V -> 5V
-0.5V to 5V
Audio output (transimpedance opAmp)
-2.5V to 2.5V
-2.5V to 5V


Board: 2 copper layers, 167.6 x 97.5 mm, 142 parts (0 on the bottom side), 94 nets.

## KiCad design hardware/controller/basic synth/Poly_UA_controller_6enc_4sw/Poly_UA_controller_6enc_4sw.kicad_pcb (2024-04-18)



Board: 2 copper layers, 110.3 x 73.5 mm, 29 parts (11 on the bottom side), 31 nets.

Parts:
C1, C2, C4, C5, C6, C7: 100n; C_1206_3216Metric_Pad1.33x1.80mm_HandSolder
C3: C; C_1206_3216Metric_Pad1.33x1.80mm_HandSolder
D1, D2, D3, D4, D5, D6: SK6812; LED_SK6812_PLCC4_5.0x5.0mm_P3.2mm
J8_POLY1: Conn_Env; PinHeader_2x05_P2.54mm_Vertical
R1, R2: 4K7; R_1206_3216Metric_Pad1.30x1.75mm_HandSolder
R3, R4, R5, R6, R7, R8: 0; R_1206_3216Metric_Pad1.30x1.75mm_HandSolder
SW1, SW2, SW3, SW4, SW5, SW6: RotaryEncoder_Switch; RotaryEncoder_Alps_EC11E-Switch_Vertical_H20mm
U1: MCP23017_SO; SOIC-28W_7.5x17.9mm_P1.27mm

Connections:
GND: C1.1, C2.1, C3.1, C4.1, C5.1, C6.1, C7.1, D1.1 (VSS), D2.1 (VSS), D3.1 (VSS), D4.1 (VSS), D5.1 (VSS), D6.1 (VSS), J8_POLY1.7, R4.2, R7.2, R8.2, SW1.C, SW1.S2, SW2.C, SW2.S2, SW3.C, SW3.S2, SW4.C, SW4.S2, SW5.C, SW5.S1, SW6.C, SW6.S1, U1.10 (VSS)
LED_DATA_IN: D1.2 (DIN), J8_POLY1.2
LED_POWER: C1.2, C2.2, C4.2, C5.2, C6.2, C7.2, D1.3 (VDD), D2.3 (VDD), D3.3 (VDD), D4.3 (VDD), D5.3 (VDD), D6.3 (VDD), J8_POLY1.8
MCP23017_IRQ: J8_POLY1.1, U1.19 (INTB)
unnamed: D1.4 (DOUT), D2.2 (DIN)
unnamed: D2.4 (DOUT), D3.2 (DIN)
unnamed: D3.4 (DOUT), D4.2 (DIN)
unnamed: D4.4 (DOUT), D5.2 (DIN)
unnamed: D5.4 (DOUT), D6.2 (DIN)
unnamed: R6.2, R8.1, U1.15 (A0)
unnamed: R3.2, R4.1, U1.16 (A1)
unnamed: R5.2, R7.1, U1.17 (A2)
R1_A: SW1.A, U1.26 (GPA5)
R1_B: SW1.B, U1.25 (GPA4)
R2_A: SW2.A, U1.27 (GPA6)
R2_B: SW2.B, U1.28 (GPA7)
R3_A: SW3.A, U1.5 (GPB4)
R3_B: SW3.B, U1.4 (GPB3)
R4_A: SW4.A, U1.2 (GPB1)
R4_B: SW4.B, U1.3 (GPB2)
R5_A: SW5.A, U1.23 (GPA2)
R5_B: SW5.B, U1.22 (GPA1)
R6_A: SW6.A, U1.8 (GPB7)
R6_B: SW6.B, U1.7 (GPB6)
SCK: J8_POLY1.9, R2.1, U1.12 (SCK)
SDA: J8_POLY1.10, R1.2, U1.13 (SDA)
SW_1: SW1.S1, U1.24 (GPA3)
SW_4: SW4.S1, U1.1 (GPB0)
SW_5: SW5.S2, U1.21 (GPA0)
SW_6: SW6.S2, U1.6 (GPB5)
VCC: C3.2, J8_POLY1.6, R1.1, R2.2, R3.1, R5.1, R6.1, U1.9 (VDD), U1.18 (~RESET)

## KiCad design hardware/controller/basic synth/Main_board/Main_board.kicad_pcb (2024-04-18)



Board: 2 copper layers, 77.2 x 76.1 mm, 14 parts (11 on the bottom side), 30 nets.

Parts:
Brd1: SSD1306; 128x64OLED
J1: USB_B; USB_B_OST_USB-B1HSxx_Horizontal
J1_VCO_A1: Conn_VCO_A; PinHeader_2x05_P2.54mm_Vertical
J2_VCO_B1: Conn_VCO_B; PinHeader_2x05_P2.54mm_Vertical
J3: Conn_01x04_Socket; NS-Tech_Grove_1x04_P2mm_Vertical
J3_Filter1: Conn_Filter; PinHeader_2x05_P2.54mm_Vertical
J4_VCA1: Conn_VCA; PinHeader_2x05_P2.54mm_Vertical
J5_Env1, J6_LFO1, J7_DSO1, J8_POLY1: Conn_Env; PinHeader_2x05_P2.54mm_Vertical
Q1: BS170F; SOT-23
SW2: RotaryEncoder_Switch; RotaryEncoder_Alps_EC11E-Switch_Vertical_H20mm
U1: Pico; RPi_Pico_SMD_TH

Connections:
3V3: Brd1.2 (VCC), J1_VCO_A1.6, J2_VCO_B1.6, J3.2, J3_Filter1.6, J4_VCA1.6, J5_Env1.6, J6_LFO1.6, J7_DSO1.6, J8_POLY1.6, U1.36 (3V3)
ADC_CUTOFF: J3_Filter1.4, U1.31 (GPIO26_ADC0)
ADC_Resonance: J3_Filter1.5, U1.32 (GPIO27_ADC1)
ENC_PRESET_A: SW2.A, U1.26 (GPIO20)
ENC_PRESET_B: SW2.B, U1.27 (GPIO21)
GND: Brd1.1 (GND), J1.4 (GND), J1.5 (Shield), J1_VCO_A1.7, J2_VCO_B1.7, J3.1, J3_Filter1.7, J4_VCA1.7, J5_Env1.7, J6_LFO1.7, J7_DSO1.7, J8_POLY1.7, SW2.C, SW2.S2, U1.3 (GND), U1.8 (GND), U1.13 (GND), U1.18 (GND), U1.23 (GND), U1.28 (GND), U1.33 (AGND), U1.38 (GND)
IC0_SCL: Brd1.3 (SCL), J1_VCO_A1.9, J2_VCO_B1.9, J3_Filter1.9, J4_VCA1.9, J5_Env1.9, J6_LFO1.9, J7_DSO1.9, J8_POLY1.9, U1.2 (GPIO1)
IC0_SDA: Brd1.4 (SDA), J1_VCO_A1.10, J2_VCO_B1.10, J3_Filter1.10, J4_VCA1.10, J5_Env1.10, J6_LFO1.10, J7_DSO1.10, J8_POLY1.10, U1.1 (GPIO0)
IC1_SCL: J3.4, U1.5 (GPIO3)
IC1_SDA: J3.3, U1.4 (GPIO2)
INT_A: J1_VCO_A1.1, U1.6 (GPIO4)
INT_B: J2_VCO_B1.1, U1.7 (GPIO5)
INT_C: J3_Filter1.1, U1.9 (GPIO6)
INT_D: J4_VCA1.1, U1.10 (GPIO7)
INT_E: J5_Env1.1, U1.11 (GPIO8)
INT_F: J6_LFO1.1, U1.12 (GPIO9)
INT_G: J7_DSO1.1, U1.14 (GPIO10)
INT_H: J8_POLY1.1, U1.15 (GPIO11)
LED_A: J1_VCO_A1.2, U1.16 (GPIO12)
LED_B: J2_VCO_B1.2, U1.17 (GPIO13)
LED_C: J3_Filter1.2, U1.19 (GPIO14)
LED_D: J4_VCA1.2, U1.20 (GPIO15)
LED_E: J5_Env1.2, U1.21 (GPIO16)
LED_F: J6_LFO1.2, U1.22 (GPIO17)
LED_G: J7_DSO1.2, U1.24 (GPIO18)
LED_H: J8_POLY1.2, U1.25 (GPIO19)
LED_POWER: J1.1 (VBUS), J1_VCO_A1.8, J2_VCO_B1.8, J3_Filter1.8, J4_VCA1.8, J5_Env1.8, J6_LFO1.8, J7_DSO1.8, J8_POLY1.8, Q1.2 (S)
unnamed: Q1.1 (G), U1.40 (VBUS)
SWITCH_ENCODER: SW2.S1, U1.29 (GPIO22)
VBUS: Q1.3 (D), U1.39 (VSYS)

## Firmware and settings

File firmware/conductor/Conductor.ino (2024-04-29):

/*

                           ,--,                                  ,---,                                     ,--,
   ,-.----.              ,--.'|                         ,--,    '  .' \                                  ,--.'|
   \    /  \     ,---.   |  | :                       ,'_ /|   /  ;    '.           ,---,                |  | :       ,---.
   |   :    |   '   ,'\  :  : '                  .--. |  | :  :  :       \      ,-+-. /  |               :  : '      '   ,'\    ,----._,.
   |   | .\ :  /   /   | |  ' |          .--,  ,'_ /| :  . |  :  |   /\   \    ,--.'|'   |    ,--.--.    |  ' |     /   /   |  /   /  ' /
   .   : |: | .   ; ,. : '  | |        /_ ./|  |  ' | |  . .  |  :  ' ;.   :  |   |  ,"' |   /       \   '  | |    .   ; ,. : |   :     |
   |   |  \ : '   | |: : |  | :     , ' , ' :  |  | ' |  | |  |  |  ;/  \   \ |   | /  | |  .--.  .-. |  |  | :    '   | |: : |   | .\  .
   |   : .  | '   | .; : '  : |__  /___/ \: |  :  | | :  ' ;  '  :  | \  \ ,' |   | |  | |   \__\/: . .  '  : |__  '   | .; : .   ; ';  |
   :     |`-' |   :    | |  | '.'|  .  \  ' |  |  ; ' |  | '  |  |  '  '--'   |   | |  |/    ," .--.; |  |  | '.'| |   :    | '   .   . |
   :   : :     \   \  /  ;  :    ;   \  ;   :  :  | : ;  ; |  |  :  :         |   | |--'    /  /  ,.  |  ;  :    ;  \   \  /   `---`-'| |
   |   | :      `----'   |  ,   /     \  \  ;  '  :  `--'   \ |  | ,'         |   |/       ;  :   .'   \ |  ,   /    `----'    .'__/\_: |
   `---'.|                ---`-'       :  \  \ :  ,      .-./ `--''           '---'        |  ,     .-./  ---`-'               |   :    :
     `---`                              \  ' ;  `--`----'                                   `--`---'                            \   \  /
                                         `--`                                                                                    `--`-'
  
    A Polyphonic Analogic and Open Source Synthesizer

    https://github.com/PhysicsDptAngers/polyUAnalog

    M. Loumaigne 
    D. Guichaoua

    2023 - 2024 - Université d'Angers

    Orchestra conductor card

    v2.1
    - Multicast I2C transfert only
    - Optimize I2C preset transfert
    - Adding multitimbral function
    - Adding preset function

    To do
    - Adding preset transfert by SysEx
    - Adding second I2C interface control
    - One byte control change possibility

*/
#include <Wire.h>
#include <MIDI.h>
#include "preset.h"   // Include the header file containing presets

// Define the I2C clock frequency in Hz
#define I2CclockFreq 400000

// Define the I2C address used for communication
#define I2CAddress 0x10

// Create an instance of a MIDI object associated with Serial1
// This allows MIDI communication over the specified hardware serial port
MIDI_CREATE_INSTANCE(HardwareSerial, Serial1, MIDI);


// MIDI message types
#define NoteOff 0x80
#define NoteOn 0x90
#define Aftertouch 0XA0
#define CtrChange 0xB0
#define ProgramChange 0xC0
#define ChannelPressure 0xD0
#define PitchBend 0xE0

#define GLBDETUNE 104
//Whell Mod
#define WHEEL 1
//LOW PASS FILTER
#define FILTERFC 74
#define FILTERFCLOW 75
#define DEFAULTCONF 121

#define ADR 0x10

#define MAXVOICES 16

// Enumerate the different states of an ADSR (Attack, Decay, Sustain, Release) envelope
enum ADSRState {
  ATTACK,   // Attack phase of the envelope
  DECAY,    // Decay phase of the envelope
  SUSTAIN,  // Sustain phase of the envelope
  RELEASE,  // Release phase of the envelope
  NOTEOFF   // State indicating the note is turned off
};

// Define a structure to represent a voice in the synthesizer
struct listvoices {
  byte adr = ADR;       // I2C address of the voice (initialized to default ADR)
  ADSRState state = NOTEOFF;  // Current state of the voice (initialized to NOTEOFF)
  int note = -1;         // MIDI note number being played (-1 indicates no note is assigned)
  uint32_t count = 0;    // Counter used for voice management and priority
};


// Create an IntervalTimer object
IntervalTimer myTimer;

byte nVoices = 0;           // Number of active voices currently playing
struct listvoices voices[MAXVOICES];  // Array to store information about each voice
uint32_t counter = 0;       // Counter used for voice management and priority

bool blink = false;         // Flag to indicate if a visual blink effect should occur
bool MonoMode = false;      // Flag to indicate monophonic (true) or polyphonic (false) mode

byte controlValue[256];     // Array to store control values for MIDI parameters

// Function to load a preset into the synthesizer
void loadPreset(byte presetNumber) {
  // Checks if the preset number is valid
  if (presetNumber >= sizeof(Presets) / sizeof(Presets[0])) {
    // Check if preset number is out of range
    return;
  }

  const uint8_t* preset = Presets[presetNumber];  // Get the preset data from the Presets array

  Wire.beginTransmission(0);  // Begin transmission over I2C to address 0
  for (uint j = 0; j < NBPARAM; j += 2) {
    controlValue[preset[j]] = preset[j + 1];  // Set control values based on the preset data
    Wire.write(CtrChange);    // Send MIDI control change message
    Wire.write(preset[j]);    // Send MIDI control number
    Wire.write(preset[j + 1]); // Send MIDI control value
    blink = true;              // Set blink flag to indicate a change
  }
  Wire.endTransmission();  // End I2C transmission
}

// Function to obtain the controller name from its number
const char* obtenirNomDuControleur(byte numero) {
  for (byte i = 0; i < sizeof(controlleurNum); i++) {
    if (controlleurNum[i] == numero) return controlleurNom[i];  // Return the controller name if found
  }
  return "";  // Return an empty string if controller number is not found
}

// Function to display the current presets stored in memory
void printPreset(void) {
  byte i;
  Serial.print("const uint8_t Preset1[] = { ");
  for (i = 0; i < (sizeof(controlleurNum) - 1); i++) {
    if (i % 4 == 0) Serial.println("  ");  // Print new line for better formatting
    Serial.printf("%s, %d, ", controlleurNom[i], controlValue[controlleurNum[i]]);  // Print controller name and value
  }
  Serial.printf("%s, %d\n", controlleurNom[i], controlValue[controlleurNum[i]]);  // Print last controller name and value
  Serial.println("};");  // Print end of preset array
}

// Function to handle MIDI Note On event
void OnNoteOn(byte channel, byte note, byte velocity) {
  uint32_t idx;
  byte voicefree = 255;

  if (MonoMode) {
    // Send Note On message via I2C if in monophonic mode
    sendI2c(0, NoteOn, note + channel, velocity);
    blink = true;  // Set blink flag to indicate a change
  } else {
    // Check if a channel is already playing the note; if so, return
    for (int i = 0; i < nVoices; i++) {
      if (voices[i].note == note) {
        return;
      }
    }
    // Look for a free voice to play the note
    for (int i = 0; i < nVoices; i++) {
      Wire.requestFrom((int)voices[i].adr, 1);
      while (Wire.available()) {
        voices[i].state = (ADSRState)Wire.read();  // Update voice state from I2C
      }
      if (voices[i].state == NOTEOFF) {
        // Assign the free voice to play the note
        voices[i].state = ATTACK;
        voices[i].note = note;
        counter++;
        voices[i].count = counter;
        // Send Note On message via I2C
        sendI2c(voices[i].adr, NoteOn + channel, note, velocity);
        blink = true;  // Set blink flag to indicate a change
        return;
      }
    }
    // Search for the oldest channel in RELEASE state to reassign
    idx = counter + 1;
    for (int i = 0; i < nVoices; i++) {
      if ((voices[i].state != RELEASE) && (idx > voices[i].count)) {
        idx = voices[i].count;
        voicefree = i;
      }
    }
    if (voicefree == 255) {
      // Search for the oldest voice if no free voices found
      for (int i = 0; i < nVoices; i++) {
        if (idx > voices[i].count) {
          idx = voices[i].count;
          voicefree = i;
        }
      }
    }
    if (voicefree < nVoices) {
      // Assign the free voice to play the note
      voices[voicefree].state = ATTACK;
      voices[voicefree].note = note;
      counter++;
      voices[voicefree].count = counter;
      // Send Note On message via I2C
      sendI2c(voices[voicefree].adr, NoteOn + channel, note, velocity);
      blink = true;  // Set blink flag to indicate a change
    }
  }
}

// Function to handle MIDI Note Off event
void OnNoteOff(byte channel, byte note, byte velocity) {
  if (MonoMode) {
    // Send Note Off message via I2C if in monophonic mode
    sendI2c(0, NoteOff + channel, note, velocity);
    blink = true;  // Set blink flag to indicate a change
  } else {
    // Check each voice for the note to turn off
    for (int i = 0; i < nVoices; i++) {
      Wire.requestFrom((int)voices[i].adr, 1);
      while (Wire.available()) {
        voices[i].state = (ADSRState)Wire.read();  // Update voice state from I2C
      }
      if (voices[i].note == note) {
        // Reset note and change voice state to RELEASE if not already released or turned off
        voices[i].note = -1;
        if ((voices[i].state != RELEASE) && (voices[i].state != NOTEOFF)) {
          voices[i].state = RELEASE;
          counter++;
          voices[i].count = counter;
          // Send Note Off message via I2C
          sendI2c(voices[i].adr, NoteOff + channel, note, velocity);
          blink = true;  // Set blink flag to indicate a change
        }
      }
    }
  }
}

// Function to handle MIDI Control Change events
void OnControlChange(byte channel, byte controler, byte value) {
  controlValue[controler] = value;  // Update control value in array

  // Handle specific control change events based on controller number
  if (controler == GLBDETUNE) {
    // Apply detune to all active voices
    for (int i = 0; i < nVoices; i++) {
      if (value) {
        // Generate random detune value and send via I2C
        sendI2c(voices[i].adr, CtrChange + channel, GLBDETUNE, (rand() % value) / 2);
      } else {
        // Send zero detune value if controller value is zero
        sendI2c(voices[i].adr, CtrChange + channel, GLBDETUNE, 0);
      }
      blink = true;  // Set blink flag to indicate a change
    }
  } else if (controler == WHEEL) {
    int Cutoff = value << 7;  // Shift value for cutoff frequency control

    // Send cutoff frequency control message via I2C
    sendI2c(0, CtrChange + channel, FILTERFCLOW, Cutoff & 0x7F);
    sendI2c(0, CtrChange + channel, FILTERFC, Cutoff >> 7);
    blink = true;  // Set blink flag to indicate a change

  } else if (controler == DEFAULTCONF) {
    // Load preset based on the controller value
    loadPreset(value);
  } else if (controler <= 124) {
    // Send general control change message via I2C for controllers <= 124
    sendI2c(0, CtrChange + channel, controler, value);
    blink = true;  // Set blink flag to indicate a change

  } else if (controler == 126) {
    // Set synthesizer to monophonic operation
    MonoMode = true;
    // Turn off all sounds (All Notes Off)
    OnControlChange(channel, 120, 0);
  } else if (controler == 127) {
    // Set synthesizer to polyphonic operation
    MonoMode = false;
    // Turn off all sounds (All Notes Off)
    OnControlChange(channel, 120, 0);
  }
}

// Function to handle MIDI Pitch Change events
void OnPitchChange(byte channel, int pitch) {
  for (int i = 0; i < nVoices; i++) {
    // Send pitch bend message via I2C to each active voice
    sendI2c(voices[i].adr, PitchBend + channel, pitch >> 7, pitch & 0x7F);
    blink = true;  // Set blink flag to indicate a change
  }
}


// Function: sendI2c
// Description: Sends a custom MIDI-like message via I2C to a specified address
// Parameters:
//   - address: The I2C address of the target device
//   - midicode: The MIDI-like command code to be sent
//   - value1: The first value (data byte) associated with the command
//   - value2: The second value (data byte) associated with the command (16-bit value)
void sendI2c(byte address, byte midicode, byte value1, int value2) {
  // Begin an I2C transmission to the specified address
  Wire.beginTransmission(address);

  // Send the MIDI-like command code (midicode) over I2C
  Wire.write(midicode);

  // Send the first value (data byte) over I2C
  Wire.write(value1);

  // Send the second value (16-bit data) over I2C
  // Note: The value2 parameter is split into two bytes for transmission
  Wire.write((byte)(value2 & 0xFF));    // Send the low byte (LSB) of value2
  Wire.write((byte)((value2 >> 8) & 0xFF));  // Send the high byte (MSB) of value2

  // End the I2C transmission
  Wire.endTransmission();
}


// Function: scanVoices
// Description: Scans for connected voices/modules via I2C communication and retrieves their state
void scanVoices() {
  byte address = 0;

  // Iterate over possible I2C addresses to scan for connected voices/modules
  for (int i = 0; i < MAXVOICES; i++) {
    address = ADR + i;  // Calculate the I2C address to scan
    Wire.beginTransmission(address);
    byte error = Wire.endTransmission();

    // Check if the device at the current address responded without errors (error code 0)
    if (error == 0) {
      // Print information about the discovered voice/module
      Serial.print("Voice ");
      Serial.print(nVoices, DEC);
      Serial.print(" found at address 0x");
      Serial.print(address, HEX);
      voices[i].adr = address;  // Store the discovered address in the voices array

      // Request state information from the voice/module
      Wire.requestFrom((int)voices[i].adr, 1);
      while (Wire.available()) {
        voices[i].state = (ADSRState)Wire.read();  // Read and store the state
      }

      // Print the state of the discovered voice/module
      Serial.print(" State: ");
      switch (voices[i].state) {
        case ATTACK:
          Serial.print("ATTACK");
          break;
        case DECAY:
          Serial.print("DECAY");
          break;
        case SUSTAIN:
          Serial.print("SUSTAIN");
          break;
        case RELEASE:
          Serial.print("RELEASE");
          break;
        case NOTEOFF:
          Serial.print("NOTEOFF");
          break;
      }
      Serial.println("");
      ++nVoices;  // Increment the count of discovered voices
    } else if (error == 4) {
      // Handle unknown error (no response) at the current address
      Serial.print("Unknown error at address 0x");
      if (address < 16) {
        Serial.print("0");  // Print leading zero for addresses less than 16
      }
      Serial.println(address, HEX);
    }
  }

  // If no voices/modules were found, print a message indicating no devices were detected
  if (nVoices == 0) {
    Serial.println("No voices/modules found\n");
    // Perform action to turn all sounds off (reset)
    OnControlChange(0, 120, 0);
  }
}


// Function: i2cReceive
// Description: Handles incoming I2C data received by the device
// Parameters:
//   - bytesReceived: Number of bytes received (not explicitly used in this function)
void i2cReceive(int bytesReceived) {
  // Loop through all available bytes received via I2C
  while (Wire1.available()) {
    byte value = Wire1.read();  // Read the received byte
    OnMidi(value);  // Process the MIDI data based on the received byte
  }
  blink = true;  // Set blink flag to true for LED indication
}


// Function: i2cRequest
// Description: Placeholder function for handling I2C data requests (not implemented)
void i2cRequest() {
  // This function is currently empty and serves as a placeholder
  // for handling I2C data requests if needed in future development.
  // It can be implemented to respond to specific I2C data requests from master devices.
}


//---------------------
// MIDI I2C MANAGEMENT
//---------------------

// MIDI HANDLER DECLARATION
//------------------------------------------------
enum MidiMessageType {
  MIDI_OTHER,           // Other or unrecognized MIDI message
  MIDI_NOTE_OFF,        // MIDI Note Off message
  MIDI_NOTE_ON,         // MIDI Note On message
  MIDI_CONTROL_CHANGE,  // MIDI Control Change message
  MIDI_PROGRAM_CHANGE,  // MIDI Program Change message
  MIDI_PITCH_BEND       // MIDI Pitch Bend message
};


void OnMidi(uint8_t Midibyte) {
  static uint8_t midimode = MIDI_OTHER;   // Current MIDI message mode
  static int8_t midibytesleft = -1;       // Number of bytes left to read for the current MIDI message
  static uint8_t midibuffer[2];           // Buffer to store MIDI message data bytes
  static byte MidiChannel;                // MIDI channel associated with the incoming MIDI message

  //------------
  // STATUS BYTE
  //------------
  if (Midibyte >= 0x80) {  // Check if the received byte is a status byte (>= 128)
    if (Midibyte <= 0xEF) {
      MidiChannel = (Midibyte & 0x0F);    // Extract MIDI channel (lower 4 bits)
      Midibyte = Midibyte & 0xF0;         // Extract MIDI status type (upper 4 bits)
    }
    switch (Midibyte) {
      // MIDI NOTE OFF
      case 0x80:
        midimode = MIDI_NOTE_OFF;         // Set mode to MIDI Note Off
        midibytesleft = 2;                 // Two bytes (note and velocity) to read
        OnNoteOff(MidiChannel, 0, 0);      // Trigger Note Off action (channel, note, velocity)
        break;
      // MIDI NOTE ON
      case 0x90:
        midimode = MIDI_NOTE_ON;          // Set mode to MIDI Note On
        midibytesleft = 2;                 // Two bytes (note and velocity) to read
        break;
      // MIDI CONTROL CHANGE
      case 0xB0:
        midimode = MIDI_CONTROL_CHANGE;   // Set mode to MIDI Control Change
        midibytesleft = 2;                 // Two bytes (controller number and value) to read
        break;
      // MIDI PITCH-BEND
      case 0xE0:
        midimode = MIDI_PITCH_BEND;       // Set mode to MIDI Pitch Bend
        midibytesleft = 2;                 // Two bytes (LSB and MSB) to read
        break;
      default:
        midimode = MIDI_OTHER;            // Unknown status, reset mode
        midibytesleft = -1;               // No bytes left to read
        break;
    }
  }
  //------------------------
  // OTHERWISE DATA BYTES
  //------------------------
  else {
    // Store bytes to be read if necessary
    if (midibytesleft > 0) {              // Are there any bytes left to read?
      midibuffer[0] = midibuffer[1];      // Byte swap: shift previous byte to the first position
      midibuffer[1] = Midibyte;           // Store current byte in the buffer
      midibytesleft--;                    // Decrement the byte counter
    }
    // Process completed MIDI message
    if (midibytesleft == 0) {             // All bytes of the MIDI message have been received
      midibytesleft = -1;                 // Reset byte counter
      switch (midimode) {
        case MIDI_NOTE_OFF:
          //handleNoteOff(MidiChannel, midibuffer[0], midibuffer[1]);  // Handle Note Off event
          break;
        case MIDI_NOTE_ON:
          // Turn note off if velocity is zero, otherwise turn note on
          if (midibuffer[1] == 0) {
            OnNoteOff(MidiChannel, midibuffer[0], midibuffer[1]);
          } else if (midibuffer[1] != 0) {
            OnNoteOn(MidiChannel, midibuffer[0], midibuffer[1]);
          }
          break;
        case MIDI_CONTROL_CHANGE:
          OnControlChange(MidiChannel, midibuffer[0], midibuffer[1]);  // Handle Control Change event
          break;
        case MIDI_PITCH_BEND:
          OnPitchChange(MidiChannel, (midibuffer[0] << 7) + midibuffer[1]);  // Handle Pitch Bend event
          break;
        default:
          break;
      }
    }
  }
}
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
void loop() {
  usbMIDI.read();   // Read incoming USB MIDI messages
  MIDI.read();      // Read incoming MIDI messages
}

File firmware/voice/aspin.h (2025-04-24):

#ifndef ASPIN_H
#define ASPIN_H
// Définition des broches d'entrée sortie

#define VWFA_MSB_CV 10
#define VWFA_LSB_CV 11
#define VWFB_MSB_CV 12
#define VWFB_LSB_CV 13
#define DCOA_PW_CV 2
#define DCOB_PW_CV 3
#define BALANCE_CV 4

#define MOD_AMOUNT_CV 1
#define FILTER_FREQ_CV 7
#define FILTER_RES_CV 6

#define VCA_CV 5
#define PAN_CV 0

#define DSO_MSB 14
#define DSO_LSB 15

#define DCOA_FREQ 19
#define DCOB_FREQ 9
#define GAMME_A 18
#define GAMME_B 8

#define WS_BIT0 16
#define WS_BIT1 22

#define INPUT_RAMPE_A 0
#define INPUT_RAMPE_B 1

#define I2C_ADR_READ 2

#define MIDI_RX 17

// Définition des constantes pour le calcul de la rampe et de la fréquence
const float Rt = 13200;
const float Ct = 1.8E-9;
const uint8_t RampeDivisor = 4;
const float convFactor = (RampeDivisor * 3.3) / 4096;

//Gains du PI Kp et Ki
const float Kp = Rt * Ct * 16 * RampeDivisor;  //Le x16 c'est pour passer de 12bits (ADC In) à 16bits (PWM out)
const float Ki = 100;

// Définition des constantes pour le PWM
const int PWMRes = 256;
const int PWMResFilter = 16384;
const int PWMResVCA = 4096;

// Définition des constantes pour le Wave select control
#define WAVE_NONE 0
#define WAVE_A 1
#define WAVE_B 2
#define WAVE_AB 3

#endif

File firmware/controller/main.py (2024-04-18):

from machine import Pin, I2C, ADC, Timer
import rp2
from mcp23017 import MCP23017
from neopixel import Neopixel
from rotary import Rotary
import ssd1306
from Midi_CC import *
from time import sleep
import _thread

from param import Parameter, Osc_shape, Osc_pwm, level, Osc_pitch






# Initialize I2C for MCP23017
i2c = I2C(0, scl=Pin(1), sda=Pin(0))

# Initialize I2C for Midi over I2C
i2c_midi = I2C(1, scl=Pin(3), sda=Pin(2))

#Initialize OLED screen
display_oled = ssd1306.SSD1306_I2C(128, 64, i2c)


display_oled.fill(0)
display_oled.fill_rect(0, 0, 32, 32, 1)
display_oled.fill_rect(2, 2, 28, 28, 0)
display_oled.vline(9, 8, 22, 1)
display_oled.vline(16, 2, 22, 1)
display_oled.vline(23, 8, 22, 1)
display_oled.fill_rect(26, 24, 2, 4, 1)
display_oled.text('poyUAnalog', 40, 0, 1)
display_oled.text('v0.1', 40, 12, 1)
display_oled.text('04/2024', 40, 24, 1)
display_oled.show()




"""
# Initialize MCP23017 devices and configure interrupts
mcp_devices = []
for i in range(8):
    address = 0x20 + i
    mcp = MCP23017(i2c, address)
    mcp.config(interrupt_mirror=True, interrupt_polarity=1)
    mcp.mode = 0xFFFF  # Set all pins as inputs
    mcp.pullup = 0xFFFF  # Enable pull-ups on all pins
    mcp.interrupt_enable = 0xFFFF  # Enable interrupts on all pins
    mcp_devices.append(mcp)
"""
is_mcpA_plugged = False
try:
    address = 0x24	# Harcoded
    mcpA = MCP23017(i2c, address)
    mcpA.config(interrupt_mirror=True, interrupt_polarity=1)
    mcpA.mode = 0xFFFF  # Set all pins as inputs
    mcpA.pullup = 0xFFFF  # Enable pull-ups on all pins
    mcpA.interrupt_enable = 0xFFFF  # Enable interrupts on all pins
    is_mcpA_plugged = True
except Exception as e:
    # Si une exception est levée, le périphérique n'est pas présent
    print("Erreur lors de l'initialisation du MCP23017 A :", e)

is_mcpB_plugged = False
try:
    address = 0x21
    mcpB = MCP23017(i2c, address)
    mcpB.config(interrupt_mirror=True, interrupt_polarity=1)
    mcpB.mode = 0xFFFF  # Set all pins as inputs
    mcpB.pullup = 0xFFFF  # Enable pull-ups on all pins
    mcpB.interrupt_enable = 0xFFFF  # Enable interrupts on all pins
    is_mcpA_plugged = True
except Exception as e:
    # Si une exception est levée, le périphérique n'est pas présent
    print("Erreur lors de l'initialisation du MCP23017 B :", e)    
"""
address = 0x23
mcpC = MCP23017(i2c, address)
mcpC.config(interrupt_mirror=True, interrupt_polarity=1)
mcpC.mode = 0xFFFF  # Set all pins as inputs
mcpC.pullup = 0xFFFF  # Enable pull-ups on all pins
mcpC.interrupt_enable = 0xFFFF  # Enable interrupts on all pins
"""
"""
address = 0x24
mcpD = MCP23017(i2c, address)
mcpD.config(interrupt_mirror=True, interrupt_polarity=1)
mcpD.mode = 0xFFFF  # Set all pins as inputs
mcpD.pullup = 0xFFFF  # Enable pull-ups on all pins
mcpD.interrupt_enable = 0xFFFF  # Enable interrupts on all pins
"""
"""
address = 0x25
mcpE = MCP23017(i2c, address)
mcpE.config(interrupt_mirror=True, interrupt_polarity=1)
mcpE.mode = 0xFFFF  # Set all pins as inputs
mcpE.pullup = 0xFFFF  # Enable pull-ups on all pins
mcpE.interrupt_enable = 0xFFFF  # Enable interrupts on all pins
"""

# LFO
is_mcpF_plugged = False
try:
    address = 0x20
    mcpF = MCP23017(i2c, address)
    mcpF.config(interrupt_mirror=True, interrupt_polarity=1)
    mcpF.mode = 0xFFFF  # Set all pins as inputs
    mcpF.pullup = 0xFFFF  # Enable pull-ups on all pins
    mcpF.interrupt_enable = 0xFFFF  # Enable interrupts on all pins
    is_mcpF_plugged = True
except Exception as e:
    # Si une exception est levée, le périphérique n'est pas présent
    print("Erreur lors de l'initialisation du MCP23017 B :", e)       

"""
address = 0x27
mcpG = MCP23017(i2c, address)
mcpG.config(interrupt_mirror=True, interrupt_polarity=1)
mcpG.mode = 0xFFFF  # Set all pins as inputs
mcpG.pullup = 0xFFFF  # Enable pull-ups on all pins
mcpG.interrupt_enable = 0xFFFF  # Enable interrupts on all pins
"""

"""
address = 0x28
mcpH = MCP23017(i2c, address)
mcpH.config(interrupt_mirror=True, interrupt_polarity=1)
mcpH.mode = 0xFFFF  # Set all pins as inputs
mcpH.pullup = 0xFFFF  # Enable pull-ups on all pins
mcpH.interrupt_enable = 0xFFFF  # Enable interrupts on all pins
"""
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

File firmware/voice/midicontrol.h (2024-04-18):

#ifndef MIDICTRL_H
#define MIDICTRL_H

//Whell Mod
#define WHEEL 1

//OSCILLATOR 1
#define OSC1WAVE 9
#define OSC1TRANSPOSE 10
#define OSC1PWM 11
#define OSC1DETUNE 18

//OSCILLATOR 2
#define OSC2WAVE 12
#define OSC2TRANSPOSE 13
#define OSC2DETUNE 14
#define OSC2PWM 15

//MIXER
#define BALANCE 16

//DSO
#define DSOWAVE 38
#define DSOTRANSPOSE 39
#define DSODETUNE 40
#define DSOPW 41
#define DSOMIX 42
#define MIXNOISE 44 

//ENVELOPPE GENERATOR 1
#define EG1ATTACK 19
#define EG1DECAY 20
#define EG1SUSTAIN 21
#define EG1RELEASE 22
//ENVELOPPE GENERATOR 2
#define EG2ATTACK 23
#define EG2DECAY 24
#define EG2SUSTAIN 25
#define EG2RELEASE 26
#define EG22FREQ 51

//LOW PASS FILTER
#define FILTERFC 74
#define FILTERFCLOW 75
#define FILTERRES 27
#define FILTERKEY 28
#define FILTERENV 29
#define MODAMOUNT 37

//LOW FREQUENCY OSCILLATOR 1
#define LFO1WAVE 30
#define LFO1FREQ 31
#define LFO12PWA 35
#define LFO12PWB 36
#define LFO12FREQ 85
#define LFO12FILTER 86
#define LFO12PWDSO 43
#define LFO12PAN 45 

//Velocity
#define VEL2VCA 46
#define VEL2FILTER 47

//Pan
#define KEY2PAN 48

//After Touch
#define AFT2VCA 49
#define AFT2FILTER 50

//GLOBAL PARAMETERS
#define GLBDETUNE 104
#define GLBTRANSPOSE 105
#define GLBVELOCITY 106
#define GLBVOLUME 7
#define GLBGLIDE 5
#define PAN 32

#define ALLSOUNDOFF 120
#define ALLNOTESOFF 123

#endif

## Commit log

2024-04-25 Better documentation
    [AS3397_proto_SMS.kicad_sch, LightGuide.scad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]
2024-04-26 Draft Article without todo list in french
    [AS3397_proto_SMS.kicad_sch]
2024-05-06 DCO documentation - Waveshapper, Square wave
    [AS3397_proto_SMS.kicad_sch]
2025-03-17 Voice PCB directory cleanup
    [AS3397_eurorack_0603.kicad_pcb, AS3397_eurorack_0603.kicad_sch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]
2025-03-17 Voice PCB directory cleanup bis
    [AS3397_eurorack_0603.kicad_pcb, AS3397_eurorack_0603.kicad_sch]
2025-03-25 Power board
    [AS3397_eurorack_0603.kicad_pcb, powerBoard.kicad_pcb, powerBoard.kicad_sch]
2025-03-25 hardware readme
    [powerBoard-B_Cu.gbl, powerBoard-B_Mask.gbs, powerBoard-B_Paste.gbp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]
2025-04-08 Through hole voice board first commit
    [AS3397_proto_DIP-B_Cu.gbl, AS3397_proto_DIP-B_Mask.gbs, AS3397_proto_DIP-B_Paste.gbp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]
2025-04-24 Voice firmware big improvement and through hole board fixes
    [AS3397_proto_DIP.kicad_pcb, AS3397_proto_DIP.kicad_sch]
2026-01-16 Conductor board new version
    [AS3397-Conductor-B_Cu.gbl, AS3397-Conductor-B_Mask.gbs, AS3397-Conductor-B_Paste.gbp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]
2026-01-22 Fixing routing power rail in conductor board
    [AS3397-Conductor.kicad_pcb]
2026-01-23 Conductor Board : Fixing MIDI routing
2026-03-04 Modif of voice board smd and Cleanup
    [AS3397-Conductor-B_Cu.gbl, AS3397-Conductor-B_Mask.gbs, AS3397-Conductor-B_Paste.gbp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]
